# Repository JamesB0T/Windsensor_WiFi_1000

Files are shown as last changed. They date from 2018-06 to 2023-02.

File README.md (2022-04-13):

## The Windsensor WiFi 1000 is an OpenSource project to build a wind transducer for sailboats using 3D printer parts and an ESP8266 microcontroller

My wind transducer got damaged in winter 2017/2018 by a big storm in Netherlands. I needed a new transducer for my small sailboat. It is a Dehlya 22. At the same time I was looking for an interesting and useful project for my new 3D printer. At first I tried to build the hemispheric parts and the rotor. After successful 3D printing I was amazed about the good quality and mechanical precision. My printer is a low cost Chinese model JGAurora in prusa design. At this point I started my project with the windsensor and I designed all parts in 3D for my printer.

For designing I use the online CAD program [Onshape](https://www.onshape.com). It is easy, powerfull and innovative. You just need a PC and a web browser with 3D function (Web GL). You find my project under the term "windsensor". Copy it to your own workplace so you can view and modify the 3D model.

This windsensor is based on a [patent](Patents/US5231876.pdf) from Peet Bros Inc. The patent has expired and everyone can use it. The function is very simple using two reed magnet sensors to detect wind speed and wind direction.

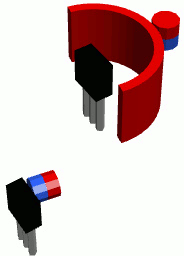
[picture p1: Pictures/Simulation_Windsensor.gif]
Mechanical Function


I modified the circuit and used two hall sensors instead. An ESP8266-E12 microcontroller processes readings from both sensors and calculates wind speed and wind direction. The operating principle is amazingly simple and smart. It is a perfect combination of simplicity and effectiveness and poses an attractive task for the ESP8266 microcontroller.

If you like to help or consider this project useful, please donate. Thanks for your support!

Donate (https://www.paypal.com/cgi-bin/webscr?cmd=_s-xclick&hosted_button_id=5QZJZBM252F2L)

For a first impression see the videos:

[Live Windsensor](https://www.youtube.com/watch?v=ME7WqSQ8mfY) 

[Display data in OpenPlotter](https://www.youtube.com/watch?v=0nfqlGNmgYI) 

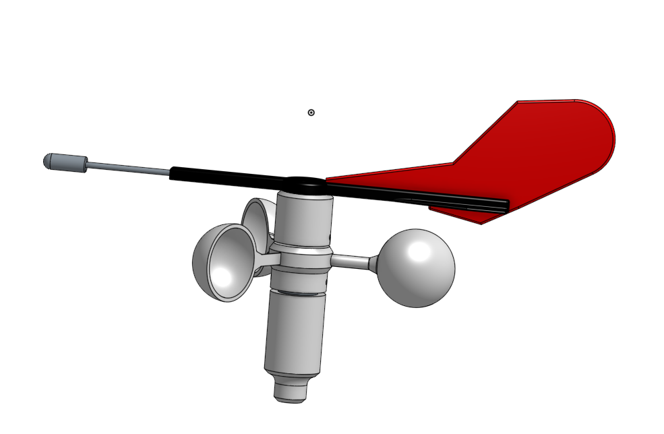
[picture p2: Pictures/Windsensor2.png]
Windsensor


I published and discussed this project in the German sailing forum [www.segeln-forum.de](https://www.segeln-forum.de/board1-rund-ums-segeln/board35-bootstechnik-und-elektronik/67401-windsensor-diy/) and found many interested people. Half a year later, all mechanical components and electrical schematics were completed and I successfully launched the first windsensor on my sailboat.

## These were the initial requirements for the new windsensor:

* Measuring wind speed and wind direction
* Robust mechanics
* Weight < 200g
* Small enough for a 22 feet sailboat
* Weatherproof and UV stable
* Visible by night
* No cabling for sensor signals
* Digital signal transmission with WiFi only
* 12V power supply utilizing top light power cable
* Using a ESP8266 for WiFi and data handling
* Update rate approx. 1...2 samples per second
* No onboard instrument required
* Visualisation in OpenPlotter via laptop, mobile fone or tablett
* No extra software required (display is the browser)
* Supporting  NMEA 0183 protocol
* Price < 250 Euro

## How can I use it?

I use the windsensor in combination with [OpenPlotter](http://www.sailoog.com/openplotter) on a Raspberry Pi 3B. OpenPlotter serves as access point for WiFi devices. The windsensor connects to OpenPlotter via WiFi and transmits the NMEA0183 data telegrams every second. The windsensor sends 4 types of telegrams. 3 standard telegrams (MWV, VWR, VPW) and one custom telegram (INF). Check here [link](http://www.nmea.de/nmea0183datensaetze.html) for more information on NMEA0183. 

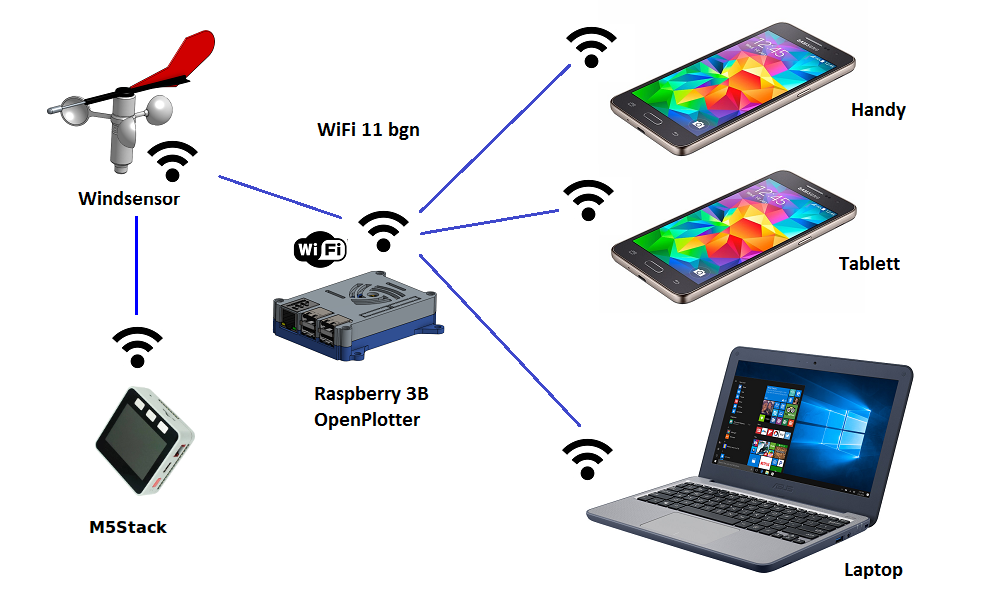
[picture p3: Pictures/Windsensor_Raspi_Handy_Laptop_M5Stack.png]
Connectivity


Network devices can be connected to OpenPlotter. A simple browser displays all data from the wind transducer. I use a 7" Android tablet as display for my windsensor.

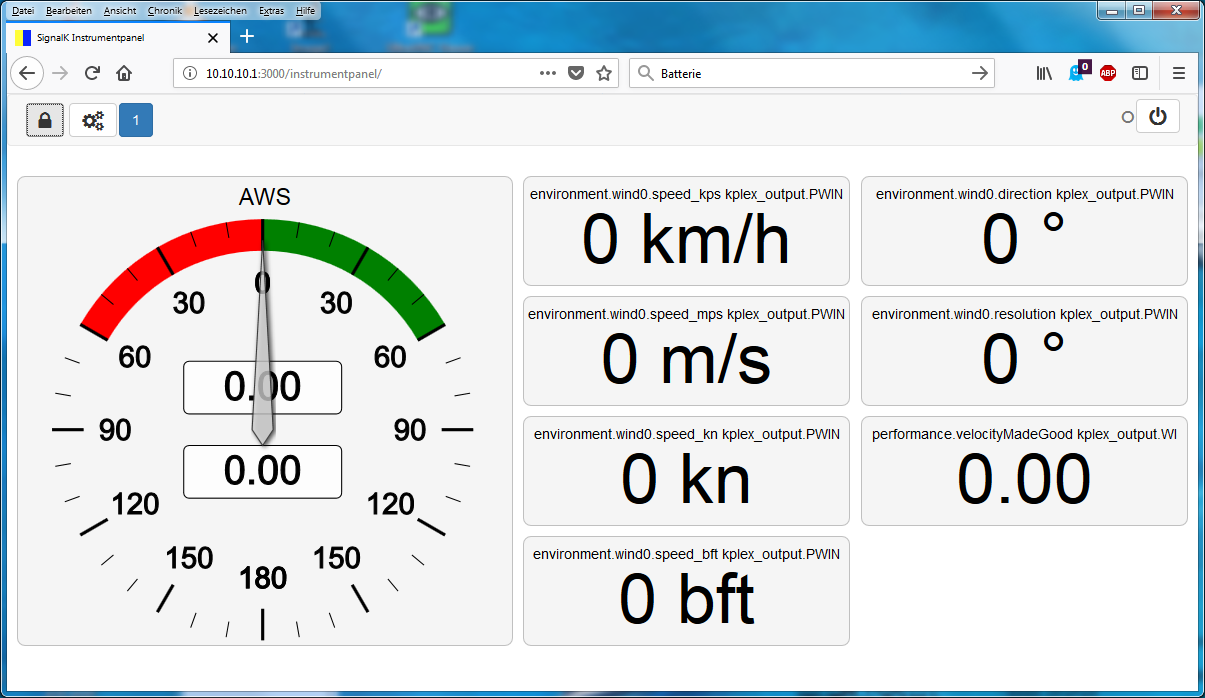
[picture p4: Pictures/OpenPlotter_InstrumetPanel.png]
Instrument panel


(2018-11-02) Now also available as Android App. It is is a WebApp connecting directly to the windsensor to display all data.

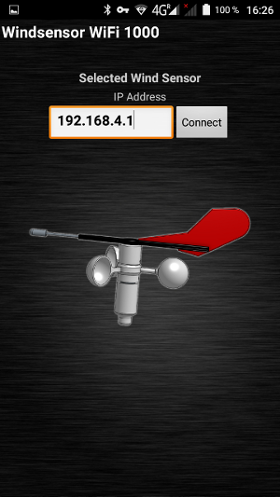
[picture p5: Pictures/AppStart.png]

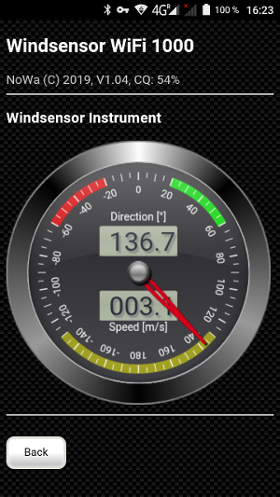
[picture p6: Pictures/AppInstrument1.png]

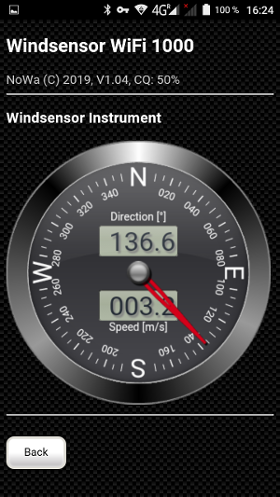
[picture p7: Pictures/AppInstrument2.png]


(2018-04-28) Now also a diagnostic tool is available for the correct setting of the aperture and the magnets. On Youtube is a short [video](https://youtu.be/b1kcvBv-9Fc) located in german language which describes the functions of the diagnostic tool.

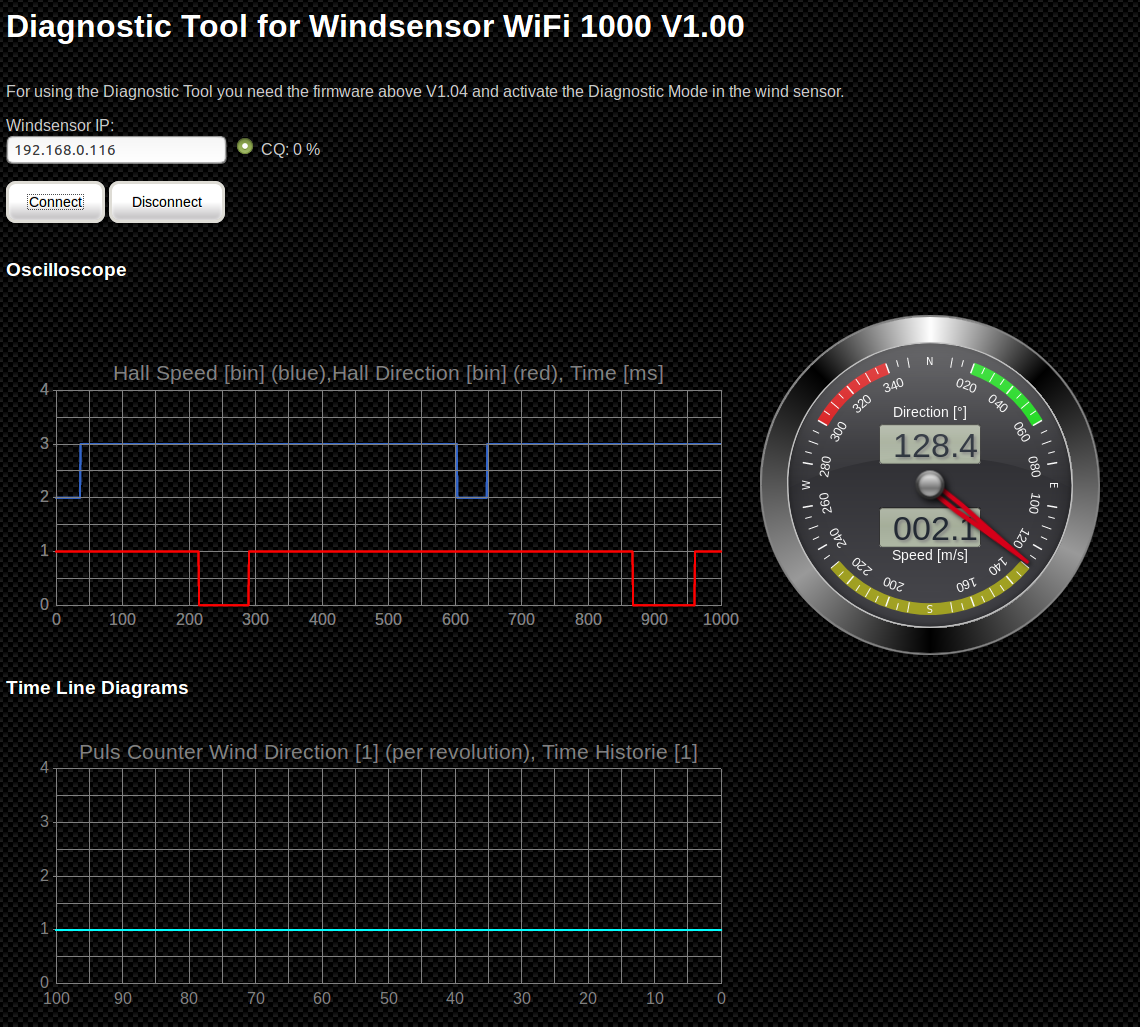
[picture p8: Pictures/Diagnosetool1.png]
Diagnostic Tool


(2019-06-24) Now is a French assembling instruction available. Thanks to Doninique Martin!

## What is the current status?

I have completed many tasks but still not everything is perfect so far.

- [x] Technical recherche
- [x] Evaluation of function
    - [x] Hall sensors
    - [x] Magnets
    - [x] Prototype circuit
    - [x] Test software
    - [x] Web display technologies
    - [x] 3D material test
    - [x] Coating tests
- [x] Mechanical design
    - [x] 3D parts
    - [x] Turning parts
- [x] Electronic design
    - [x] Circuit design
    - [x] Board design
    - [x] Customer sample circuit
- [x] Software
    - [x] Basic functionality
    - [x] NMEA0183 WiFi
    - [x] NMEA0183 Serial
    - [x] mDNS Service
    - [x] JSON
    - [ ] MQTT
    - [ ] Wind History Diagram
    - [x] Sensor Data Diagram for diagnostic and mechanical adjustment
    - [x] Web-Updater
    - [x] Web-Configurator
    - [x] Web server as data display
    - [x] Andoid App
    - [x] External Diagnostic Tool
	- [x] Support for other wind sensor types
- [x] Components ordering
    - [x] Electronic board
    - [x] Mechanical parts
    - [x] Turning parts
    - [x] Fittings
- [x] Prototyp creation
    - [x] White prototype
    - [x] Black prototype
- [x] Production Zero series
    - [x] DIY Kits
    - [x] Assembled windsensor
- [x] Shipping Zero Series
- [ ] Documentation
    - [x] Technical description
    - [x] Construction manual
    - [x] Part list
    - [ ] User manual
    - [x] Data sheet
- [ ] Application tests
    - [x] Temperature 20...80°C
    - [x] Vibration test by strong wind (8bft)
    - [x] WiFi stability test
    - [x] Connection test
    - [x] Rain test
    - [ ] IPX6 Water resistance test
    - [x] UV radiation test
    - [x] Long time test
    - [x] Test with auto pilot
    - [x] User experiences
- [ ] Extensions
    - [x] Multi function display with M5Stack
    - [x] NMEA2000 Gateway
    - [x] Weather data sensor with BME280
- [ ] Certification
    - [ ] CE Certification

## Questions?

For questions or suggestions please get in contact via email at norbert-walter(at)web.de.

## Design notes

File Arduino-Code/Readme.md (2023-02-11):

**20220906 firmware_V1.17.wsb {+ (stable) +}**

* Fix for calibration
* WLAN default settings (SSID: NoWa, Pass: 12345678, IP: 192.168.4.1)

**20220901 firmware_V1.16.wsb {+ (old) +}**

* Fix for negativ wind speed when using calibration
* Fix libs for compiling  with arduino IDE 1.8.19
* Modification for longer passwords with special character
* WLAN default settings (SSID: NoWa, Pass: 12345678, IP: 192.168.4.1)

**20220520 firmware_V1.15.wsb {+ (old) +}**

* Fix for wind direction offset (hanging values)
* Fix for calibration (eliminates negativ values to zero)
* WLAN default settings (SSID: NoWa, Pass: 12345678, IP: 192.168.4.1)

**20210910 firmware_V1.14.wsb {+ (old) +}**

* Support for new PCB for wind sensor Yachta
* 1Wire pin canged from GPIO15 to GPIO12 (new PCB)
* WLAN default settings (SSID: NoWa, Pass: 12345678, IP: 192.168.4.1)

{- Attention! No support for old PCB from Udo for wind sensor Yachta. -}

**20210827 firmware_V1.13.wsb {+ (old) +}**

* Support for modifyed wind sensor Ventus W132
* New values for device informations page
* New values for Wind Values page
* Support BME280 and DS18B20
* New NMEA0183 custom telegram WSE for BME280
* Solved problem for TCP telegram transmission (remove CR for unselected telegrams)
* WLAN default settings (SSID: NoWa, Pass: 12345678, IP: 192.168.4.1)

**20210819 firmware_V1.12.wsb {+ (old) +}**

* Secure function for autopilot (limit and reduce jumping measured values)
* WLAN default settings (SSID: NoWa, Pass: 12345678, IP: 192.168.4.1)

**20210811 firmware_V1.11.wsb {+ (old) +}**

* Fix for hanging I2C bus if the AS5600 is not present by WiFi1000 wind sensor
* Limit jumping direction values by using AS5600
* Rename the wind sensor types and add two new sensors:
	old: (NOWA1000|Udo1|Udo2)
	new: (WiFi1000|Yachta|Jukolein|Davis|Ventus)
* Using different speed calculations for different wind sensor types (radius)
* Using pictograms for wind values
* WLAN default settings (SSID: NoWa, Pass: 12345678, IP: 192.168.4.1)
* {- Needs new Android App! -}

{- Attention! After update changes all settings to default values. Please renew the settings. -}

**20210805 firmware_V1.10.wsb {- (critical) -}**

* Add two new wind sensor types ([Yachta](https://www.thingiverse.com/thing:2261719) and [Jukolein](https://github.com/jukolein/NMEA0183-Windsensor))
* WLAN default settings (SSID: NoWa, Pass: 12345678, IP: 192.168.4.1)

**20210501 firmware_V1.09.wsb {+ (old) +}**

* CPU speed changed from 80 MHz to 160 MHz for more performance
* nDNS service added for NMEA0183 ZeroConfig with AVnav
* Hostmane support fixed
* WLAN default settings (SSID: NoWa, Pass: 12345678, IP: 192.168.4.1)

{- Attention! After update changes all settings to default values. Please renew the settings. -}

**20210325 firmware_V1.08.wsb {+ (old) +}**

* Downwind values now correct
* Diagnostic Mode fixed
* Average building fixed

**20200711 firmware_V1.07.wsb {+ (old) +}**

* Boot problem fixed by wind speed higher 4bft (Boot Loop)
* Elektronic tested until 180km/h wind speed with sysntetic signals
* Direction accuracy 10x improved. Now is accuracy by 1° for 12bft or 78kn wind speed
* Display problem fixed for negativ wind direction in Canvas Steel instrument
* New parameter added for WiFi channel setting (1...13)
* WiFi connections reduced from 4 to 2 clients for better performance 
* WLAN default settings (SSID: NoWa, Pass: 12345678, IP: 192.168.4.1)

{- Attention! After update changes all settings to default values. Please renew the settings. -}

**20200427 firmware_V1.06.wsb {+ (old) +}**

* Firmware update changed (GitLab download now available)
* For SSID special characters added (A..z, 0..9, _-)
* WLAN indicator for connection quality fixed
* WLAN default settings (SSID: NoWa, Pass: 12345678, IP: 192.168.4.1)

{- Attention! After update changes all settings to default values. Please renew the settings. -}

**20190928 firmware_V1.05.wsb {+ (old) +}**

* Using the actual Espressif SDK 2.2.1(cfd48f3)
* Restart now available via Web configuration
* Firmware update changed (GitLab download has been removed)
* New feature! Added a new calibration function for wind speed
* New feature! Added password for configuration pages (default: 12345678)
* WLAN default settings (SSID: NoWa, Pass: 12345678, IP: 192.168.4.1)
* Diagnostic Mode fixed (No connection and answare from wind sensor by using newer web browser)

{- Attention! After update changes all settings to default values. Please renew the settings. -}

**20190428 firmware_V1.04.wsb {+ (old) +}**

* Reset start values for speed and direction after reboot (eleminate start spikes)
* Link problem in HTML error page 404 solved
* JSON string for ServerMode fixed (before string, after int)
* New feature! Oscilloscope function included
* New JSON device created for oscilloscope data sending
* Diagnostic Mode activated (starts the oscilloscope function, usable with external Diagnostic Tool)
* Pulse Counter added in Device Info page (count the pulse per revolution for the direction Hall sensor)
* New complex instrument added when true wind selected (instrument with full degree scale and cardinal points, without sections, useful for Weather Station Mode)

**20190424 firmware_V1.03.wsb {+ (old) +}**

* Fixing the wind speed problem by slow winds
* Fixing the wind speed problem for bft unit (uncorrect calculation)
* Fixing the wind speed problem for m/s and km/h in Demo Mode (missing values)
* Fixing WLAN connection quality for Demo Mode (if no connection then uncorrect values )
* Adding in Web configuration a new parameter "Connection Timeout" (solved the start problem with OpenPlotter)
* Styling changed in page "Settings"

{- Attention! After update changes all settings to default values. Please renew the settings. -}

**20190220 firmware_V1.02.wsb {+ (old) +}**

* Blinking text in demo mode fixed (red syle)
* Individual help text depends on firmware version

**20190220 firmware_V1.01.wsb {+ (old) +}**

* Problem with average setting solved (now updating directly)
* Average value 10 now usable
* Info message in Demo Mode for Instrument page and Device Info page
* Offset for wind direction inserted (new feature)
* Two step update not more necessary
* Any english messages changed

**20190217 firmware_V1.00.wsb {+ (old) +}**

* First actual firmware V1.00
* Critical WLAN settings solved (now checking all input values)
* Implement online update function via GitLab
* SSID: MyBoat
* Pass: S6587rr94P

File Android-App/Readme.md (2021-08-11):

**20210811 Windsensor_WiFi_1000_6.apk {+ (stable) +}**

* Necessary from firmware V1.11 (different device name)

**20190205 Windsensor_WiFi_1000_5.apk {+ (stable) +}**

* If the App running then disable the display timeout

**20190205 Windsensor_WiFi_1000_4.apk {+ (old) +}**

* Checking the type of connection (is this a wind sensor)
* Reading the device type from JSON
* Open the following page only if detect a wind sensor
* Error handling by incorrect connections (messaging)

**20190205 Windsensor_WiFi_1000_3.apk {+ (old) +}**

* Added a settings page with IP selection
* Saving the last IP in a data base
* No error handling implemented

**20190205 Windsensor_WiFi_1000.apk {+ (old) +}**

* First App version with fix connection to norbert-walter.dnshome.de
* Usable only for Demo Software
* No error handling implemented

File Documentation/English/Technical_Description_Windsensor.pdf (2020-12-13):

# Technical Description

# Windsensor WiFi 1000

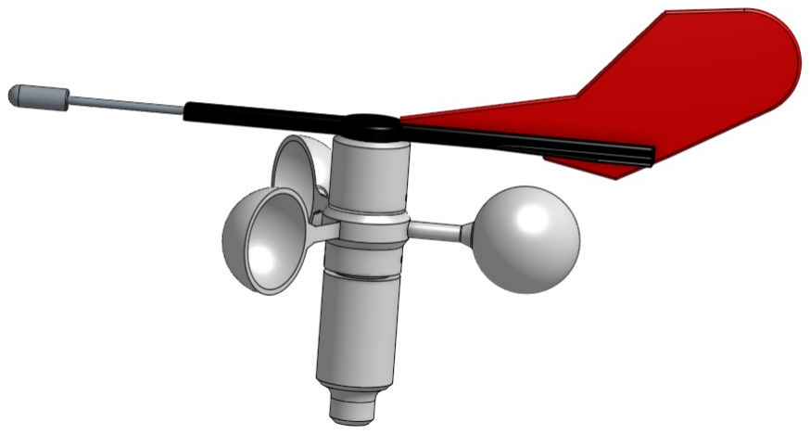
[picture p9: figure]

NoWa | Technical Description - Windsensor WiFi 1000
2/15 | Vers.: November 2020
Creator | Norbert Walter Wiesbadener Str. 1 40225 Düsseldorf Germany norbert-walter@web.de

© The Technical Description is subject to the Creative Common License.

Technical Description - Windsensor WiFi 1000 | NoWa
Vers.: November 2020 | 3/15

### Inhalt

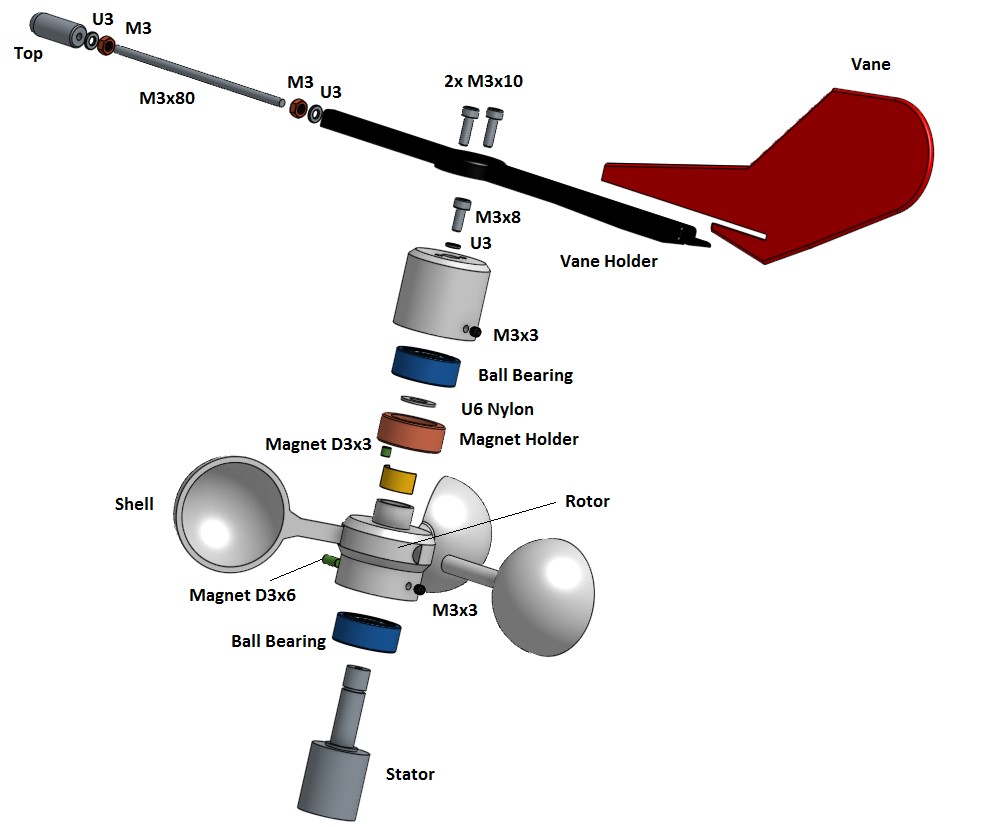
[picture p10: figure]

4/15 | Vers.: November 2020

## 1 Windsensor WiFi 1000

### 1.1 Preliminary remark

The wind sensor was developed as part of an open source project with the participation of many active sailors of the german sailing forum www.segeln-forum.de. The wind sensor is not in direct competition with commercial products. The primary objective was to test the technical possibilities of new technologies such as 3D printing in combination with innovative electronic components such as the ESP8266 6) and to implement them in a meaningful product. The technical functional principle was taken from the patented wind sensor of Peet Bros and adapted to the technical requirements. The patents 2,3) have expired, so the functional principle may be used by the general public. It is a safe and simple functional setup requiring just a few components. The Do It Yourself idea was in the foreground. An attempt was made to design a wind sensor which can be assembled by technically interested people themselves, meeting the sailing requirements with regard to function and accuracy. Only components easily available on the market were used. All technical documents and software components have been published so that modifications and improvements can be made at any time.

### 1.2 Description of functions

The wind sensor is a shell anemometer 4) and is used to measure wind direction and wind speed on boats. Both, wind direction and wind speed are measured by one Hall sensor each.

Fig.: Explosion view wind sensor (upper part)

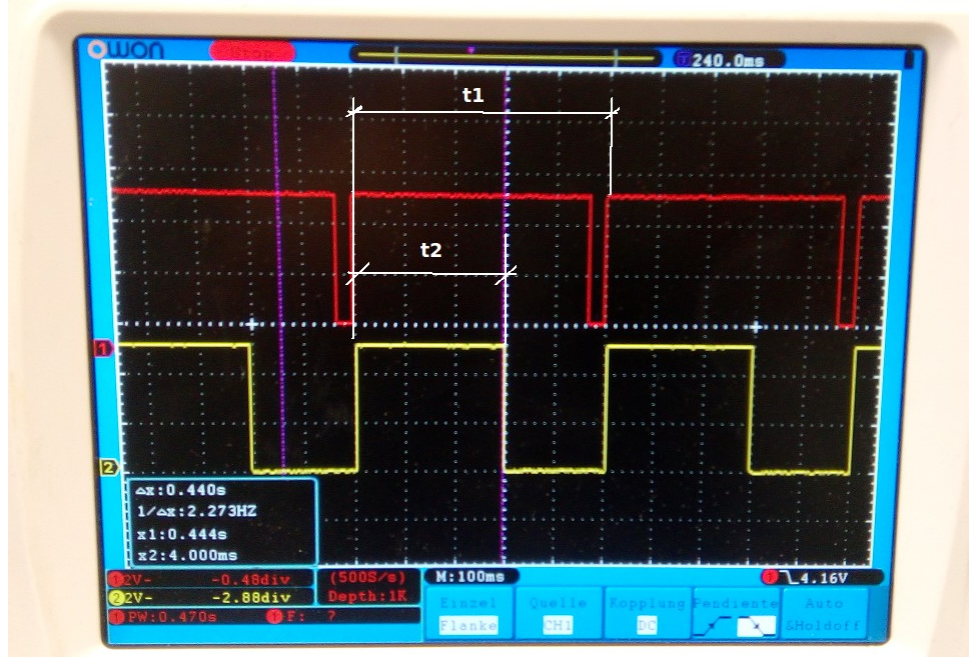
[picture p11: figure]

Vers.: November 2020 | 5/15

Magnet 1 is mounted on the shell wheel’s rotor and circles around the Hall sensor once per revolution, generating a pulse. The circulation time t1 is determined by interrupt-controlled time measurement. From this the revolution speed n for the rotor can be calculated. According to theory, the wind speed can be determined via the drag coefficient 5) of a shell anemometer. The following formula shows the relationship:

Lamda (λ) is the drag coefficient and represents a constant that depends on the type of the shell wheel (number and shape of the shells). The number for a typical 3-leaf anemometer is between 0.3 and 0.4. For the wind sensor, the value 0.3 is used. It represents reality fairly accurately. In comparison with a Windmaster 2, both devices agree when this value is used. The friction of the bearings plays almost no role. Knowing the radius r of the shell wheel, the wind speed v can be calculated with the help of the rapid running coefficient. The shell anemometer is a resistance runner, since the receding shell slows down the rotational movement. The shell wheel rotates solely due to the different air resistance values of the rear and front side of the shell. The speed only depends on the structure of the shell wheel. The friction of the bearings only determines the wind speed at which the shell wheel begins to rotate (breakaway torque of the ball friction in the bearing). Good devices with sapphire needle suspension start from 0.5 m/s, the wind sensor presented here approximately at 1...1.2 m/s.

Fig.: Time signal characteristics of the Hall sensors (red wind speed, yellow wind direction)

Determination of wind direction is quite smart. According to the patent, and this is the special thing about it, the wind direction is determined with just two digital sensors. Magnet 2 on the wind vane aligns itself according to wind direction and the rotating shell wheel leads a magnetic diaphragm past the wind vane magnet shielding the magnetic field of Hall sensor 2 for wind direction measurement. The wind direction can be calculated over time span t2. The time t2 varies between 0 and t1 depending on wind direction. However, this also means that the wind direction can only be determined when the shell wheel rotates. This is of no further concern, because the wind direction is not relevant if there is no wind. The only shortcome is that (with wind speed increasing), the accuracy of the wind direction determination will decrease, since less time is available to determine the time of t1 and t2 with timer ticks. ESP8266 just provides a millisecond timer, which increments a counter every millisecond to determine the time of t1 and t2 in ms. At wind force 12 bft (140km/h) the shell wheel rotates at about 1800 rpm. That leaves only 30 ms (or 30 counts) to determine the time per revolution. This decreases accuracy of the time determination of t1 and t2. The operating parameters table shown in the appendix illustrate this relationship. However this effect may be considered less significant, since increasing wind force will decrease the need for super accurate wind direction readings.

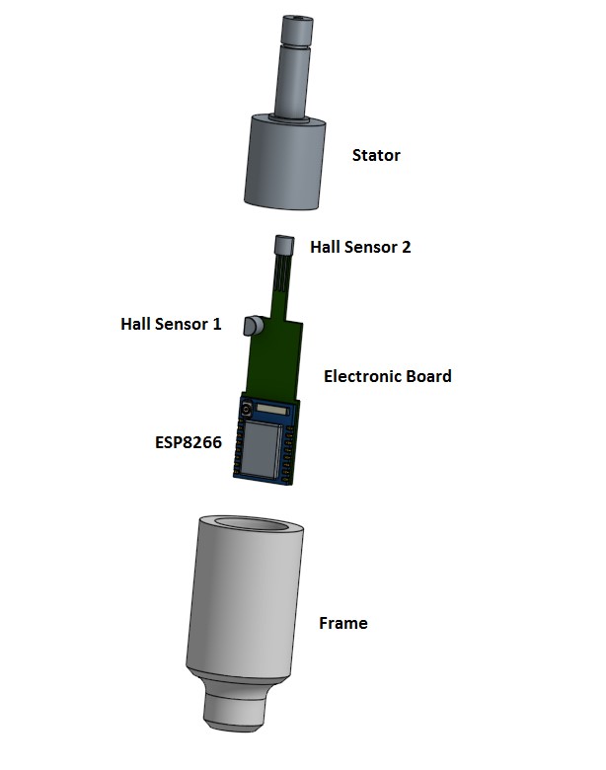
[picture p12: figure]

6/15 | Vers.: November 2020

Fig.: Explosion view wind sensor (lower part)

There is a circuit board in the stator for signal evaluation. The board contains the Hall sensors, the mini embedded module ESP8266 6), the control electronics and the power supply. The Hall sensors generate digital signals as the magnets pass by. These are detected and evaluated by the ESP8266. The ESP8266 is a highly-miniaturized minicomputer with WLAN module that can be programmed in C and other programming languages. In the Arduino development environment 8), all components for the ESP8266 are already integrated, so a large number of software libraries can be conveniently accessed for programming. The board is compatible with the Wemos D1 mini 7) embedded module and has the programming logic already integrated on the board. With a serial USB converter for 3.3V logic level, the ESP8266 can be easily programmed via the Aduino IDE. The board provides 6 connectors for programming and power supply.

The wind sensor can automatically send wind data to an existing WLAN network and act as a permanent member of the network. If application software such as OpenPlotter ¹⁴⁾ is active in the same network, the wind sensor measurement data can be read and displayed by OpenPlotter. The main data protocol used is NMEA0183 10). However, other protocols are also available. Basically, any software like OpenCPN 15), AvNav 16) and others can be used for data evaluation as long as it can read and process NMEA0183 data records via network (see Appendix: Software Compatibility List). Please note that only one network participant can be connected to the wind sensor at a time. Multiple connections to the wind sensor are not possible. However, OpenPlotter can be used to output the wind sensor data to multiple participants at the same time.

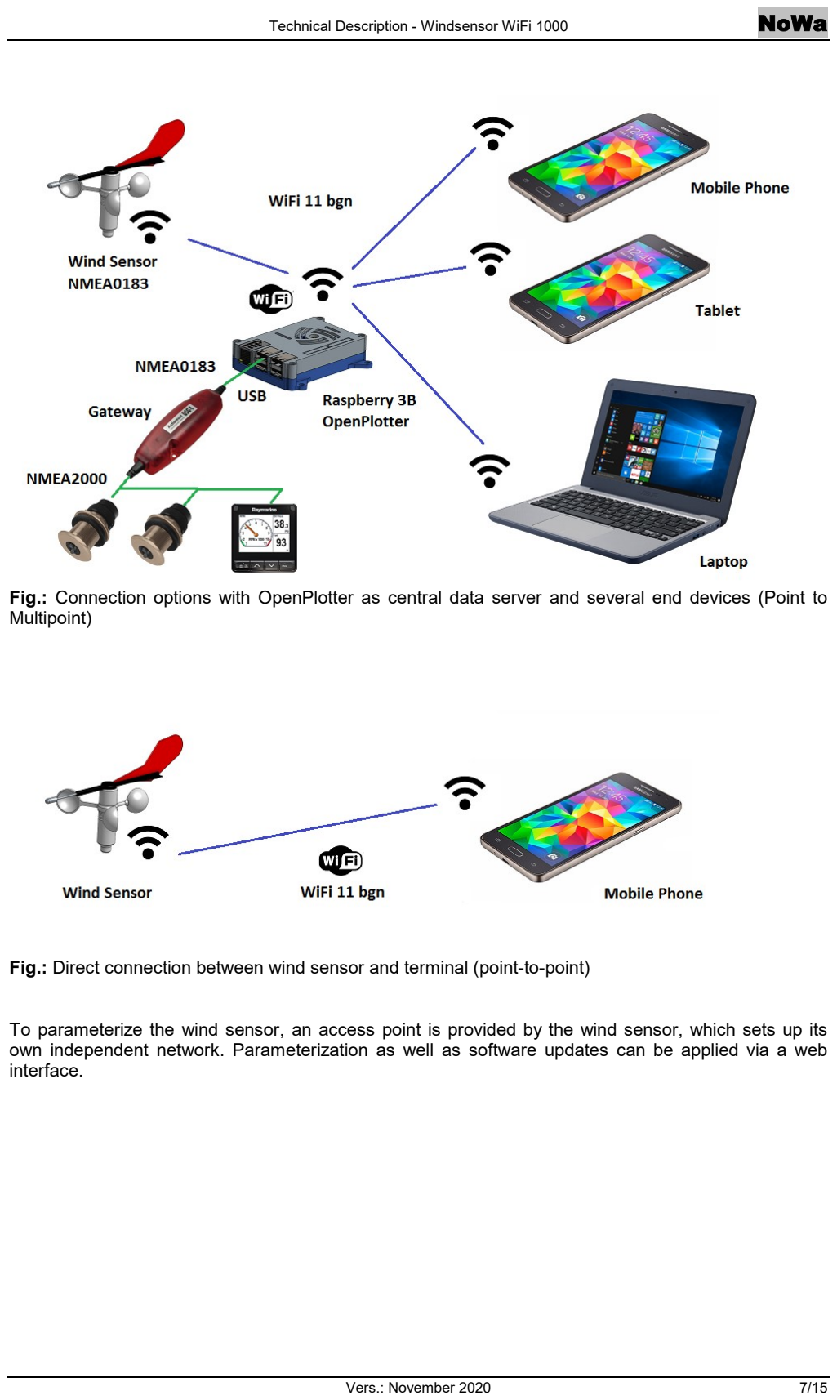
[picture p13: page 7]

Vers.: November 2020 | 7/15

Fig.: Connection options with OpenPlotter as central data server and several end devices (Point to Multipoint)

Fig.: Direct connection between wind sensor and terminal (point-to-point)

To parameterize the wind sensor, an access point is provided by the wind sensor, which sets up its own independent network. Parameterization as well as software updates can be applied via a web interface.

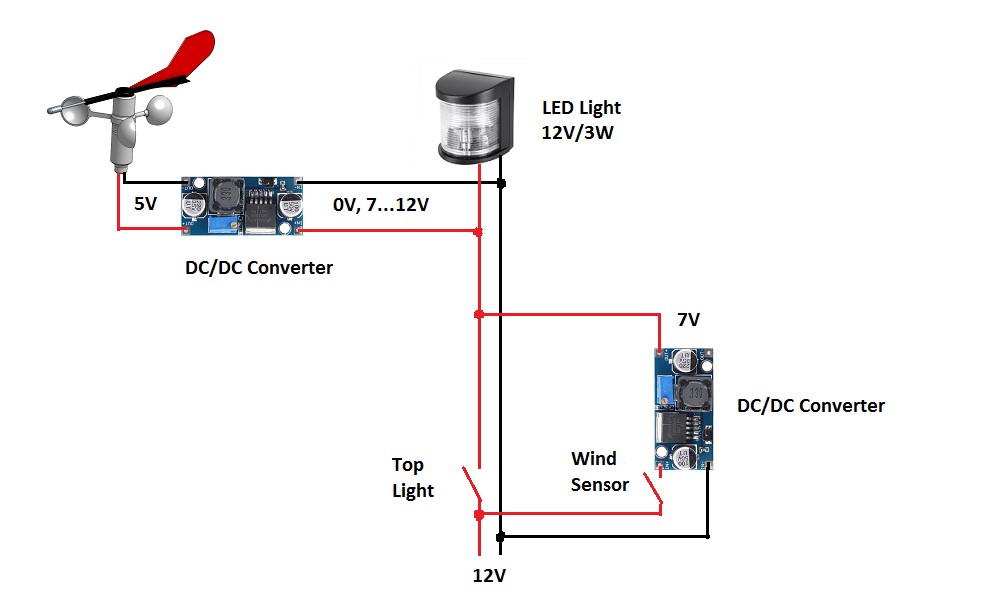
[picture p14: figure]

8/15 | Vers.: November 2020

Fig.: Power supply via the top light in the mast

Power supply of the wind sensor does not require a separate cable in the mast. You can take the power from the top light to supply the wind sensor. By means of a step down DC/DC converter, the sensor operates in the range between 7V...12V. If a LED bulb serves as top light, a reduced input voltage of ~7V can be used to ensure that just the wind sensor is powered on while the LED lamp remains unlit. If you want both to work, you just have to apply a voltage of 12V. So the wind sensor can be installed in existing systems without major conversions and extensions.

Vers.: November 2020 | 9/15

### 1.3 Technical Data

Designation | Value / Range of values | Comment
Wind speed | 0…40 m/s, 0…78 kn
Start wind speed | 1 m/s
Wind direction | 0…360°
Resol. wind direction | 0.3…6° at 0…40kn
Type of function | magnetic, Hall sensor
Ambient temperature | 0…60°C
Storage temperature | -10…80°C
Air Humidity | 0…100%
Power supply | 5V | reversed polarity protection
Consumption | 1W | typical
Data transmission | WiFi 11 bgn
Data rate | 3 Mbit
Range | app. 50 m | free field
Data protocols | NMEA0183 WiFi
| NMEA0183 serial | 3,3V logic level
| JSON WiFi | data transmission
| HTTP Access Point | for parameter settings
| TCP Socket | data connection
NMEA0183 Data types | MWV | details see appendix
| VWR
| VPW
| INF | custom Code
Tightness class | IP63 | protected against spray water
Dimensions L x W x H | 295 x 180 x 170 mm | without tube and base
Weight | 275 g | including tube and base
| 165 g | without tube and base
Plastic | PLA: enclosure parts | painted
Metal | Alu: stator, tube, base | seawater resistant
| V4A: tip, threaded rod
| V4A: screws, nuts
Approvals | none
Warranty | none
Licenses | CC-BY-NC-SA | hardware
| OpenSource, GPL 3.0 | software

10/15 | Vers.: November 2020

### 1.4 Installation and safety instructions

The wind sensor should be mounted on the mast so that there is sufficient distance to other components such as position lights, antennas or similar. Otherwise wind turbulences may occur and the measurement results may be compromised. Wind direction measurement is particularly affected by this. Basically, the wind sensor should be installed vertically on sufficiently dimensioned mounts. Due to swell and position, large forces can be transmitted to the wind sensor. Especially at high wind speeds, large torques and moments of inertia can occur at the rotor which are transmitted to the mounting foot.

Notes

Ensure that the wind sensor is perpendicular to the mast.

Dismantle the wind vane and shell wheel before mounting in order to avoid damage.

Assure the screws are properly tightened and secured against accidental loosening with threadlocking fluid.

There must be an electrical protector for overload (fuse) in the wind sensor supply line.

Protect electrical connections against moisture and provide a strain relief so that the dead weight of the cables in the mast is not transferred to the connecting cables.

Rust film can adhere to the magnets and impair the mobility of the components. The measured values may then be compromised.

If possible, protect the vane and shell wheel from frost and remove them before winter storage.

If the ship is heeling, the wind direction readings may be compromised.

Warning

The wind sensor is only a technical aid and must not be used in safety-critical areas. When coupled with autopilots, there is a risk of life and limb due to malfunctions. No liability is accepted for direct or indirect damage. The skipper must have the ability to control the ship at all times, even if the wind sensor fails.

In the event of collisions with the wind sensor, the device must be taken out of operation and inspected for damage. If necessary, damaged parts must be replaced. Only then it may be put back to operation.

The supply voltage of the wind sensor (at pins 1 and 6) must not exceed 6V. The sensor can be thermally destroyed during prolonged operation at 12V. Therefore, never connect the sensor directly to the 12V on-board power supply. A DC/DC converter must always be connected upstream.

Check the condition of all components of the wind sensor for damage at regular intervals, especially the plastic parts exposed to UV radiation. Immediately replace fragile plastic parts with new ones. There is a danger of falling components.

Do not overtighten the M10 screw on the mounting foot. There is a risk that the thread will break off.

Vers.: November 2020 | 11/15

### 1.5 Maintenance

The wind sensor does not require any special maintenance during operation. The sensor should be inspected at regular intervals. For this purpose, the wind vane and the shell wheel are removed and checked for impurities. In particular, flash rust can accumulate on the magnets and must be removed. The ball bearings must be checked for smooth running and low clearance. If necessary, the bearings can be cleaned with alcohol and lubricated with silicone oil. Brittle and cracked plastic parts must be replaced.

### 1.6 Disposal

At the end of its lifetime, the wind sensor can be dismantled into individual parts and sorted according to materials. The plastic and metal parts can be disposed of via the Dual Domestic Waste Disposal System.

The electronic circuit board must not be disposed of in the household waste and must be handed over to the local disposal company.

### 1.7 Licenses

The technical descriptions, schematics, design drawings and 3D models of the wind sensor called Works are subject to the Creative Commons (CC) License by-nc-sa. All works may be reproduced and modified for non-commercial purposes provided that the author is acknowledged. Derived works are subject to the same license and may not be otherwise licensed.

The software of the wind sensor is subject to GPLv3. The software is open source and can be duplicated, modified and distributed by anyone. The derived works are also subject to GPLv3. The full text of GPLv3 can be read in detail under at https://www.gnu.org/licenses/gpl-3.0.en.html

### 1.8 Disclaimer of liability

The entire construction of the wind sensor was carried out with great care and technical expertise. Under certain circumstances however the construction may not function properly. No liability can be accepted for damage, recourse or legal claims arising from this. A guarantee on functional safety is not given. The wind sensor is used by the user as it is.

12/15 | Vers.: November 2020

## 2 Appendix

### 2.1 Operating parameters

| | | | | | Angle
v | v | v | v | n | t | Resolution
[m/s] | [kn] | [bft] | [km/h] | [1/s] | [ms] | [°]
0 | 0.0 | 0.0 | 0.0 | 0.0
1 | 1.9 | 0.7 | 3.6 | 0.8 | 1256.6 | 0.3
2 | 3.9 | 1.3 | 7.2 | 1.6 | 628.3 | 0.6
3 | 5.8 | 1.8 | 10.8 | 2.4 | 418.9 | 0.9
4 | 7.8 | 2.3 | 14.4 | 3.2 | 314.2 | 1.1
5 | 9.7 | 2.7 | 18.0 | 4.0 | 251.3 | 1.4
6 | 11.7 | 3.2 | 21.6 | 4.8 | 209.4 | 1.7
7 | 13.6 | 3.6 | 25.2 | 5.6 | 179.5 | 2.0
8 | 15.6 | 4.0 | 28.8 | 6.4 | 157.1 | 2.3
9 | 17.5 | 4.4 | 32.4 | 7.2 | 139.6 | 2.6
10 | 19.4 | 4.8 | 36.0 | 8.0 | 125.7 | 2.9
11 | 21.4 | 5.2 | 39.6 | 8.8 | 114.2 | 3.2
12 | 23.3 | 5.5 | 43.2 | 9.5 | 104.7 | 3.4
13 | 25.3 | 5.9 | 46.8 | 10.3 | 96.7 | 3.7
14 | 27.2 | 6.2 | 50.4 | 11.1 | 89.8 | 4.0
15 | 29.2 | 6.5 | 54.0 | 11.9 | 83.8 | 4.3
16 | 31.1 | 6.8 | 57.6 | 12.7 | 78.5 | 4.6
17 | 33.0 | 7.1 | 61.2 | 13.5 | 73.9 | 4.9
18 | 35.0 | 7.4 | 64.8 | 14.3 | 69.8 | 5.2
19 | 36.9 | 7.6 | 68.4 | 15.1 | 66.1 | 5.4
20 | 38.9 | 7.9 | 72.0 | 15.9 | 62.8 | 5.7
21 | 40.8 | 8.1 | 75.6 | 16.7 | 59.8 | 6.0
22 | 42.8 | 8.4 | 79.2 | 17.5 | 57.1 | 6.3
23 | 44.7 | 8.6 | 82.8 | 18.3 | 54.6 | 6.6
24 | 46.7 | 8.9 | 86.4 | 19.1 | 52.4 | 6.9
25 | 48.6 | 9.1 | 90.0 | 19.9 | 50.3 | 7.2
26 | 50.5 | 9.4 | 93.6 | 20.7 | 48.3 | 7.4
27 | 52.5 | 9.6 | 97.2 | 21.5 | 46.5 | 7.7
28 | 54.4 | 9.8 | 100.8 | 22.3 | 44.9 | 8.0
29 | 56.4 | 10.1 | 104.4 | 23.1 | 43.3 | 8.3
30 | 58.3 | 10.3 | 108.0 | 23.9 | 41.9 | 8.6
31 | 60.3 | 10.6 | 111.6 | 24.7 | 40.5 | 8.9
32 | 62.2 | 10.8 | 115.2 | 25.5 | 39.3 | 9.2
33 | 64.1 | 11.1 | 118.8 | 26.3 | 38.1 | 9.5
34 | 66.1 | 11.4 | 122.4 | 27.1 | 37.0 | 9.7
35 | 68.0 | 11.6 | 126.0 | 27.9 | 35.9 | 10.0
36 | 70.0 | 11.9 | 129.6 | 28.6 | 34.9 | 10.3
37 | 71.9 | 12.2 | 133.2 | 29.4 | 34.0 | 10.6
38 | 73.9 | 12.5 | 136.8 | 30.2 | 33.1 | 10.9
39 | 75.8 | 12.8 | 140.4 | 31.0 | 32.2 | 11.2
40 | 77.8 | 13.1 | 144.0 | 31.8 | 31.4 | 11.5

Vers.: November 2020 | 13/15

### 2.2 Description NMEA data telegrams

MWV – Wind speed and wind direction

1 2 3 4 5 6
$--MWV,x.x,a,x.x,a*hh<CR><LF>

Field Number:
1) Wind direction, 0…360°
2) Type, R = Apparant wind, T = True wind
3) Wind speed
4) Unit wind speed, K/M/N
5) Status, A = Data valid
6) Checksum

VWR - Apperant wind direction and wind speed

1 2 3 4 5 6 | 7 8 9
$--VWR,x.x,a,x.x,N,x.x,M,x.x,K*hh<CR><LF>

Field Number:
1) Wind direction 0…180°
2) Wind direction left (L) / right (R)
3) Wind speed in kn
4) N = Unit knots
5) Wind speed in m/s
6) M = Unit m/s
7) Wind speed in km/h
8) K = Unit km/h
9) Checksum

VPW – Wind speed – measured parallel to wind

1 2 3 4 5
$--VPW,x.x,N,x.x,M*hh<CR><LF>

Field Number:
1) Wind speed in kn, "-" means downwind
2) N = Unit knots
3) Wind speed in m/s, "-" means downwind
4) M = Unit m/s
5) Checksum

14/15 | Vers.: November 2020

INF – Wind speed and wind direction (Custom Code)

1 2 3 4 5 6 | 7 8 9 10 11 12 1314 15

$--INF,0,x.x,D,x.x,D,x.x,M,x.x,K,x.x,N,x.x,B,A*hh<CR><LF>

Field Number:
1) Sensor number
2) Wind direction in 0…360°
3) D = Unit degree
4) Wind direction resolution in °
5) D = Unit degree
6) Wind speed in m/s
7) M = Unit m/s
8) Windspeed in km/h
9) K = Unit km/h
10) Wind speed in kn
11) N = Unit kn
12) Wind Speed in bft
13) B = Unit bft
14) Status, A = valid
15) Checksum

### 2.3 Software Compatibility List

Application Software | Connection | Operating Sytem | Comment
OpenPlotter | WiFi, serial, NMEA0183 | Linux, Raspi | can be used as gateway for other data networks
OpenCPN | WiFi, serial, NMEA0183 | Linux, Windows, Mac, Android, Raspi | universal
AvNav | WiFi, NMEA0183 | Linux, Android, Raspi
Navionics | WiFi, NMEA0183 | Android | only one connection possible
NvCharts | WiFi, NMEA0183 | Android | only one connection possible
WinGPS Marine | WiFi, NMEA0183 | Android, Windows | Full version, only one connection possible
Vaarkaart Friese Meren | WiFi, NMEA0183 | Android | Full version, only one connection possible
DKW Kartensoftware | WiFi, NMEA0183 | Android | Full version, only one connection possible

Vers.: November 2020 | 15/15

### 2.4 Additional Information

1) Segelforum: https://www.segeln-forum.de
2) Peet Bros US-Patent: https://patents.google.com/patent/US5231876A/en
3) Peet Pros EU-Patent: https://patents.google.com/patent/EP0514184A2/en
4) Anemometer basics: https://en.wikipedia.org/wiki/Anemometer
5) Drag Coefficient: https://en.wikipedia.org/wiki/Drag_coefficient
6) ESP8266: https://en.wikipedia.org/wiki/ESP8266
7) Wemos D1 mini: https://docs.wemos.cc/en/latest/d1/d1_mini.html
8) Arduino IDE: https://www.arduino.cc/en/Main/Software?
9) Raspberry Pi: https://www.raspberrypi.org/
10) NMEA0183 data telegrams: http://www.nmea.de/nmea0183datensaetze.html
11) 3D Online CAD System Onshape: https://www.onshape.com/
12) Creative Commons Lizenz: https://creativecommons.org/licenses/?lang=en
13) GPLv3: https://www.gnu.org/licenses/quick-guide-gplv3.en.html
14) OpenPlotter: https://openmarine.net/openplotter
15) OpenCPN: https://opencpn.org/
16) AvNav: http://www.wellenvogel.net/software/avnav/index.php

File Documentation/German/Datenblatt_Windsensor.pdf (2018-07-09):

# Datenblatt

# Windsensor WiFi 1000

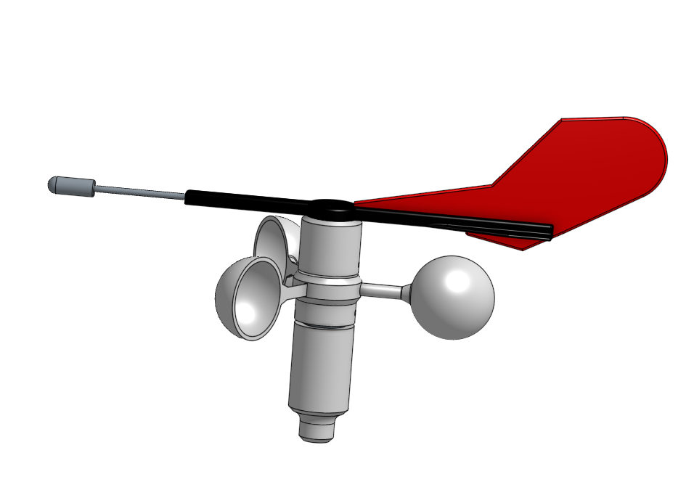
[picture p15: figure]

### Der Windsensor WiFi 1000 dient zur Anzeige der Windrichtung und der Windgeschwindigkeit. Die Datenübertragung erfolgt drahtlos über eine

WiFi-Netzwerkverbindung zu einer Zentraleinheit wie z.B. OpenPlotter.

Die Daten sind zu NMEA0183 kompatibel und unterstützen alle gängigen Telegramme. Eine direkte Anbindung und Anzeige der Daten über ein Handy oder Tablett mit handelsüblicher Navigationssoftware ist ebenfalls möglich. Der Windsensor benötigt lediglich eine kabelgebundene Stromversorgung, die von einem Toplicht abgegriffen werden kann. So

entfällt das aufwändige Verlegen eines Kabels im Mast.

### Durch die kompakte Bauweise sowie die rein digitale Signalverarbeitung ist der Windsensor vielseitig einsetzbar und durch die funkbasierte Datenübertragung störunempfindlich. Eine geeignete Materialauswahl und die Verwendung von robusten Industriekugellagern aus Edelstahl

ermöglichen einen geringen Verschleiß und eine lange Nutzungsdauer.

### Alle Fertigungsunterlagen sind öffentlich zugänglich und unterliegen OpenSource-Lizenzen, so dass im Störungsfall der Windsensor selbst repariert oder bei Bedarf nach eigenen Anforderungen erweitert werden

kann.

NoWa | Datenblatt – Windsensor WiFi 1000

# Technische Daten

Bezeichnung | Wert / Wertebereich | Bemerkung
Windgeschwindigkeit | 0740 m/s, 0778 kn
Start Geschwindigkeit | 1 m/s
Windrichtung | 07360°
Auflösung Windrichtung | 0,376° bei 0740kn
Funktionstyp | magnetisch, Hallsensor
Umgebungstemperatur | 0760°C
Lagertemperatur | -10780°C
Luftfeuchtigkeit | 07100%
Stromversorgung | 5V | verpolungssicher
Leitungsaufnahme | 1W | typisch
Datenübertragung | WiFi 11 bgn
Datenrate | 3 Mbit
Reichweite | ca. 50 m | im Freifeld
Datenprotokolle | NMEA0183 WiFi
| NMEA0183 seriell | 3,3V Logikpegel
| JSON WiFi
| HTTP Access Point | für Parametrierung
| TCP Socket | Datenverbindung
NMEA0183 Datentypen | MWV | Details siehe Anhang
| VWR
| VPW
| INF | Custom Code
Unterstützte Software | Linux | OpenPlotter, OpenCPN, AvNav
| Android | OpenCPN, AvNav, Navionics, WinGPS pro
| Windows | WinGPS
| Mac | Navionics
Dichtheitsklasse | IP63, IPX3 | gegen Sprühwasser geschützt
Abmessungen L x B x H | 295 x 180 x 170 mm | ohne Rohr und Fuß
Gewicht | 275 g | mit Rohr und Fuß
Kunststoff | PLA: Gehäuseteile | lackiert
Metalle | Alu: Stator, Rohr, Fuß | seewasserbeständig
| V4A: Spitze, Gewindestab
| V4A: Schrauben, Muttern
Zulassungen | keine
Garantie | keine
Lizenzen | CC-BY-NC-SA | Hardware
| OpenSource, GPL 3.0 | Software

Datenblatt – Windsensor WiFi 1000 | NoWa
Vers.: 09.07.2018 | 3/3
Ersteller | Norbert Walter
| Wiesbadener Str. 1 40225 Düsseldorf
| norbert-walter@web.de

© Die Technische Beschreibung unterliegt der Creative Common Lizenz

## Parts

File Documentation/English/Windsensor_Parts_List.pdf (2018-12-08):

Parts List Windsensor WiFi 1000
(C) Norbert Walter 2018
Position | Amount | Item | Material

Dokumentation
1 | 1 | Technical Description
2 | 1 | Assembly Instruction
3 | 1 | Setup Guide
4 | 1 | Board Circuit Diagram
5 | 1 | Cabling Diagram
6 | 1 | Parts List
7 | 1 | Software & Documentation (CD)

3D-Parts
8 | 3 | Cup | PLA
9 | 1 | Frame | PLA
10 | 1 | Cup Rotor | PLA
11 | 1 | Vane Rotor | PLA
12 | 1 | Vane Arm | PLA
13 | 1 | Vane Head | PLA
14 | 1 | Magnet Holder | PLA

Mechanical Parts
15 | 1 | Balance Weight | V4A Steel
16 | 1 | Stator | Aluminium
17 | 1 | Magnetic Shield | Tinplate
18 | 1 | Mounting Support | Aluminium
19 | 1 | Shim M10 | V4A Steel
20 | 1 | Washer M10 | V4A Steel
21 | 1 | Hexagon Nut M10 | V4A Steel
22 | 2 | Ball Bearing 608ZZ | V4A Steel
23 | 1 | Aluminium Pipe D10mm, 300 mm | Aluminium
24 | 1 | Threaded Rod M3x80 | V4A Steel
25 | 2 | Socket Cap Screw M3x8 | V4A Steel
26 | 1 | Socket Cap Screw M3x10 | V4A Steel
27 | 1 | Shim M3 | V4A Steel
28 | 2 | Washer M3 | V4A Steel
29 | 3 | Socket Set Screw M3x4 | V4A Steel
30 | 1 | Shim M6 | Nylon
31 | 1 | Magnet D3x6mm | Neodym
32 | 1 | Magnet D3x3mm | Neodym
33 | 1 | Reflective Film red | PVC
34 | 1 | Reflective Film white | PVC

Electronic Components
35 | 1 | Circuit Board, assembled incl. SW | FR4 1mm
36 | 1 | 8pol. Cable D5x 800 mm | CAT5e
37 | 2 | DC/DC-Converter

Parts List Windsensor WiFi 1000
(C) Norbert Walter 2018
Position | Amount | Item | Material

Assembly Aids
38 | 1 | Cleaning Alcohol
39 | 1 | Silicone Oil / Fine Oil
40 | 1 | Clear Coat for paintable Hard Plastics, e.g. Dupli-Color
41 | 1 | Acrylic Adhesive, e.g. Weicon RK-1300
42 | 1 | Adhesive Tape
43 | 4 | Q-Tip
44 | 1 | cable tie, width 4-6mm
45 | 1 | 9V Battery PP3
46 | 1 | Superglue | optional

Tools
47 | 1 | Tweezers
48 | 1 | Stanley Knive / Scalpel
49 | 1 | Hex Key Wrench M3
50 | 1 | Hex Key Wrench M2
51 | 1 | Spanner M5.5
52 | 1 | Spanner M17
53 | 1 | Spanner M22
54 | 1 | Fine Pliers
55 | 1 | Wirecutting Pliers
56 | 1 | Electronics Soldering Iron
57 | 1 | Tin Soldering Wire
58 | 1 | Screwdriver small
59 | 1 | Digital-Multimeter
60 | 1 | Desoldering Braid | optional
61 | 1 | Oscilloscope | optional

Software
62 | 1 | Firmware Windsensor | optional
63 | 1 | Arduino IDE V1.8.5 | optional
64 | 1 | Laptop/PC | optional
65 | 1 | USB/Serial Converter 3.3V | optional
66 | 1 | USB Cable | optional

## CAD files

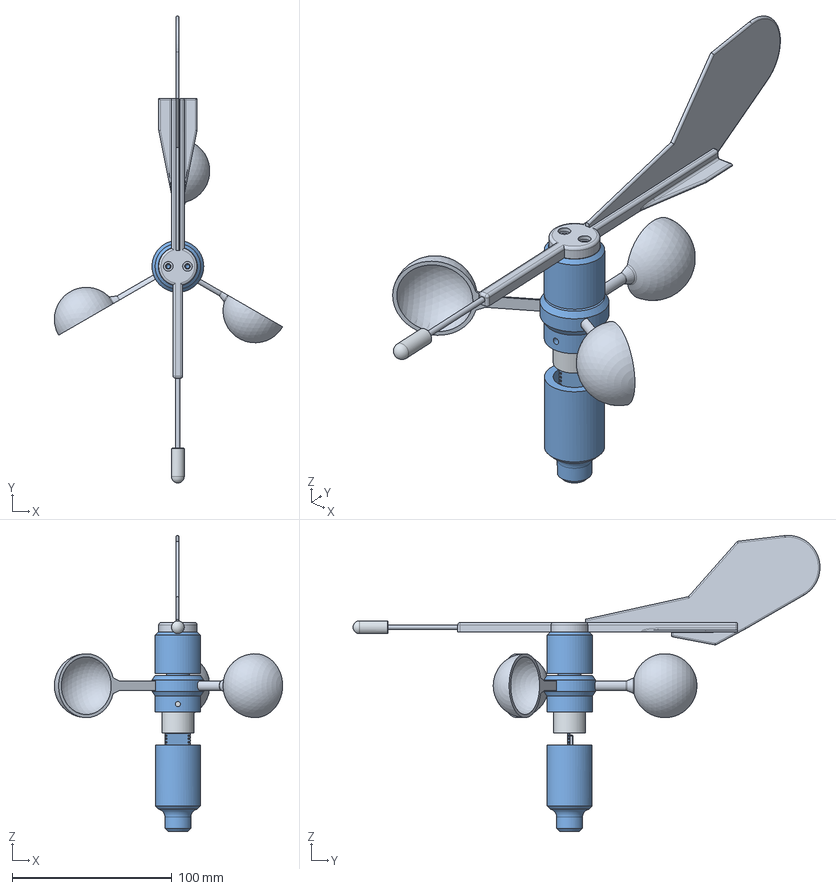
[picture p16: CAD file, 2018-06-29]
CAD-Files/3D-Parts/STEP/Windsensor.step
142.8 x 291.9 x 185.1 mm
Rotor
Stator
Vane Rotor
Hemisphere x 3
Frame
Vane
Vane Holder
Rod
Top
M-Holder
S-Holder
_623-RS1_PART1 x 2
_623-RS1_PART2 x 2
_623-RS1_PART3 x 14

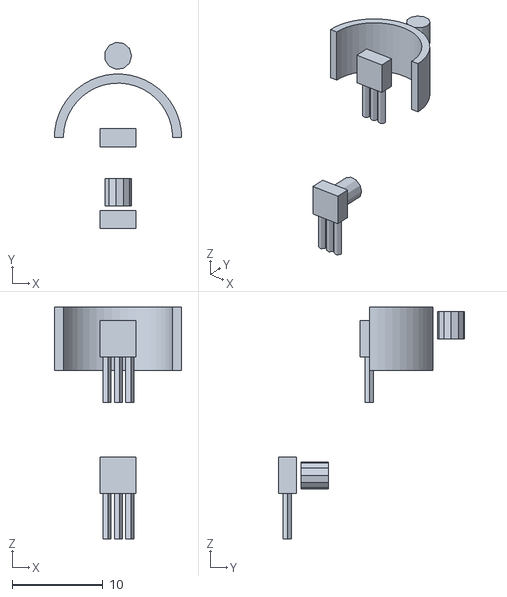
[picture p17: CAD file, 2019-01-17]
Simulation-Files/Mechanical Simulation/Simulation_Windsensor_BIN.stl
14.0 x 20.5 x 25.5

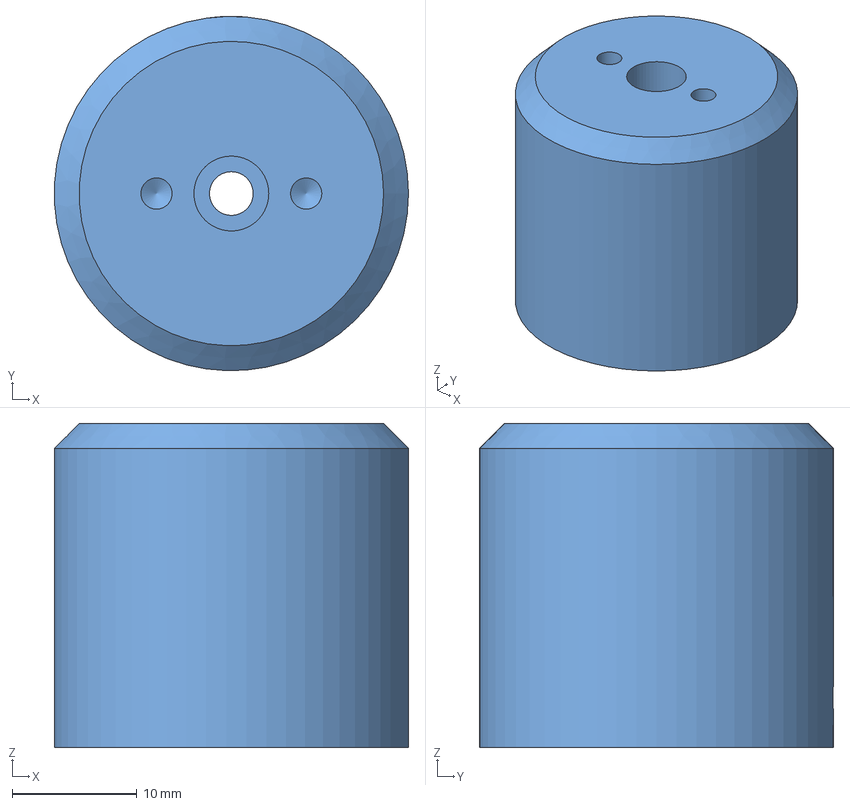
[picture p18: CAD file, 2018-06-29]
CAD-Files/3D-Parts/STEP/Vane Rotor.step
28.4 x 28.4 x 26.0 mm

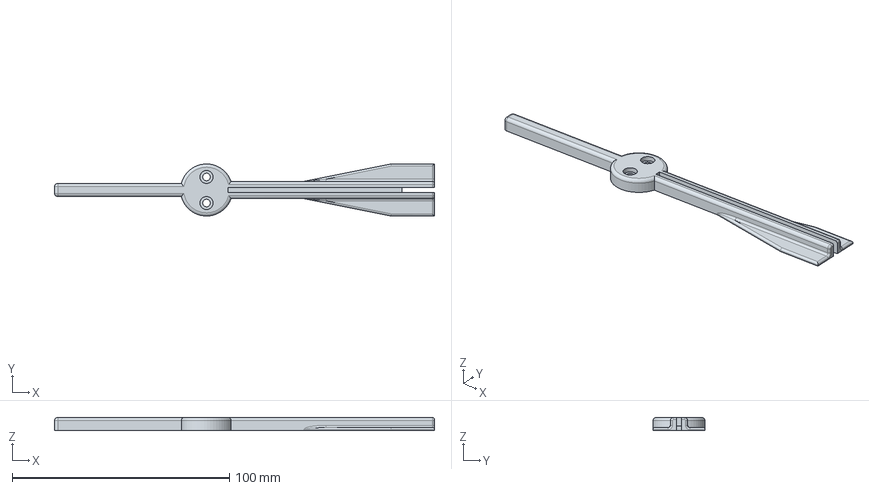
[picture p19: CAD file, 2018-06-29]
CAD-Files/3D-Parts/STEP/Vane Holder.step
175.0 x 24.0 x 6.00 mm

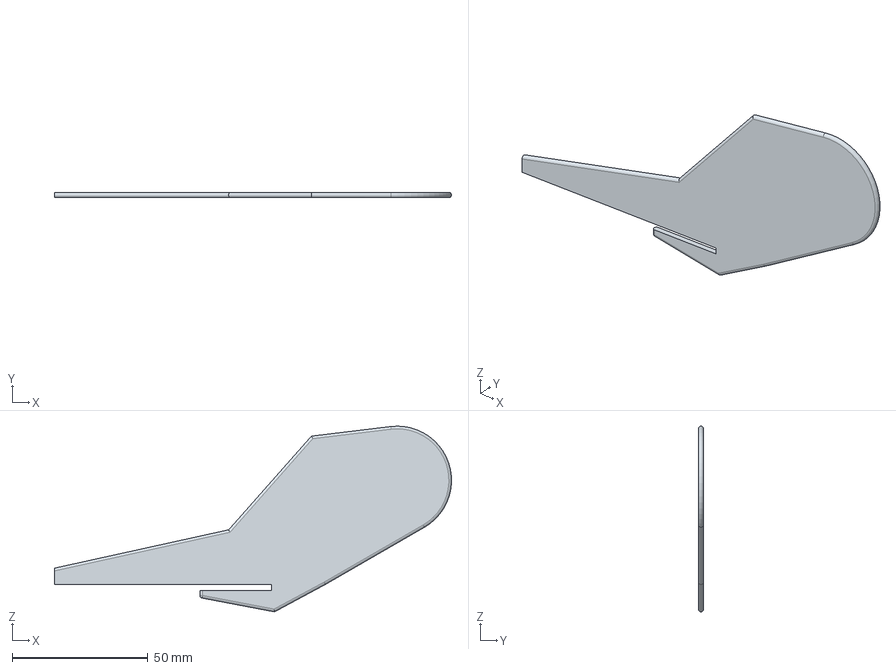
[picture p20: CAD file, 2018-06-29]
CAD-Files/3D-Parts/STEP/Vane.step
146.5 x 2.00 x 68.5 mm

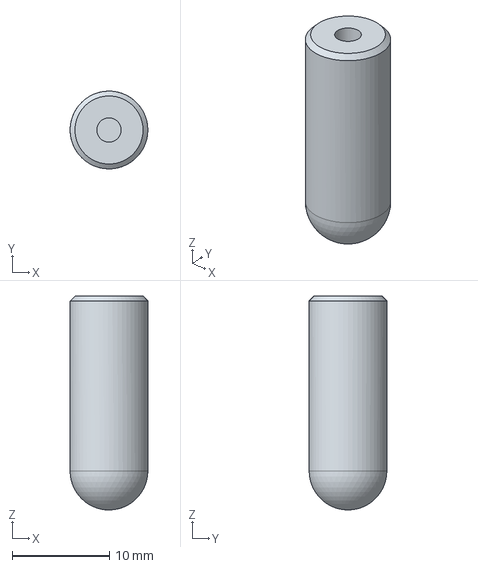
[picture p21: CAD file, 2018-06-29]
CAD-Files/3D-Parts/STEP/Top.step
8.00 x 8.00 x 22.0 mm

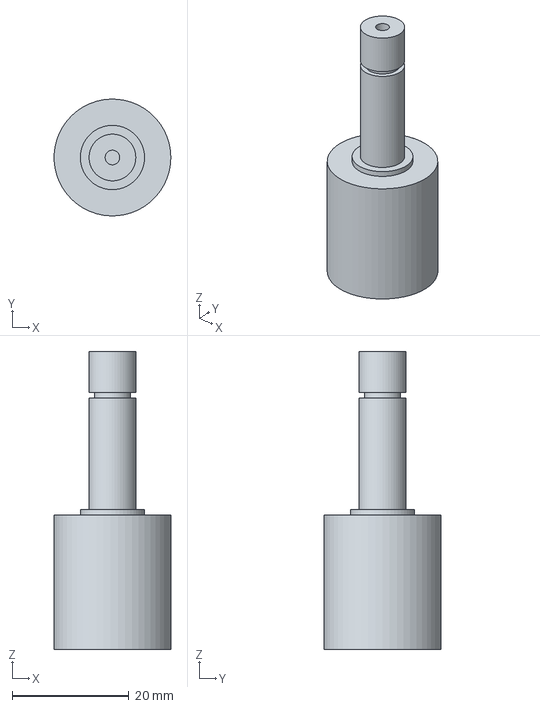
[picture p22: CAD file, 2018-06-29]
CAD-Files/3D-Parts/STEP/Stator.step
20.0 x 20.0 x 51.0 mm

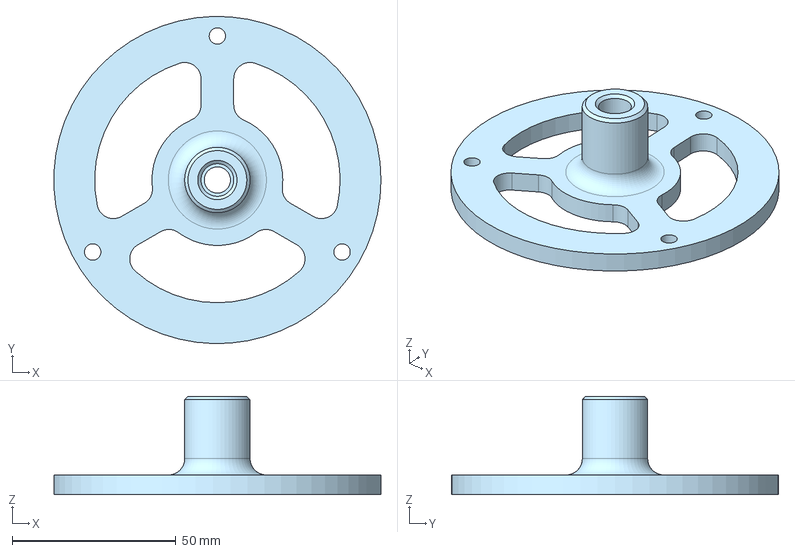
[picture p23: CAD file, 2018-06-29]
CAD-Files/3D-Parts/STEP/Sensor Holder.step
99.9 x 100.0 x 30.0 mm

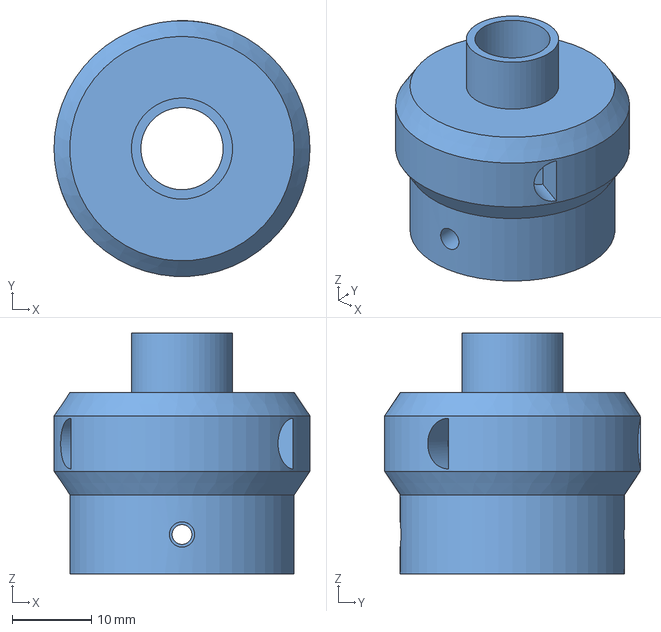
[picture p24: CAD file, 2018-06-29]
CAD-Files/3D-Parts/STEP/Rotor.step
32.4 x 32.4 x 30.5 mm

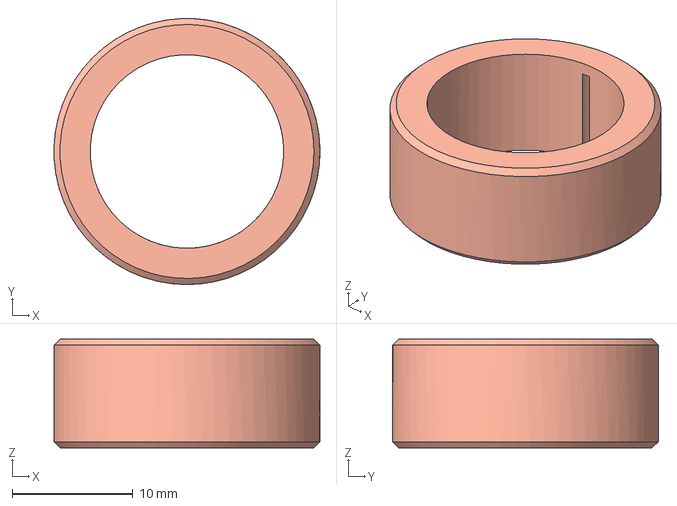
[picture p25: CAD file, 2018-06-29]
CAD-Files/3D-Parts/STEP/M-Holder.step
22.0 x 22.0 x 9.00 mm

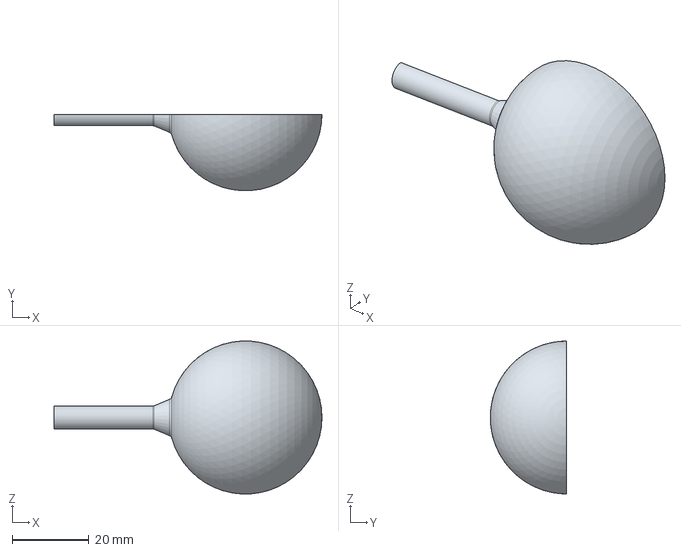
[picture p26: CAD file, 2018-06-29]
CAD-Files/3D-Parts/STEP/Hemisphere.step
70.0 x 20.0 x 39.9 mm

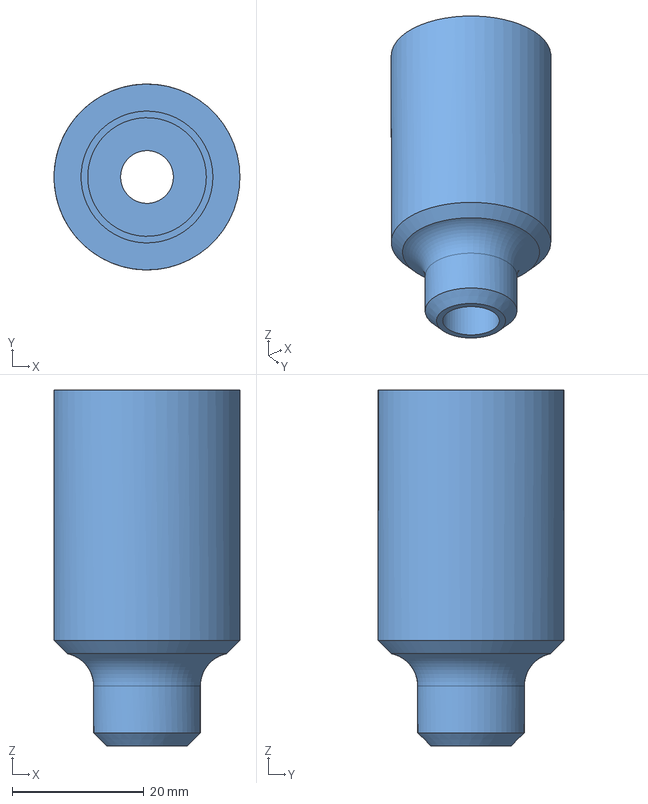
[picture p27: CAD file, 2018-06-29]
CAD-Files/3D-Parts/STEP/Frame.step
28.2 x 28.2 x 54.0 mm

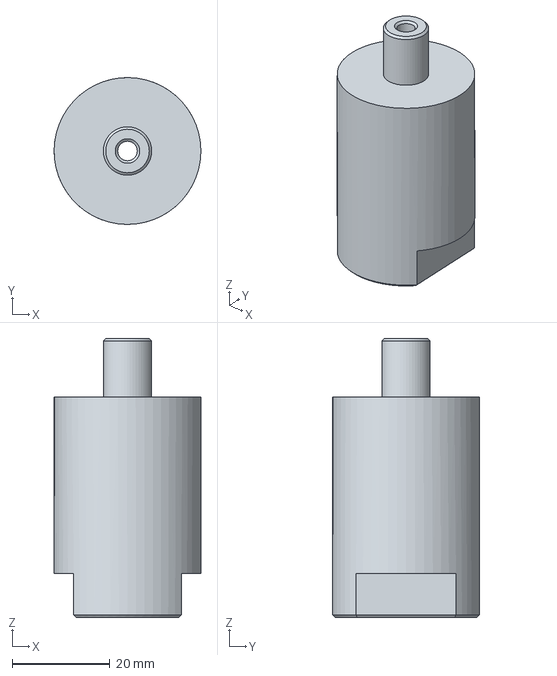
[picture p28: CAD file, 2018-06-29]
CAD-Files/3D-Parts/STEP/Base.step
30.0 x 30.0 x 57.0 mm

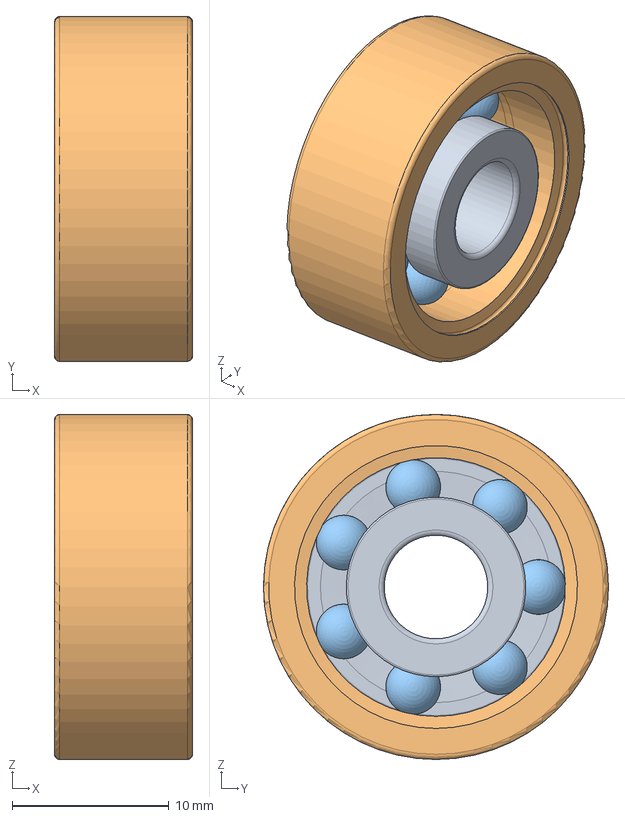
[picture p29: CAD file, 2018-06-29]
CAD-Files/3D-Parts/STEP/608ZZ.step
8.80 x 22.0 x 22.0 mm
_623-RS1_PART1
_623-RS1_PART2
_623-RS1_PART3 x 7

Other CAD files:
CAD-Files/3D-Parts/STL/Base.stl
CAD-Files/3D-Parts/STL/Frame.stl
CAD-Files/3D-Parts/STL/M-Holder.stl
CAD-Files/3D-Parts/STL/Rod.stl
CAD-Files/3D-Parts/STL/Rotor.stl
CAD-Files/3D-Parts/STL/Sensor Holder.stl
CAD-Files/3D-Parts/STL/Stator.stl
CAD-Files/3D-Parts/STL/Top.stl
CAD-Files/3D-Parts/STL/Vane Rotor.stl
CAD-Files/3D-Parts/STL/Vane.stl

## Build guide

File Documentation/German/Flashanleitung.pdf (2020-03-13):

# Flash-Anleitung

# Windsensor WiFi 1000

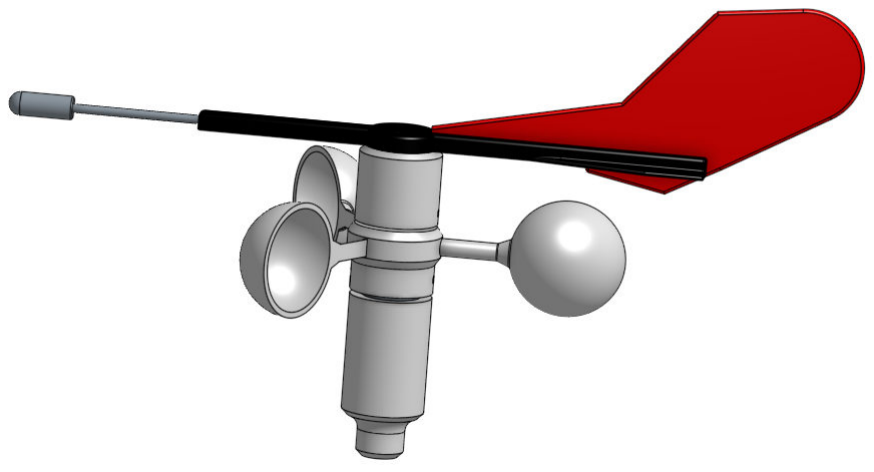
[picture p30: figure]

NoWa | Flash-Anleitung – Windsensor WiFi 1000
2/5 | Vers.: 13.03.2020
Ersteller | Norbert Walter
| Wiesbadener Str. 1 40225 Düsseldorf
| norbert-walter@web.de

© Die Technische Beschreibung unterliegt der Creative Common Lizenz

Flash-Anleitung – Windsensor WiFi 1000 | NoWa
Vers.: 13.03.2020 | 3/5

### Inhalt

NoWa | Flash-Anleitung – Windsensor WiFi 1000

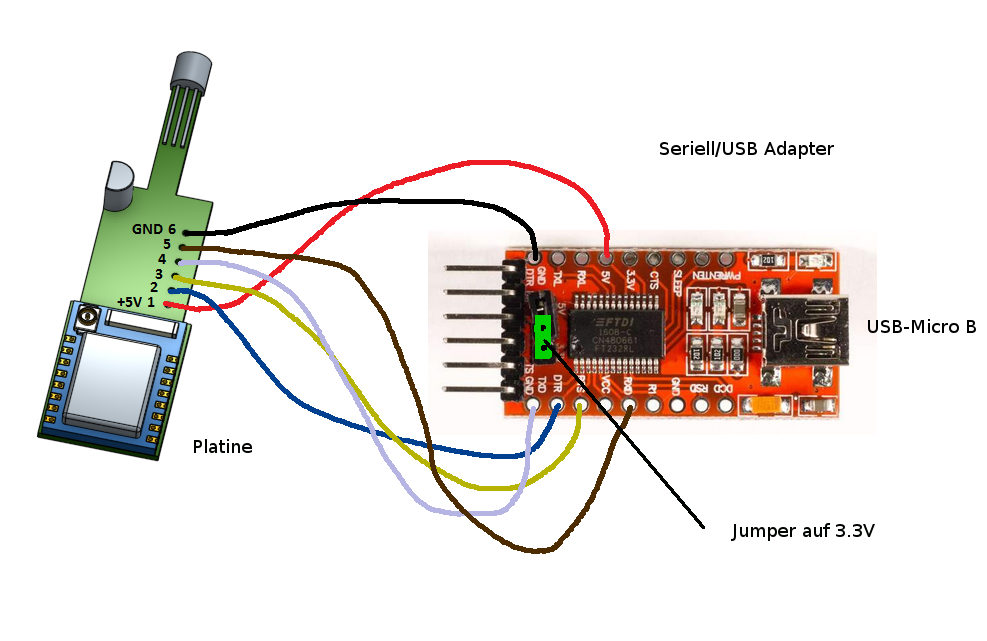
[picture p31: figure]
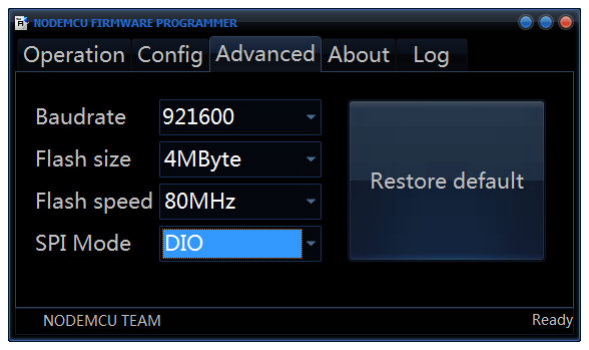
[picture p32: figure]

4/5 | Vers.: 13.03.2020

## 1 Firmware flashen

Falls es notwendig ist die Firmware des Windsensors zu flashen, dann kann dies über ein Seriell/USB-Adapter erfolgen. Es ist darauf zu achten, dass der Adapter 3,3V TTL-Signale verarbeiten kann und über folgende Anschlüsse verfügt:

Kürzel | Pin | Bedeutung
+5V | 1 | Versorgungsspannung 5V
DTR | 2 | Programmierung (Reset)*
RTS | 3 | Programmierung (Aktivierung Flashvorgang)*
TXD | 4 | Sendedaten*
RXD | 5 | Empfangsdaten*
GND | 6 | Masse
| | * Signalpegel 3,3V TTL

Der Adapter wird dann mit der Platine des Windsensors wie folgt verbunden.

Abb.: Anschluss des Programmieradapters

Die Datenübertragung erfolgt dann über die USB-Schnittstelle des Adapters. Zum Flashen der Firmware wird das Tool NodeMCU flasher benötigt, dass es leider nur für das Betriebssystem Windows als 32Bit und 64Bit Version gibt. Es kann unter dieser Adresse heruntergeladen werden:

https://github.com/nodemcu/nodemcu-flasher

Die EXE-Datei kann ohne spezielle Installation direkt gestartet werden. Als erstes werden unter Advanced folgende Einstellungen vorgenommen.

Danach wird unter Config die Firmwaredatei firmware_Vx.xx.wsb ausgewählt.

Flash-Anleitung – Windsensor WiFi 1000 | NoWa
Vers.: 13.03.2020 | 5/5

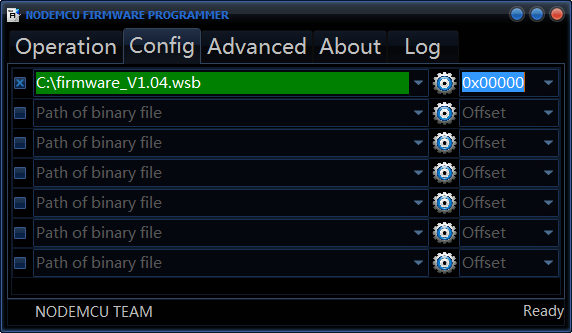
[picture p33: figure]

Zum Flashen geht man auf Operation und wählt die entsprechende Schnittstelle aus an der der Adapter angeschlossen ist. Danach drückt man auf Flash und wartet ab, bis die Firmware geladen ist.

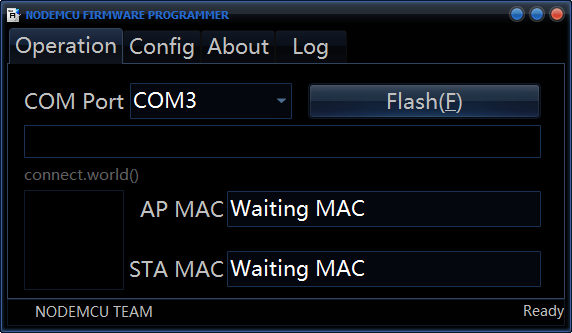
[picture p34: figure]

Während des Flashens wird der Fortschritt der Übertragung angezeigt.

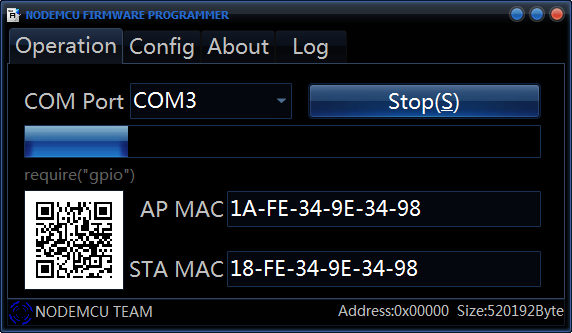
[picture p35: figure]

Wenn die Firmware erfolgreich geladen wurde ist folgender Bildschirm zu sehen.

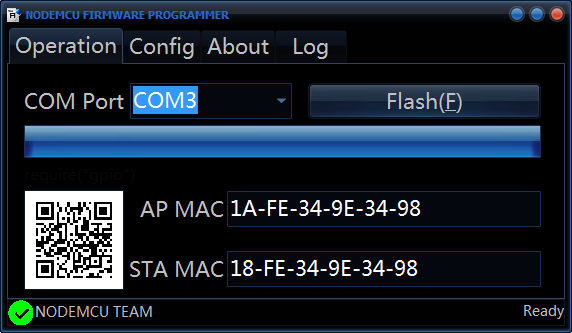
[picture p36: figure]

Nach der Übertragung kann das Programmiertool geschlossen und der Adapter abgezogen werden. Um die neue Firmware zu starten benötigt der Windsensor einen Reboot.

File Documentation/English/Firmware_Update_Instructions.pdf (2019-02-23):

# Firmware-Update-Instructions

The Windsensor boards delivered so far are operating at this firmware version:

NMEA_Windsensor_11_final_MyBoat.bin (https://gitlab.com/norbertwalter67/Windsensor_WiFi_1000/blob/master/Arduino-Code/NMEA_Windsensor_11_final_MyBoat.bin)

This firmware version is limited to WiFi communication at fixed network settings. There is a built in webinterface for updating the firmware, however due to bugs it can only be accessed under specific conditions. This document describes the steps required to update your windsensor’s firmware. After updating the same network parameters will apply as with the previous firmware.

## Required Tools:

- Raspberry Pi or wireless router
- Any personal computer, laptop or mobile phone linked to the internet and running a HTML-browser

### 1. Setup a wireless network on either your Raspberry Pi or wireless

router (e.g. FritzBox) with following parameters:

SSID: MyBoat
Password: S6587rr94P

### 2. Attach Windsensor to an appropriate source of power (use DC/DC-

Wandler!)

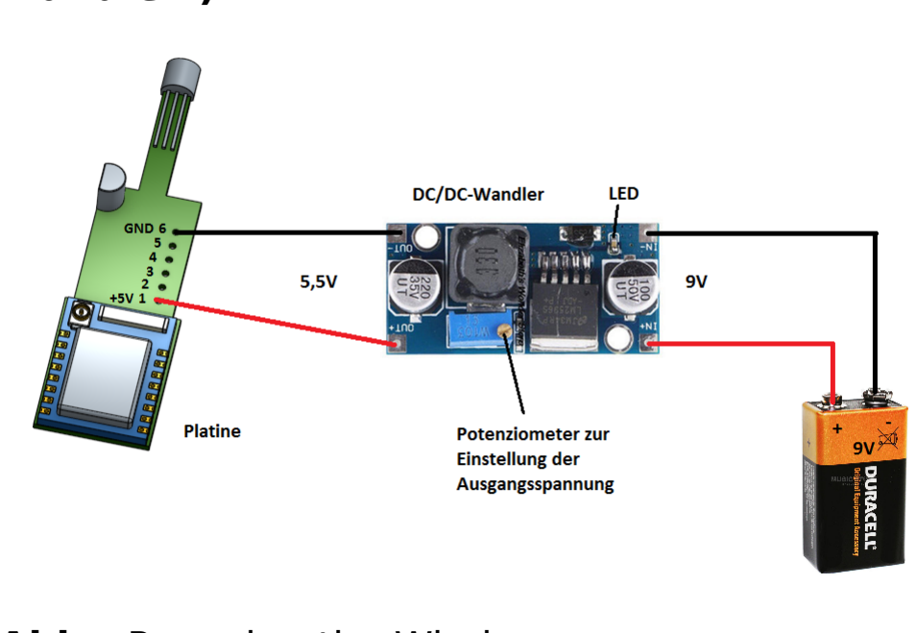
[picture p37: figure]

Abb.: Powering the Windsensor

The blue LED lights up on the sensor’s board. After a few seconds and successful login to the network the blue LED extinguishes. It is important that the sensor logs into the network, however without being asked to transmit data at port 6666. In such case (blue LED blinking) you need to disable any client program connection as e.g. OpenPlotter. This is the only functional constellation to access the update interface.

### 3. Download the firmware using your pc, laptop or mobile phone from

https://gitlab.com/norbertwalter67/Windsensor_WiFi_1000/blob/master/Arduino-Code/firmware_V1.01.wsb (https://gitlab.com/norbertwalter67/Windsensor_WiFi_1000/blob/master/Arduino-Code/firmware_V1.01.wsb)

### 4. Use your pc/mobile to login to the wireless network provided by the

windsensor:

SSID: NoWa
Password: 12345678

### 5. Point your browser to this address:

http://192.168.4.1/update

You will be presented a display to choose the new firmware. Select Firmware_V1.01.wsb as previously downloaded (see step 3) and press the update button. After successful data transmission a new, almost blank screen will display OK. If an error message is shown, you either chose a wrong file or the transmission failed for other reasons – retry the update if required.

### 6. Turn off the windsensor’s power, wait a few seconds and power it up

again.
This will start the windsensor running on the new firmware.

### 7. To validate the update and to modify the network parameters, point your

browser to this address:

http://192.168.4.1

The new firmware will display following screen – make sure it shows V1.0.1

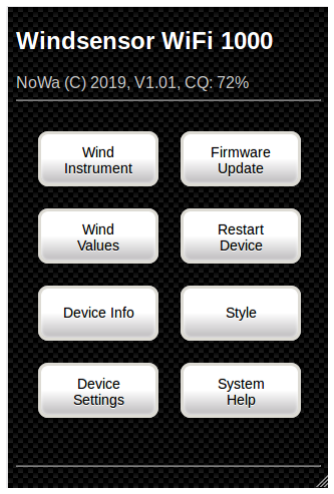
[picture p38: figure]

Menu item Device Info permits to view all current network parameters, whereas Device Settings allows to modify them at your will. After modification press Save to store any new values. The new settings will persist after restart as they are stored in the sensor’s permanent memory (EEPROM).

### 9. To activate the new network settings the Windsensor must be

restarted by interrupting power for a few seconds.

You may change all network parameters freely. Please note that SSID and password must not exceed 20 characters in length. Just alphabetic upper- and lowercase letters as well as numbers are allowed. Don’t use special characters. Minimum length is 8 characters for passwords and 1 character for SSID. A built-in validity check will output corresponding error messages.

External network parameters must be entered in any case, even if you prefer not to connect anywhere. Choose random values instead.

Make sure to write down your network settings and enter them correctly. Forgotten or mistyped parameters cannot be retrieved easily and the firmware will require manual flashing via serial interface.

Future updates may be performed online in the Update Firmware screen.

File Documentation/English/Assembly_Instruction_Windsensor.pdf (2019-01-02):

a

# Assembly Instructions

# Windsensor WiFi 1000

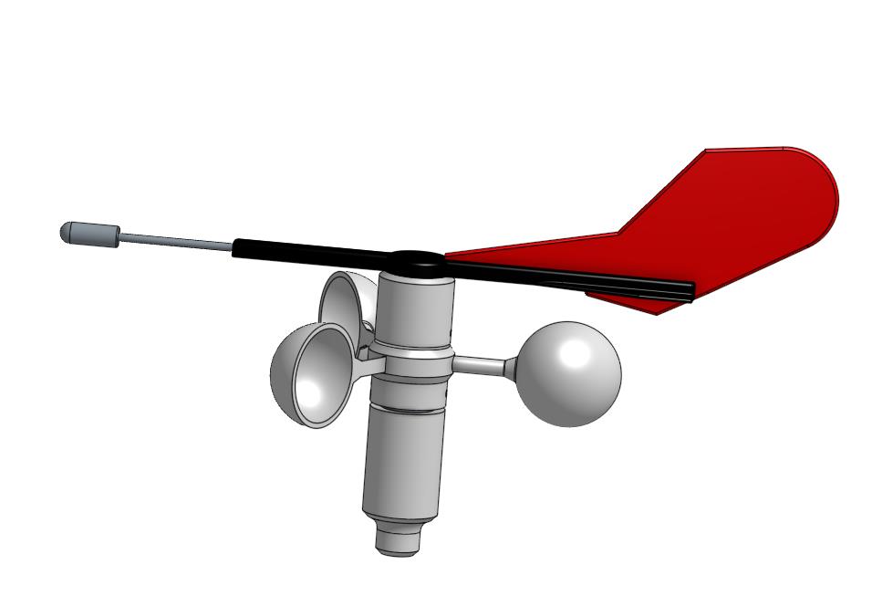
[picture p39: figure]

NoWa | Assembly Instructions – Windsensor WiFi 1000
2/22 | Vers.: 26.12.2018
Creator | Norbert Walter
| Wiesbadener Str. 1 40225 Düsseldorf Germany
| norbert-walter@web.de
© | The Assembly Instructions are subject to the Creative Common License.

Assembly Instructions – Windsensor WiFi 1000 | NoWa
Vers.: 24.12.2018 | 3/22

### Inhalt

## 1 Windsensor WiFi 1000

### 1.1 Preparation

The wind sensor WiFi 1000 consists of 45 individual parts which must be assembled. Before starting to assemble, all parts should be checked for completeness and the necessary tools and accessories should be available. It makes sense to use a suitable workplace where small individual parts such as grub screws cannot roll down. Alternatively, a white cotton cloth or a towel can be used. Small bowls for storing the respective parts are also very helpful.

Many parts are glued to the wind sensor. There are two reasons for this. One reason is that the 3D plastic parts cannot be printed in arbitrarily complex structures and can be dismantled into individual parts suitable for production and then subsequently assembled. On the other hand, to achieve a sufficient water tightness of the electronics. For this reason, all plastic parts are also painted, as the layered 3D printed parts made of PLA are not waterproof. After curing, the adhesive used should have a certain residual elasticity to compensate for the different coefficients of expansion of the materials used. In particular, the contact between metal and plastic are critical, as heavy stress can occur between the components at high temperature differences. The recommended 2-component glue Weikon RK-1300 is particularly easy to process. The activator previously applied to the plastic parts can be used for several days. Curing only begins when the actual glue gets in contact with the activator. This allows the bonding to be well prepared and only in the last step the parts finally are bonded. Of course, any other elastic glue can also be used.

Basically, you should ensure that the individual parts function well before gluing. A later disassembly is usually not possible without damaging the parts.

When setting the correct switching threshold for the wind direction sensor, a little more effort is necessary to find the correct setting point. The firmware can be used for this purpose. In difficult cases, it is helpful if one or two digital voltmeters are available to check the switching status of the Hall sensors during operation. Alternatively, test leads can be soldered to the circuit board, which greatly simplify handling. To support testing the open and non-installed electronics with parts of the mechanics, a mechanical substructure is required which holds the wind sensor securely in a vertical position during operation. A third hand or screw clamp can be very helpful. To simulate wind, a hairdryer set to cold can be used.

The white plastic parts are very sensitive to dirt. Especially glue residues should be removed immediately. Always work with clean hands. Not hardened Weikon glue residues can easily be removed with alcohol.

The time required for the pure assembly of the wind sensor is approximately 4 to 6 hours working time, depending on the respective abilities. The curing time of the glue of 24 hours is not included.

### 1.2 Check Completeness of Parts

First all parts should be checked for completeness. You can tick off the respective items in the parts list.

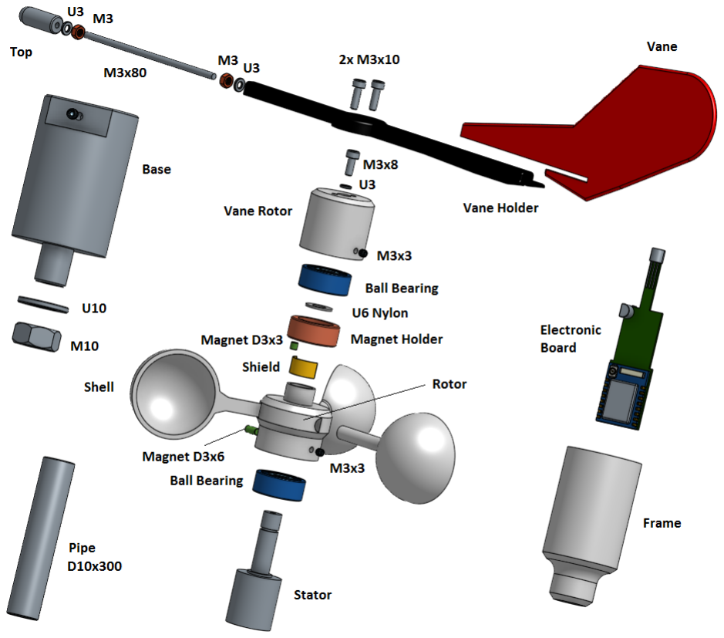
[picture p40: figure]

### 1.3 Checking the Accuracy of fit of the Parts

The next step is to check whether all parts can be joined as desired according to the design drawing. The threads in the plastic parts are already pre-cut. Especially the connections stator frame and frame tube should be able to be pushed together tightly to the intended end and have little play. If they are too tight, the plastic parts can be processed with a scalpel with a round blade or sandpaper. Basically, you should only rework the plastic parts, because they can be processed with less effort.

### 1.4 Cleaning the Ball Bearings for smooth running

As ball bearings, encapsulated industrial bearings of quality class ABEC7 are used. They are very accurate and have little clearance. A lower grade should not be used, nor should higher grades. Although they have a lower clearance, they are more difficult to move. ABEC7 is a good compromise between smooth running and low clearance. As standard, the ball bearings are lubricated with heavy rolling grease. Smooth running is only possible after cleaning. For this purpose, the ball bearings are submerged in cleaning alcohol and moved until the rolling grease has dissolved. The ball bearings should not lie overnight in cleaning alcohol, as additives in cleaning alcohol stimulate rusting of the stainless-steel parts. After the ball bearings have been freed from rolling grease and methylated spirits, they should be dried with kitchen paper. The final smooth running is not achieved until later in operation, when the rotor has rotated over a longer period. The ball bearings are well prepared if they run smoothly all around and do not rub against other ball bearing parts at any point. Some ball bearings are offered on the Internet that do not meet the specification. The ball bearing seal has a small air gap to the inner rotor and must not rub against the inner rotor. Otherwise the ball bearing is unusable and does not comply with the ABEC7 standard. Alternatively, open ball bearings can also be used.

### 1.5 Preparing the Wind Vane for Painting

For painting the vane is pushed into the groove on the vane holder and the vane holder is attached to the vane rotor with 2 M3x10 socket cap (Allen) screws. The vane rotor with wind vane is then fixed on a rod.

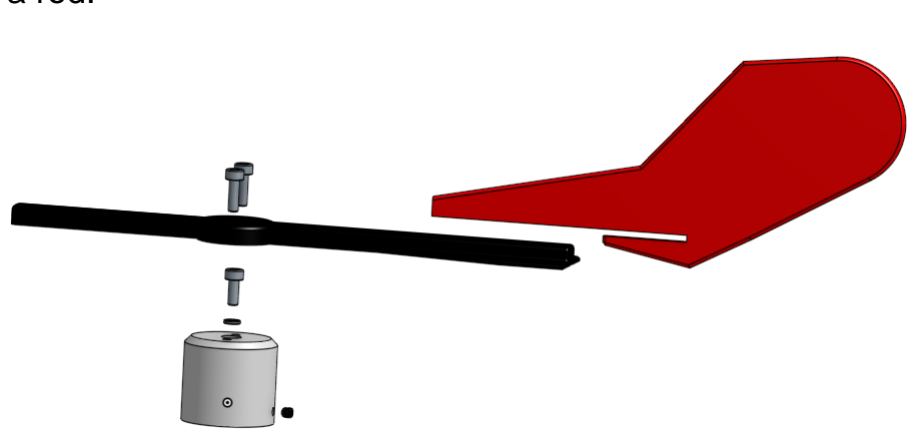
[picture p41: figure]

Fig.: Wind vane

### 1.6 Preparing the Shell Wheel for Painting

To paint the shell wheel, the shell bar ends are pushed into the rotor until they align with the inside. Alternatively, you can insert the ball bearing and then push the rod ends into the mounting holes until they touch the ball bearing. The rod ends do not have to be glued in yet. This can be done later. Then the shell wheel is fixed on a wooden rod for painting.

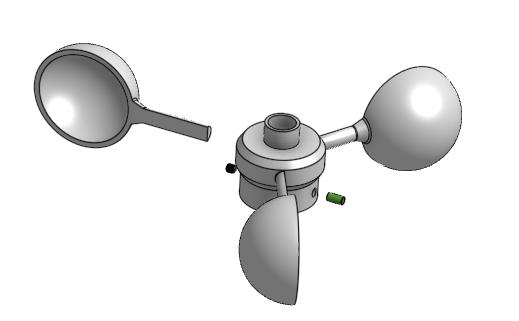
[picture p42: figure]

Fig.: Shell wheel

### 1.7 Preparing the Frame for Painting

The frame is fixed to a wooden rod from the large opening.

Fig.: Frame | Fig.: Prepared frame for painting

### 1.8 Painting

PLA is a plastic which cannot be painted directly due to its surface properties. A special pre-treatment of the substrate is required. However, there are special paints which can be applied directly to PLA without priming or pre-treatment. The recommended transparent paint "Aerosol Art" from Dupli-Color (matt or glossy) is a polymer paint with acetone and n-butyl acetate in a 400ml spray can. It can be applied directly to PLA in several coats without drying time.

Painting can be done in two ways. Either by painting with a brush or with a spray can. In principle, 3 layers of paint should be applied. Apply a correspondingly thinner layer to the fits. The layer structure should be thin and have no running drops. Running drops should be removed when damp.

If possible, spray painting should take place outdoors, as more paint is sprayed than is applied to the component. A cardboard should be placed in the background to take up excess paint. According to paint manufacturer recommendations, a minimum distance of 30cm should be observed when painting the component. Otherwise you apply too much varnish and running drops will appear. The parts are continuously turned or moved slowly during spraying so that all surfaces can be reached. Painting the inside of the bowl is a bit more difficult, because you can't see how much paint is applied. Here one should be more reserved, since one tends to apply too much. The correct layer thickness is reached when the wet paint starts to shine.

The varnish is hand dry after a short time and dry after 24 hours.

By using a filler before painting, the uneven surface of the 3D components can be significantly improved. The components will look much better. Before varnishing the actual parts, you should practice on test parts until the desired varnishing result is achieved.

### 1.9 Bending the Shield

The shield consists of a small piece of tin plate 20 x 7 mm to shield the magnetic field. The thickness of the tinplate is insignificant and can range between 0.15...0.3 mm. The bending of the tinplate is carried out around an M8 screw with a long smooth shaft and is rolled out on a wooden base. This ensures a good position and optimum alignment of the sheet. Then pull the metal sheet off the screw and repeat the same procedure with an M10 screw. Then the shield is perfectly bent. It is still a bit too small. At the plastic part, you may slightly bend up the panel. So, the screen fits absolutely perfect without gap to the plastic part. Fix the screen with a piece of transparent adhesive tape so that the function test can be carried out. The aperture should be glued just after sucessfully passing the function test

Fig.: Shield

### 1.10 Assembling the Wind Vane

First the bottom side of the vane holder is covered with the reflective foil. Cut the width and length of the foil so it corresponds to the maximum dimensions of the vane arm. The protective film must be removed from the reflective film cut in this way. It is helpful to hold the end of the foil with tweezers or a cutter knife. The film must now be aligned so that the complete bottom of the vane arm is covered. Starting from the end, the foil is applied step by step by pressing lightly with the finger to the tip of the vane arm. Enclosed air bubbles can be pushed out sideways. It is not possible to remove the film later, as the film will be destroyed. The film must therefore be applied cleanly in the first attempt.

In the second step, the remaining film is removed with a sharp cutter knife. For this purpose, the vane holder with the foil side is placed on a firm base and the protruding foil is cut along the edge with the cutter knife. A thicker cardboard or a wooden board can be used as an ideal base.

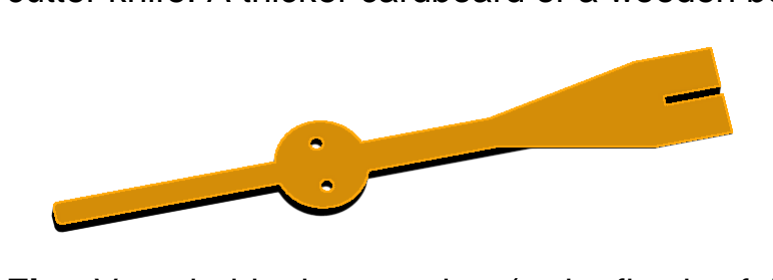
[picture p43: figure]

Fig.: Vane holder bottom view (red reflective foil)

Then vane and the vane arm are glued together. For this purpose, the small groove and the lower part of the vane are coated with activator. A thin glue seam can then be placed in the groove and the vane pushed into the vane arm. Remove excess glue with a cloth moistened with cleaning alcohol.

The ball bearing is glued into the rotor in the same way. Make sure that only the edge of the ball bearing and the inner part of the rotor are coated with activator and glue. Under no circumstances should glue get into the inside of the ball bearing.

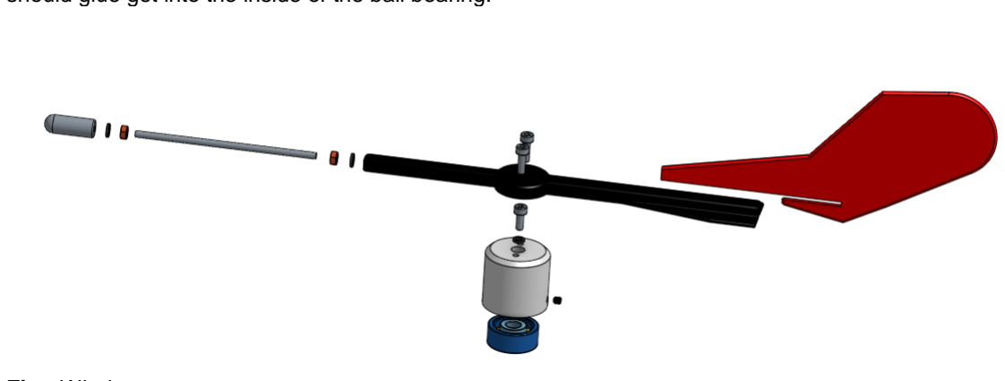
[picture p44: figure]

Fig.: Wind vane parts

After the glue has hardened, the wind vane can be screwed onto the vane rotor using the two M3x10 socket cap (Allen) screws.

The next step is to glue the silver reflective foil onto the tip. The foil is cut to size XX x XX mm and attached to the tip. The tip is then mounted on to the threaded rod and secured with a snap ring and a nut. At the opposite end, first a nut and then a locking washer are fitted and then the threaded rod is screwed into the vane holder as far as it will go.

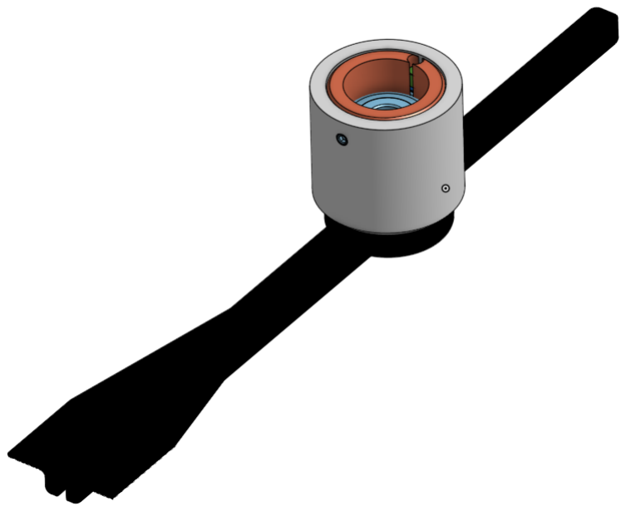
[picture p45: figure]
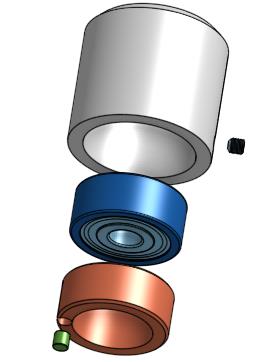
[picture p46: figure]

Fig.: Wind vane magnet | Fig.: Inserted magnetic holder with magnet

At the end the magnet is pushed into the magnet holder and the magnet holder is then inserted into the vane rotor. The magnet holder then rests on the edge of the ball bearing and aligns to with the bottom side of the vane holder. The magnet must be aligned on the opposite side of the grub screw so that it lies on the center line of the wind vane holder. The grub screw can be used to apply tension to the magnet holder so that the magnet is clamped in the slot.

### 1.11 Balancing the Wind Vane

Balancing is extremely important to get a smooth-running wind vane that aligns well in the wind. If the vane is not well balanced, bearing friction and premature wear will occur.

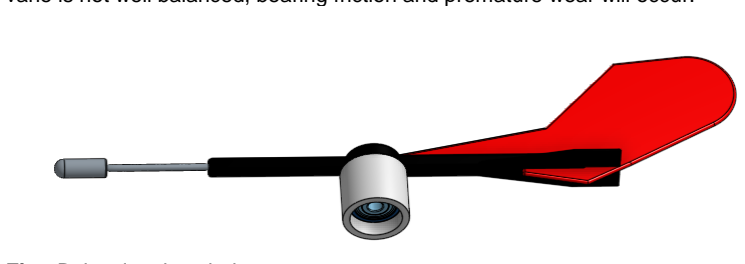
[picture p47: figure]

Fig.: Balancing the wind vane

To balance the vane, the vane rotor is pushed onto the stator and brought into a horizontal position. The result is a rocker which must be balanced with the help of the tip. If the tip lowers, the tip must be brought closer to the pivot point. If the tip rises, proceed in the opposite direction. The arm should be balanced as precisely as possible. Once you have found this position, tighten the lock nuts and check the balance again.

### 1.12 Assembling the Cup Anemometer

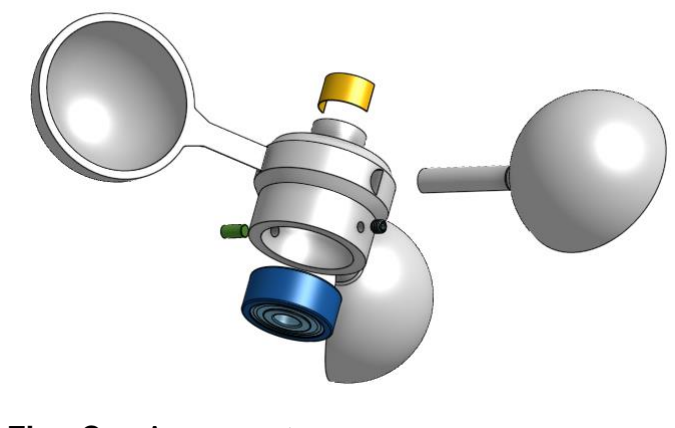
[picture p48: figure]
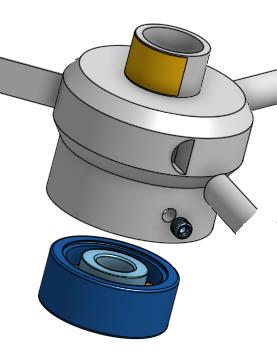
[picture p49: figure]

Fig.: Cup Anemometer | Fig.: Correct position of shield

To assemble the cup wheel, the ball bearing is glued in first, thereafter the cup rods. The activator is first applied to the outer ring of the ball bearing and the corresponding counter surface in the rotor. The glue is then applied to the rotor and evenly distributed with a Q-tip. Then both parts are joined together and excess glue is removed with a Q-tip. The ends of the cup rods can then be glued in the same way. Insert the ends of the rods as far as they will go so that they touch the ball bearing. The whole unit then requires 24 hours to cure the glue. The cover is still just fixed with adhesive tape and will be glued after the final test.

### 1.13 Wiring the Electronics

For wiring the electronics, the two cable ends of the CAT5e cable are stripped 50 mm and the individual wires are tinned to approx. 5 mm at the end. The 6 cable ends are then soldered from the underside of the circuit board according to the wiring diagram. Make sure not to introduce short circuits to the board connectors. If necessary, remove excess solder with the desoldering wire. Finally, remove the welding flux from the solder joints using a Q-tip soaked in alcohol. If the programming cables (cables 2, 3, 4, 5) are not required on the opposite connection side of the cable, they can be cut off with an electronic side cutter. Make sure that there are no short circuits between the cut cable ends. The cables can be cut off slightly offset. The red and black cables (cables 1 and 6) are the power supply connections for the wind sensor.

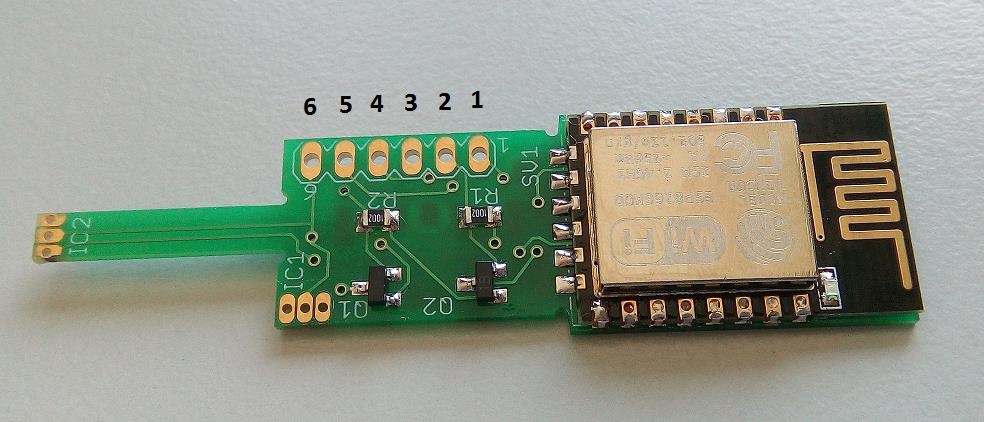
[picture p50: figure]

Fig.: Circuit board with solder connections

Pad | Wire Color

Short
Name

Meaning

1 | red | +5V | Power supply 5V
2 | blue | DTR | Programming
3 | yellow | RTS | Programming
4 | withe | RXD | Receive data
5 | broun | TXD | Send data
6 | black | GND | Ground

Tab.: Terminal assignment of the cables

### 1.14 Setting the Output Voltage of the DC/DC Converters

To adjust the two DC/DC converters, a voltage of ~12V is applied on the input side (In-, In+). The required output voltage is then set with a small screwdriver at the adjusting screw of the blue adjusting potentiometer according to the following table values. The output voltage is measured with a digital voltmeter at Out+ and Out-. Make sure that the input voltage is not connected with the wrong polarity. In+ means 12V and In- is GND. Otherwise the DC/DC converter can be destroyed. If the polarity is correct, the small SMD LED on the board lights up.

Abb.: DC/DC Converter

A test circuit with a 9V block battery to set the output voltage is shown below.

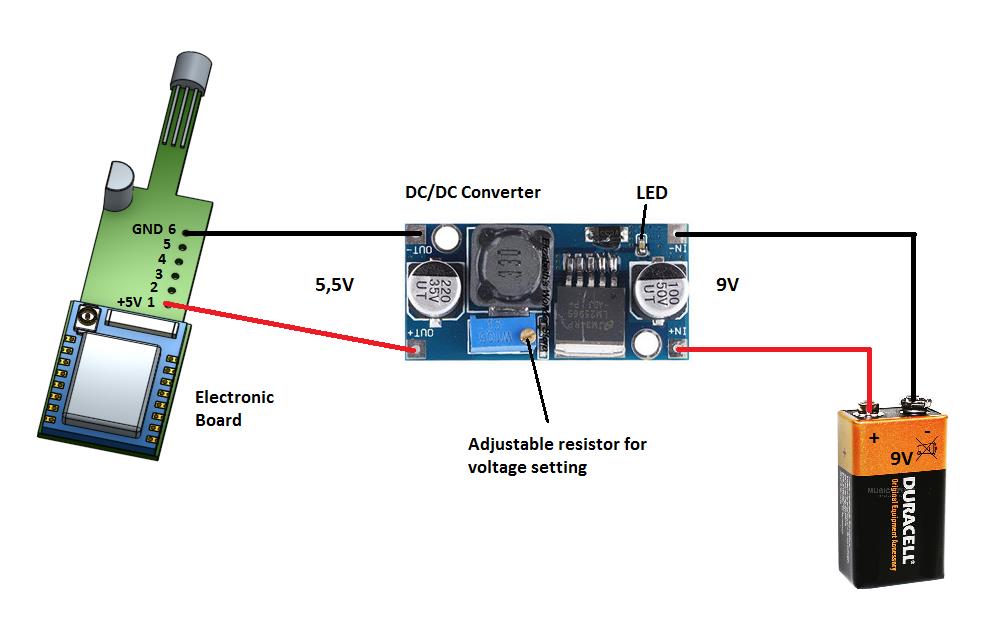
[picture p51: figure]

Fig.: Test circuit

Using | Input voltage [V]

Output voltage
[V]
Power supply of wind sensor | 12 | 5,5 +/-0,1
Feeding into the top light line | 12 | 7 +/-0,1

Tab.: DC/DC Converter output voltages

### 1.15 Testing the Electronics and Connecting to Application Software

To test the function of the electronics, connect the red (+5V) and black (GND) cables to the output of the 5.5V DC/DC converter (Out+, Out-). The input of the DC/DC converter (In+, In-) is connected to the 12V source. A DC plug-in power supply for 12V, a car battery or an adjustable laboratory power supply can be used as source. After the voltage has been switched on, the LED of the DC/DC converter lights up. At the same time the blue LED of the wind sensor board lights up. It remains lit until the wind sensor has successfully logged into a WLAN network. By default, fixed values for the WLAN parameters are specified on delivery.

Designation | Default values on delivery
Connection type | Client
WLAN | 11 bgn
SSID | MyBoat
Password | S6587rr94P
Port | 6666 TCP

Tab.: Default values on delivery

For testing purposes, an Internet router or mobile phone with hotspot function can be set to the WLAN parameters. If the parameters have been set correctly, the wind sensor should log into the WLAN and the blue LED on the wind sensor circuit board turns off. In the connection status overview of the router or mobile phone, the wind sensor should now be visible as a registered device.

OpenPlotter V0.8.0 can be set to the WLAN connection parameters in preparation for the final check under Chapter 1.21. In the configuration program OpenPlotter the settings can be made. To activate the WiFi access point, the checkbox [Enable access point] must be checked.

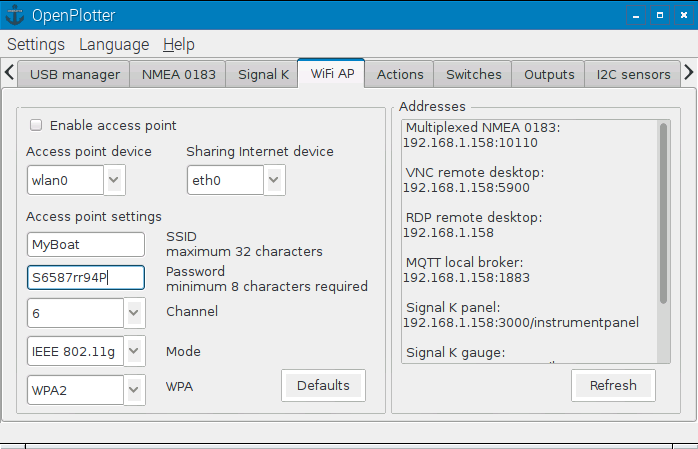
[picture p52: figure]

Fig.: OpenPlotter WiFi Network configuration

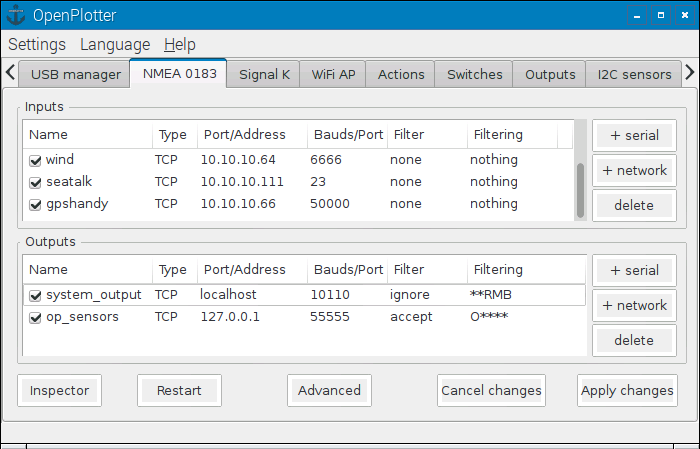
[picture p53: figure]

Fig.: Sensor configuration on OpenPlotter

The tab [NMEA0183] can be used to add new sensors in the Inputs area, so-called Devices, by selecting [+network]. The IP address of the wind sensor must be determined first. As a precondition, the wind sensor must already be registered within WLAN MyBoat of OpenPlotter and the blue LED of the board must be off. A Linux terminal window can be opened under [Menu] -> [Accessories] -> [Terminal]. The command arp -a is entered in the command line. The line containing ESP_XXXXXX displays the corresponding IP address. In our case this is IP 10.10.10.143.

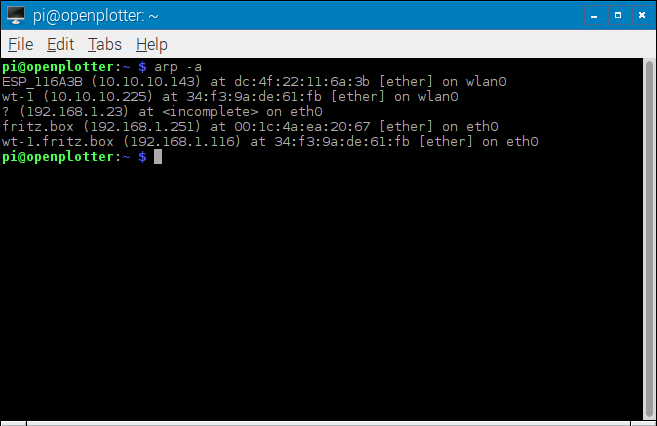
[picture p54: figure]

Fig.: Terminal window with IP address output

The wind sensor can now be added via [+network]. Confirm input with [OK].

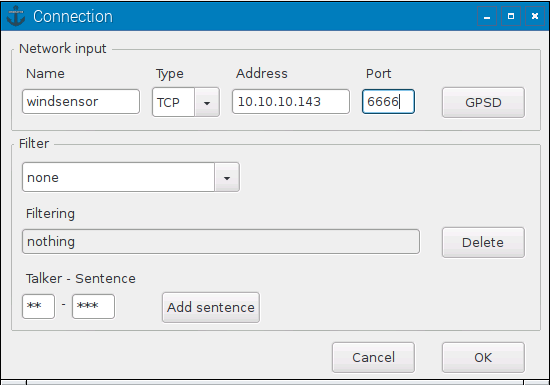
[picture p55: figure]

Abb.: Configuration page to set wind sensor IP adress

To accept the settings, press the [Apply Changes] button at the end of the entries in the [NMEA0183] window. Otherwise the settings will not be accepted and will be lost.

To be able to publish the wind sensor data via OpenPlotter, the NMEA0183 server must be restarted via the [Restart] button. A successful connection is visible in the Diagnostic Monitor Inspector. Data packets from the wind sensor should then arrive every 2 seconds and be displayed as values for wind speed and wind direction.

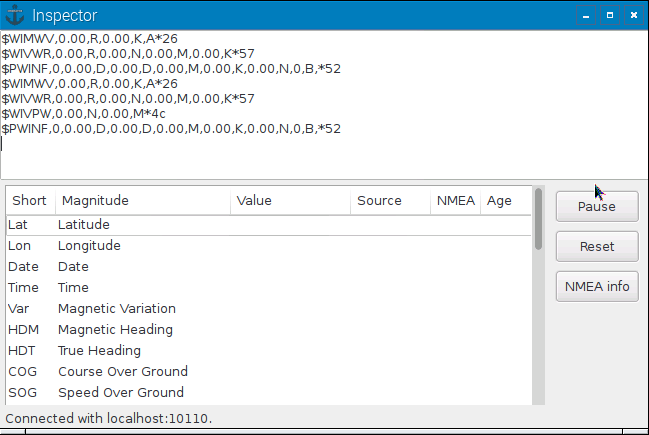
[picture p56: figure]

Fig.: NMEA inspector

Under certain circumstances, other telegrams may also arrive which are transmitted by other sensors. Each time a telegram is sent from the wind sensor, the blue LED of the electronic board lights up briefly as confirmation. Now, however, the values are still zero, as the hall sensors do not yet receive any signals from the magnets. If the LED is permanently lit, the wind sensor could not log into the WLAN network. If the LED is permanently off, a connection to the WLAN network has been established. However, OpenPlotter does not request any data from the wind sensor.

To display the NMEA data from the wind sensor, the OpenPlotter instrument panel can be accessed using an Internet browser. The following address must be called up for this purpose:

http://10.10.10.1:3000

Then the instrument panel can be started and the display elements can be arranged freely.

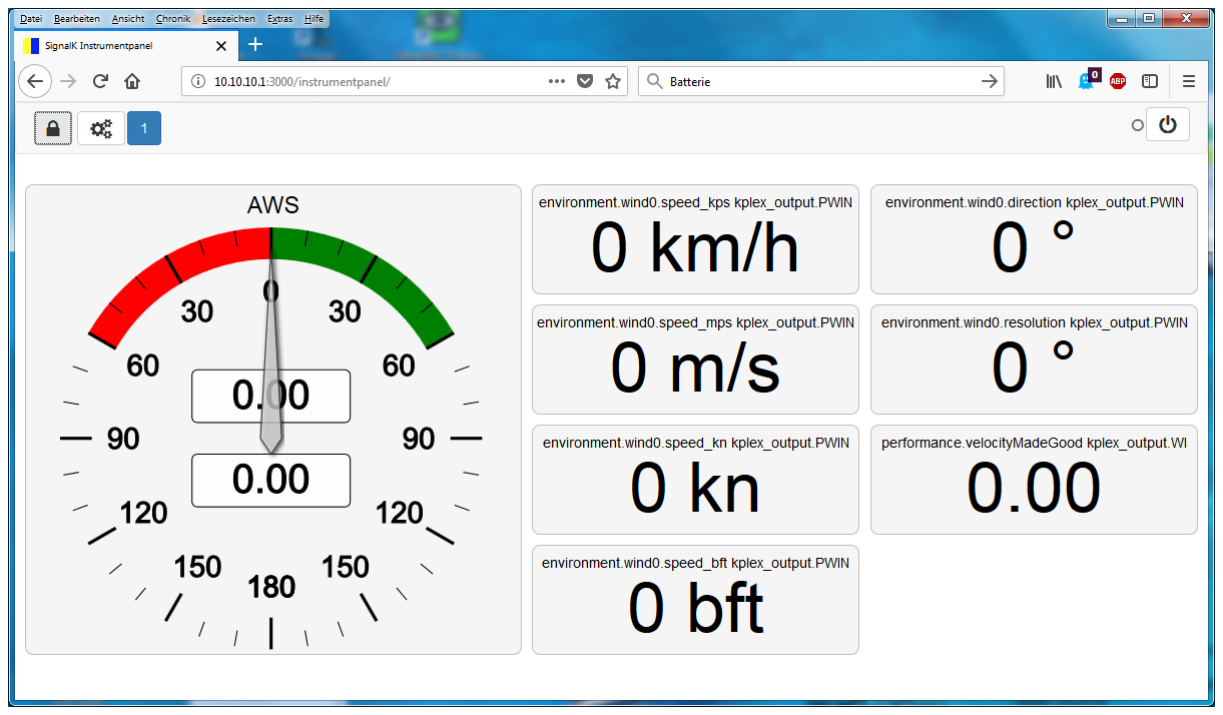
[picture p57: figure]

Fig.: Instrument Panel in OpenPlotter

Please note that only one data connection can be established at a time between a given application software and the wind sensor. If the sensor is already connected (this does not mean the WLAN), no data request can be made by another application software.

Similarily, a connection can also be established with other application software. Depending on the functionality of the software, the diagnostic options are partly restricted or not available at all. OpenCPN is also very well suited as test software since a diagnostic monitor is also available for the NMEA data packets.

### 1.16 Assembling the Frame with Base

When assembling the frame, the first step is to glue the tube to the frame. Brush both the tube and the frame with activator. After the drying time of the activator, the glue is evenly distributed with a Q-tip in the tube holder of the frame. The tube is then pushed into the frame as far as it will go. After the glue has cured, the base can be attached to the tube.

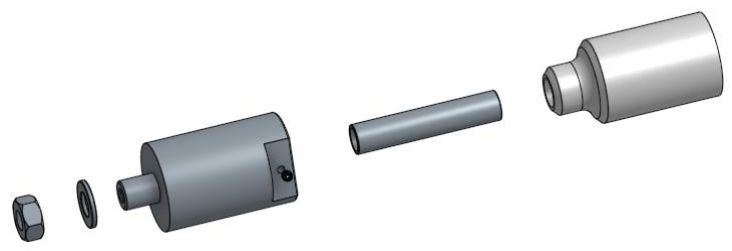
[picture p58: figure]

Fig.: Frame with standpipe and base

### 1.17 Adjusting the Wind Speed Magnet

The adjustment of the wind speed magnet is quite simple. The magnet D3x6 must be inserted into the 3mm hole of the cup rotor. The magnet is inserted so deeply that it does not touch the stator in any operating position when the shell wheel is mounted. There should be a gap of 0.3...0.5 mm. The function can be checked with a digital voltmeter or in OpenPlotter. If no measured value is visible with a rotating shell wheel, the polarity of the magnet is wrong and the magnet must be installed the other way around. If the correct function is given, the magnet can be fixed with a drop of superglue.

### 1.18 Adjusting the Wind Direction Magnet

The adjustment of the wind direction magnet is somewhat more complex, since a safe switching threshold must be found for all wind directions while the shell wheel rotates.

In the first step, the vane and the shell wheel are placed on the stator. The magnet D3x3 must first be inserted into the small slot of the vane rotor up to the middle. Then, with the wind vane fixed, the shell wheel is turned through 360° and the switching status of the Hall sensor is checked with a digital voltmeter. The signal must be on for about half a turn and off for the rest of the turn. For each revolution, the Hall sensor may be 1x on and 1x off. The following figure shows the correct switching behavior of the two Hall sensors in the oscilloscope.

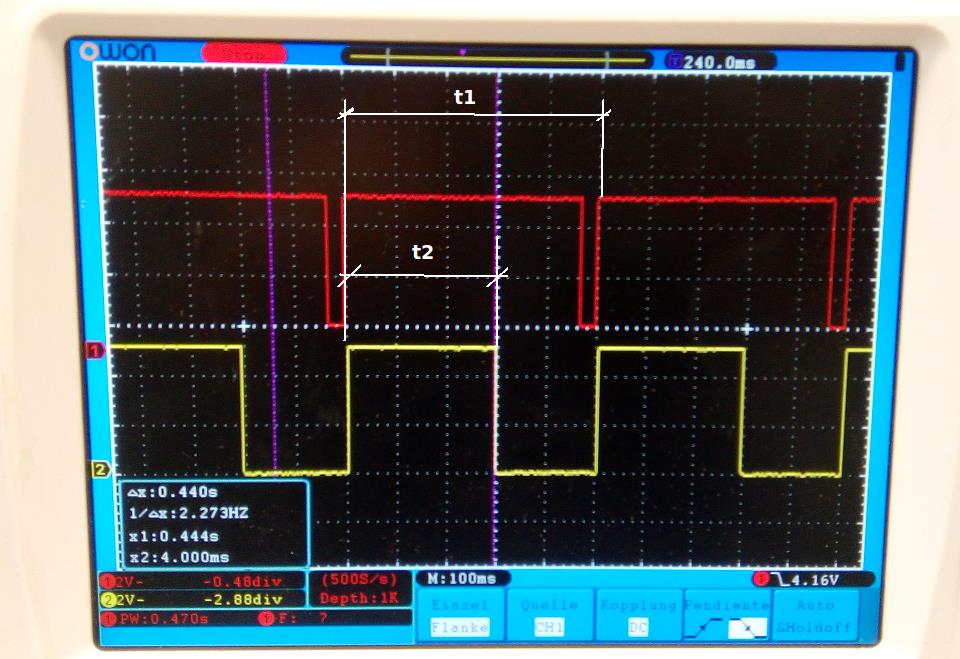
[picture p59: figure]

Fig.: Time signal characteristics of the Hall sensors (red wind speed, yellow wind direction)

If the Hall sensor does not switch at all, continuously or several times, the position of the magnet must be varied and the result checked. Once a correct position has been found, the angle of the wind vane must now be changed for all further wind directions and the correct switching behavior must also be checked. The problem is that the Hall sensor’s sensitivity varies at different angle directions, so the switching threshold changes depending on the direction of the magnetic field. The reduction of the magnetic field by the shield must be sufficiently large to produce correct switching behavior. The following diagram visualises the behavior of the Hall sensor.

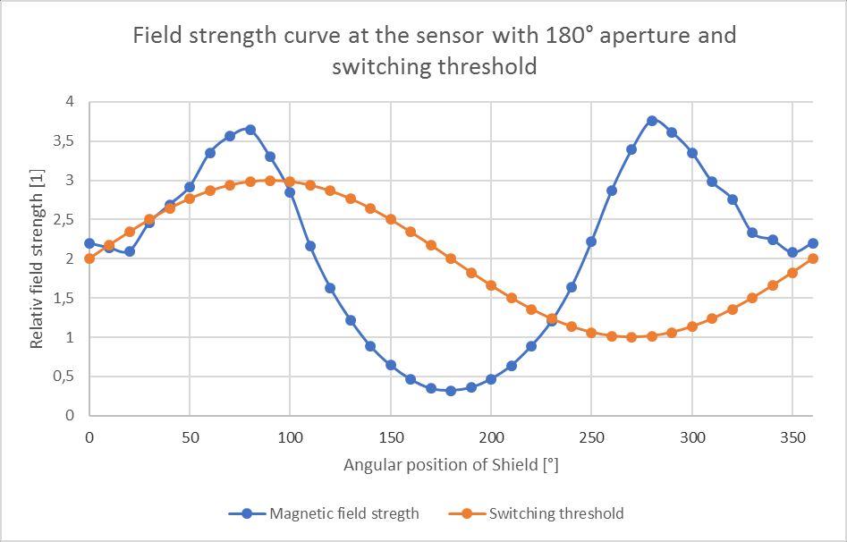
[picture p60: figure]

Fig.: Switching behavior of the Hall sensor for the wind direction

The Hall sensor always switches when the blue curve (magnetic field strength) is above the orange curve (switching threshold). The diagram shows 2 switched on and 2 switched off states. The magnetic field at the sensor must be raised to achieve exactly one switched-on and one switched-off state. The magnetic field strength can be changed by changing the magnet position along the groove. The blue line in the diagram then moves up or down. If the wind vane is twisted, the blue line shifts sideways depending on the direction of rotation. As can be seen in the diagram, the aperture does not generate a clean rectangularly reduced magnetic field during the passage through the shield. This is mainly because the half-open shield draws the magnetic field into the semicircle. The magnetic field inside the shield tends to run along the least magnetic resistance.

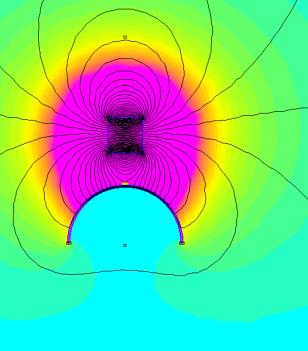
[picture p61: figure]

Fig.: Magnetic field characteristics at different shield positions

### 1.19 Function Test

In the functional test, all parts are assembled as they should be in their final state, with the exception that the parts are not yet glued together. The connecting cable is pulled through the frame, the standpipe and the mounting foot. Before the circuit board is inserted into the stator, the Hall sensor at the tip of the narrow bar must be protected against short circuits. A piece of transparent tape is wrapped around the outside of the Hall sensor and the circuit board so that the connection pins and the connection legs of the Hall sensor are protected. The board can then be pushed into the stator as far as it will go. Next, the stator is connected to the frame and then the shell wheel and the vane are mounted.

The function test is now carried out as described under 1.15. The correct function can then be checked in the application software. It is helpful if a pointer instrument is used for this purpose. This makes it easier to visually compare the angular positions with the position of the wind vane. If the wind vane is turned slowly by 360°, no jumps may occur in the angle display. If jumps are present, this indicates a faulty switching behavior and the magnet of the wind direction sensor must be readjusted. Then you should test the complementary wind directions 0°-180° and 90° -270° and check whether the display values of the angles are correct.

Finally, lightly oil the ball bearings of the vane and the shell wheel. Any excess oil must be removed. It should be oiled very sparingly so that the oil cannot leak out afterwards.

### 1.20 Glueing the Stator

After all preliminary work and tests have been successfully completed, the stator can be glued into the frame. However, you should be sure that the wind sensor works properly, as it is not possible to open it later without destroying the frame. Before you glue the parts together, you should check whether the board is stuck in the assembled state of stator and frame and has no clearance along the main axis.

This can be checked by gently pulling and pushing the connection cable. Otherwise the Hall sensor of the wind direction measurement could slip during operation and change the switching thresholds of the sensor. If there is a small clearance, a small piece of foam rubber can be inserted into the recess of the frame, which pushes the circuit board towards the stator.

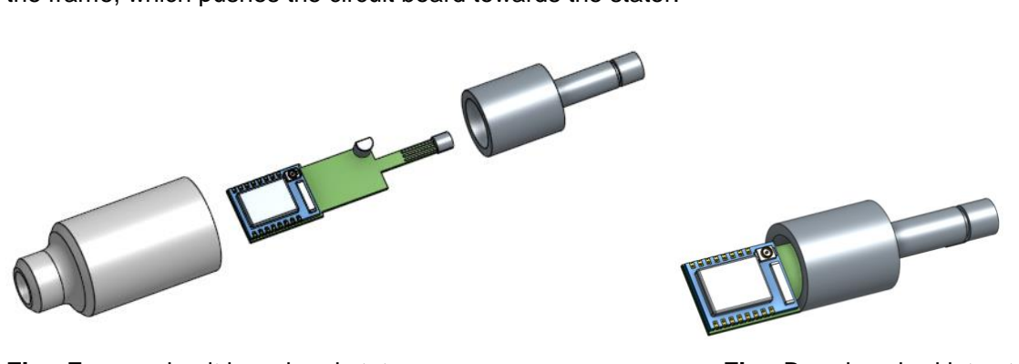
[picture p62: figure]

Fig.: Frame, circuit board and stator | Fig.: Board pushed into stator

Alternatively, the inserted circuit board in the stator can be filled with silicone up to the edge of the stator.

The bonding takes place as usual on the contact surface between stator and frame. Any excess glue should be removed with a cloth so that a clean joint is formed at the transition between the stator and frame. The joint must be completely filled with glue in order to achieve a sufficient tightness against humidity.

### 1.21 Final Inspection

In the final test, the same tests as in the functional test under 1.19 are performed. Possible switching or angular errors can now be corrected if the position of the board has changed again after the stator and frame have been glued together.

Finally, you should make a mark on the frame to mark the midship position (0° position). This way the wind sensor can easily be aligned to the correct position on the mast and the values are displayed correctly in the application software.

### 1.22 Glue the Shield and Magnet

Finally, the shield is glued in place and the magnet of the vane rotor is secured.

If possible, the shield should be glued aligned to the outer edge of the rotor without canting and without air gap. A suitable cable tie can be used to temporarily fix the cover.

The magnet of the vane rotor is secured by carefully tightening the opposite grub screw and securing the magnet with a drop of superglue. The grub screw should not be tightened too much, as the vane rotor could tear due to the high forces. Even small forces are sufficient to clamp the magnet securely in the gap.

### 1.23 Further Information

1) OpenPlotter: http://www.sailoog.com/openplotter
2) OpenPlotter Video: https://www.youtube.com/watch?v=LJyOYgIw6L4
3) OpenCPN: https://opencpn.org/
4) Weikon RK-1300:https://www.weicon.de/anwendungsbereiche/kleben-und-abdichten/grosse-teile-verbinden/schnellhaertend-schlagzaeh/243/rk-1300-acrylat-strukturklebstoff (https://www.weicon.de/anwendungsbereiche/kleben-und-abdichten/grosse-teile-verbinden/schnellhaertend-schlagzaeh/243/rk-1300-acrylat-strukturklebstoff)
5) Weikon video: https://www.youtube.com/watch?v=JJsYCqT3pSQ
6) Tips for soldering: https://www.sciencebuddies.org/science-fair-projects/references/how-to-solder#overview (https://www.sciencebuddies.org/science-fair-projects/references/how-to-solder%23overview)
7) Soldering video: https://www.youtube.com/watch?v=Qps9woUGkvI
8) Digital voltmeter video: https://www.youtube.com/watch?v=rUkvHeXsPWs

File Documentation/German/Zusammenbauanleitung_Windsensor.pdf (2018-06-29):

# Zusammenbau-Anleitung

# Windsensor WiFi 1000


NoWa | Zusammenbau-Anleitung – Windsensor WiFi 1000
2/22 | Vers.: 28.06.2018
Ersteller | Norbert Walter
| Wiesbadener Str. 1 40225 Düsseldorf
| norbert-walter@web.de

© Die Technische Beschreibung unterliegt der Creative Common Lizenz

Zusammenbau-Anleitung – Windsensor WiFi 1000 | NoWa
Vers.: 28.06.2018 | 3/22

### Inhalt

4/22 | Vers.: 28.06.2018

## 1 Windsensor WiFi 1000

### 1.1 Vorbereitungen

Der Windsensor WiFi 1000 besteht aus 45 Einzelteilen die zusammengebaut werden müssen. Bevor der Zusammenbau beginnt, sollten alle Einzelteile auf Vollständigkeit geprüft werden und das nötige Werkzeug und die Hilfsmittel bereitstehen. Sinnvoll ist eine geeignete Arbeitsunterlage zu benutzen, auf der kleine Einzelteile wie z.B. Madenschrauben nicht herunterrollen können. Alternativ kann ein weißes Baumwolltuch oder ein Handtuch benutzt werden. Kleine Schälchen zur Aufbewahrung der jeweiligen Teile sind auch ganz hilfreich.

Am Windsensor werden viele Teile verklebt. Das hat zwei Gründe. Zum einen weil die 3D-Kunststoffteile nicht in beliebig komplexen Strukturen gedruckt werden können und in fertigungsgerechte Einzelteile zerlegt und dann nachträglich zusammengebaut werden. Zum anderen um eine ausreichende Wasserdichtheit der Elektronik zu erlangen. Aus diesem Grund werden auch alle Kunststoffteile lackiert, da die schichtweise hergestellten 3D-Druckteile aus PLA nicht wasserdicht sind. Der verwendete Kleber sollte nach dem aushärten eine gewisse Restelastizität besitzen, um die verschiedenen Ausdehnungskoeffizienten der verwendeten Materialien ausgleichen zu können. Besonders die Übergänge Metall zu Kunststoff sind kritisch, da dort bei hohen Temperaturdifferenzen starke Spannungen zwischen den Bauteilen auftreten können. Der empfohlene 2-Komponenten-Kleber Weikon RK-1300 lässt sich besonders gut verarbeiten. Der vorher auf die Kunststoffteile aufgetragene Aktivator ist über mehrere Tage lang benutzbar. Erst wenn der eigentliche Kleber mit dem Aktivator zusammen kommt beginnt die Aushärtung. So kann die Klebung gut vorbereitet werden und erst im letzten Schritt werden die Teile endgültig verklebt. Es kann natürlich auch jeder andere restelastische Kleber verwendet werden.

Grundsätzlich sollte man sich sicher sein, dass die Einzelteile funktionieren, bevor man sie zusammenklebt. Ein nachträgliches zerlegen ist ohne Beschädigung der Teile meistens nicht möglich.

Bei der Einstellung für die richtige Schaltschwelle des Windrichtungssensors ist etwas mehr Aufwand notwendig, um den richtigen Einstellpunkt zu finden. Die Firmware kann zu diesem Zweck benutzt werden. In schwierigen Fällen ist es hilfreich, wenn ein oder zwei Digitalvoltmeter vorhanden sind, um die Schaltzustände der Sensoren im Betrieb überprüfen zu können. Hilfsweise kann man Testleitungen an der Platine anlöten, die das Handling sehr vereinfachen. Um die offene und nicht eingebaute Elektronik mit Teilen der Mechanik testen zu können ist ein mechanischer Unterbau nötig, der den Windsensor im Betrieb sicher in senkrechter Lage hält. Eine dritte Hand oder Schraubzwinge können sich als sehr hilfreich erwiesen. Um den Wind zu simulieren, kann man ein auf kalt eingestellten Haartrockner benutzen.

Die weißen Kunststoffteile sind sehr empfindlich auf Verschmutzungen. Besonders Kleberreste sollten umgehend entfernt werden. Es sollte stets mit sauberen Händen gearbeitet werden. Nicht ausgehärtete Weikon Kleberreste könne einfach mit Alkohol entfernt werden.

Als Zeitbedarf für den reinen Zusammenbau des Windsensors wird abhängig vom den jeweiligen Fähigkeiten ungefähr 4G6 Stunden Arbeitszeit benötigt. Die Aushärtezeit des Klebers von 24 Stunden ist dabei nicht eingerechnet.

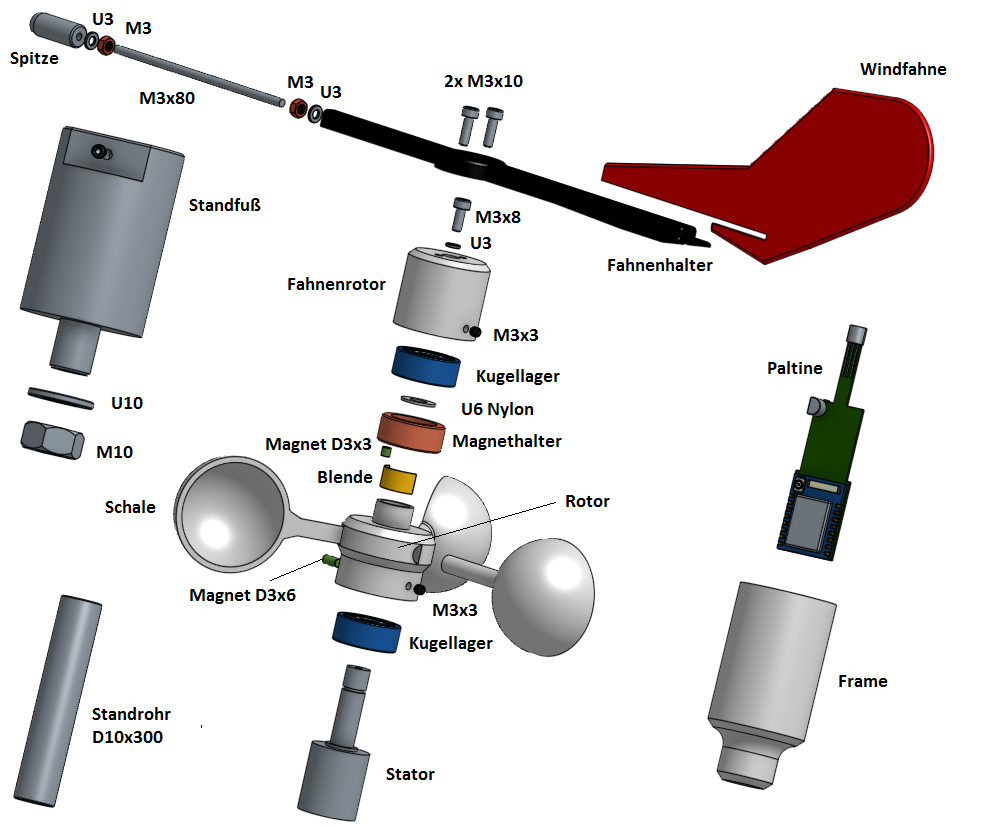
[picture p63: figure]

Vers.: 28.06.2018 | 5/22

### 1.2 Vollzähligkeit der Teile prüfen

Als erstes sollten alle Teile auf Vollständigkeit geprüft werden. Dazu kann man in der Stückliste die jeweiligen Teile abhaken.

### 1.3 Passgenauigkeit der Teile prüfen

Als nächstes prüft man, ob sich alle Teile wie gewünscht nach der Konstruktionszeichnung zusammenfügen lassen. Die Gewinde in den Kunststoffteilen sind bereits alle vorgeschnitten. Besonders die Verbindungen Stator-Frame und Frame-Rohr sollte stramm bis zum vorgesehenen Ende zusammengeschoben werden können und wenig Spiel aufweisen. Wenn sie zu fest sind, kann man mit einem Skalpell mit runder Klinge oder mit Sandpapier die Kunststoffteile bearbeiten. Grundsätzlich sollte man nur die Kunststoffteile nacharbeiten, da sie sich mit weniger Aufwand bearbeiten lassen.

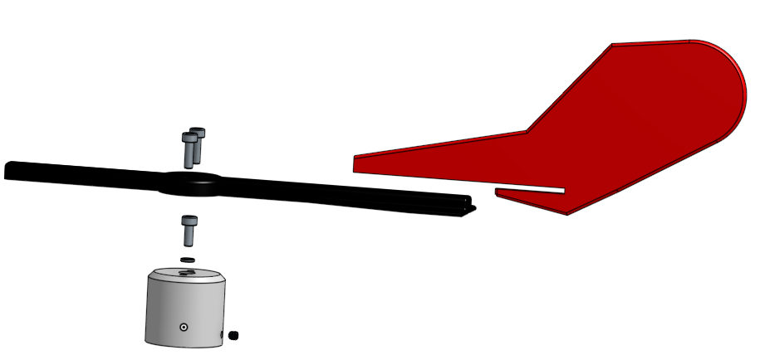
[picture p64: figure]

6/22 | Vers.: 28.06.2018

### 1.4 Kugellager für den Leichtlauf reinigen

Als Kugellager werden gekapselte industrielle Lager der Güteklasse ABEC7 verwendet. Sie sind sehr genau und weisen ein geringes Spiel auf. Eine niedrigere Güteklasse sollte nicht verwendet werden, höhere Güteklassen ebenso nicht. Sie haben zwar ein geringeres Spiel, sind dafür aber schwergängiger. ABEC7 ist ein guter Kompromiss zwischen Leichtlauf und geringem Spiel. Standardmäßig werden die Kugellager mit schwergängigem Wälzfett geschmiert. Ein Leichtlauf ist nur nach Säuberung möglich. Dazu werden die Kugellager in Brennspiritus gelegt und so lange bewegt, bis sich das Wälzfett aufgelöst hat. Die Kugellager sollten nicht über Nacht in Brennspiritus liegen, da Zusatzstoffe im Brennspiritus das Rosten der Edelstahlteile anregen. Nachdem die Kugellager vom Wälzfett und Brennspiritus befreit sind, sollte man sie mit Küchenpapier trocknen. Der endgültige Leichtlauf wird erst später im Betrieb erzielt, wenn sich der Rotor über einen längeren Zeitraum gedreht hat. Die Kugellager sind gut präpariert, wenn sie rundherum leichtgängig sind und an keiner Stelle mit anderen Kugellagerteilen scheuern. Teilweise werden im Internet Kugellager angeboten die nicht der Spezifikation entsprechen. Der Kugellagerabdichtung hat einen kleinen Luftspalt zum Innenläufer und darf nicht am Innenläufer scheuern. Anderenfalls ist das Kugellager unbrauchbar und entspricht nicht der ABEC7 Norm. Alternativ können auch offene Kugellager verwendet werden.

### 1.5 Windfahne zum Lackieren vorbereiten

Zum Lackieren wird die Fahne auf den Fahnenhalter in die Nut geschoben und der Fahnenhalter mit 2 M3x10 Inbus-Schrauben mit dem Fahnenrotor verbunden. Der Fahnenrotor mit Windfahne wird dann auf einem Stab fixiert.

Abb.: Windfahne

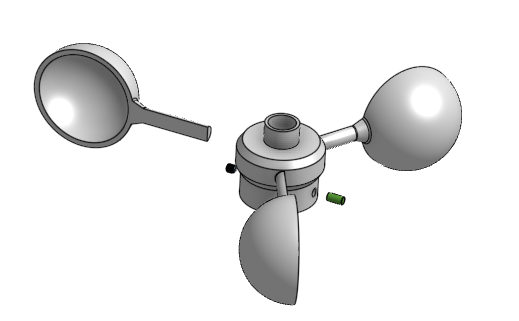
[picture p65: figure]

Vers.: 28.06.2018 | 7/22

### 1.6 Schalenrad zum Lackieren vorbereiten

Zum Lackieren des Schalenrades werden die Schalen-Stabenden in den Rotor geschoben, bis sie bündig mit der Innenseite abschließen. Alternativ kann man das Kugellager einlegen und dann die Stabenden in die Aufnahmelöcher einschieben bis sie am Kugellager anstoßen. Die Stabenden müssen noch nicht eingeklebt werden. Das kann zu einem späteren Zeitpunkt erfolgen. Danach wird das Löffelrad zum Lackieren auf einem Stab fixiert.

Abb.: Schalenrad

### 1.7 Frame zum Lackieren vorbereiten

Der Frame wird von der großen Öffnung her auf einem Stab fixiert.

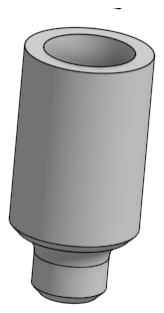
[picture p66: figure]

Abb.: Frame | Abb.: Vorbereitetes Teil zum Lackieren

### 1.8 Lackieren

PLA ist ein Kunststoff der sich aufgrund seiner Oberflächeneigenschaften nicht direkt lackieren läßt. Es muss eine spezielle Vorbehandlung des Untergrundes erfolgen. Es gibt aber Speziallacke die ohne Grundierung und Vorbehandlung direkt auf PLA aufgetragen werden können. Der empfohlene transparente Lack „Aerosol Art“ von Dupli-Color (matt oder glänzend) ist ein Polymerlack mit Aceton

8/22 | Vers.: 28.06.2018

und n-Butylacetat in einer 400ml Sprühdose. Er kann direkt auf PLA in mehreren Lagen ohne Abtrockenzeit aufgebracht werden.

Das Lackieren kann auf zweierlei Art vorgenommen werden. Entweder per Lackierung mit dem Pinsel oder per Sprühdose. Grundsätzlich sollten mit jedem Verfahren 3 Schichten aufgetragen werden. An den Passungen ist entsprechend dünner aufzutragen. Grundsätzlich sollte der Schichtaufbau dünn sein und keine Laufnasen aufweisen. Laufnasen sind im feuchten Zustand zu entfernen.

Das Sprühlackieren sollte möglichst im Freien erfolgen, da mehr Lack danebengesprüht wird als auf das Bauteil kommt. Im Hintergrund sollte eine Pappe aufgestellt werden die den überschüssigen Lack aufnimmt. Je nach Empfehlung des Lackherstellers sollte ein Mindestanstand von 30cm beim Lackieren zum Bauteil eingehalten werden. Anderenfalls trägt man sonst zu viel Lack auf und es kommt zu Läufern. Die Teile werden beim Sprühen fortlaufend langsam gedreht bzw. bewegt, so dass alle Flächen erreicht werden können. Das Lackieren der Schaleninnenseite ist etwas schwieriger, da man nicht richtig einsehen kann wie viel Lack aufgetragen ist. Hier sollte man zurückhaltender sein, da man eher neigt zu viel aufzutragen. Die richtige Schichtdicke ist erreicht, wenn der feuchte Lack anfängt zu glänzen.

Der Lack ist nach kurzer Zeit handtrocken und nach 24h endtrocken.

Durch Verwendung eines Füllers vor dem lackieren kann die Unebenheit der 3D-Bauteile wesentlich verbessert werden. Die Bauteile sehen dann optisch besser aus. Vor dem Lackieren der eigentlichen Teile sollte an Testteilen geübt werden, bis sich das gewünschte Lackierergebnis einstellt.

### 1.9 Blende biegen

Die Blende besteht aus einem kleinen Stück Weissblech 20 x 7 mm zur Abschirmung des Magnetfeldes. Die Dicke des Weissblechs ist unerheblich und kann im Berreich zwischen 0,15G0,3 mm liegen. Die Biegung des Weissblechs erfolgt um eine M8-Schraube mit langen glatten Schaft und wird auf einer Holzunterlage ausgewalzt. So hat man einen guten Anschlag und kann das Blech optimal ausrichten. Danach wird das Blech von der Schraube abgezogen und das Gleiche noch einmal mit einer M10- Schraube wiederholt. Danach ist die Blende perfekt gebogen. Sie ist zwar noch etwas zu klein. Am Kunststoffteil kann man die Blende noch etwas aufbiegen. So sitzt die Blende absolut perfekt ohne Luft zum Kunststoffteil. Testweise wird die Blende mit einem Stück Tesafilm fixiert, damit der Funktionstest durchgeführt werden kann. Erst nach erfolgreichen Funktionstest sollte die Blende angeklebt werden.

Abb.: Blende

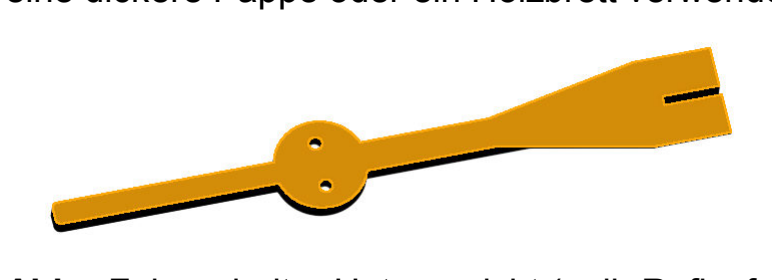
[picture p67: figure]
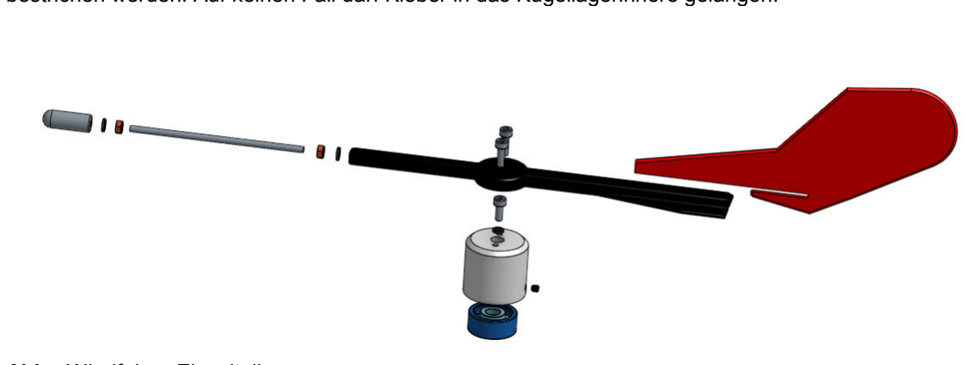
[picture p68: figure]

Vers.: 28.06.2018 | 9/22

### 1.10 Windfahne zusammenbauen

Als erstes wird die Unterseite des Fahnenhalters mit der Reflexfolie beklebt. Dazu ist die Folie in der Breite und Länge so zuzuschneiden, dass sie den maximalen Abmaßen des Fahnenhalters entspricht. An der so zugeschnittenen Reflexfolie ist die Schutzfolie abzuziehen. Es ist hilfreich ein Folienende mit einer Pinzellte oder Cuttermesser festzuhalten. Die Folie muss jetzt so ausgerichtet werden, dass die komplette Unterseite des Fahnenhalters abgedeckt wird. Beginnend vom Ende des Fahnenhalters wird die Folie Stück für Stück durch leichtes Andrücken mit dem Finger bis zum Anfang des Fahnenhalters aufgezogen. Vorhandenen Blasen können seitwärts herausgedrückt werden. Ein nachträgliches Abziehen der Folie ist nicht möglich, da die Folie zerstört wird. Es muss also im ersten Versuch die Folie sauber aufgebracht werden.

Im zweiten Schritt werden die überstehenden Folienreste mit einem scharfen Cuttermesser entfernt. Dazu wird der Fahnenhalter mit der Folienseite auf eine feste Unterlage gelegt und entlang der Umrandung mit dem Cuttermesser die Überstehende Folie angeschnitten. Als ideale Unterlage kann eine dickere Pappe oder ein Holzbrett verwendet werden.

Abb.: Fahnenhalter Unteransicht (gelb Reflexfolie)

Danach werden die Fahne und der Fahnenhalter verklebt. Dazu wird in die kleine Nut und der untere Fahnenteil mit Aktivator bestrichen. Anschließend kann eine dünne Klebenaht in die Nut gelegt werden und die Fahne in den Fahnenhalter eingeschoben werden. Überschüssige Kleberreste werden mit einem mit Alkohol befeuchteten Tuch entfernt.

In der gleichen Art und Weise wird das Kugellager in den Fahnenrotor eingeklebt. Es ist darauf zu achten, dass nur der Rand des Kugellagers und das Innenteil des Rotors mit Aktivator und Kleber bestrichen werden. Auf keinen Fall darf Kleber in das Kugellagerinnere gelangen.

Abb.: Windfahne Einzelteile

Nachdem der Kleber ausgehärtet ist, kann die Windfahne mit den zwei M3x10 Inbusschrauben auf den Fahnenrotor geschraubt werden.

Als nächstes wir die Spitze mit der silbernen Reflexfolie beklebt. Dazu wird die Folie auf das Maß XX x XX mm zugeschnitten und an der Spitze angebracht. Anschließend wird die Spitze auf die Gewindestange gedreht und mit einem Sprengring und einer Mutter gesichert. An gegenüberliegenden Ende wird zuerst eine Mutter und dann ein Sprengring aufgezogen und dann die Gewindestange bis zum Anschlag in den Fahnenhalter eingedreht.

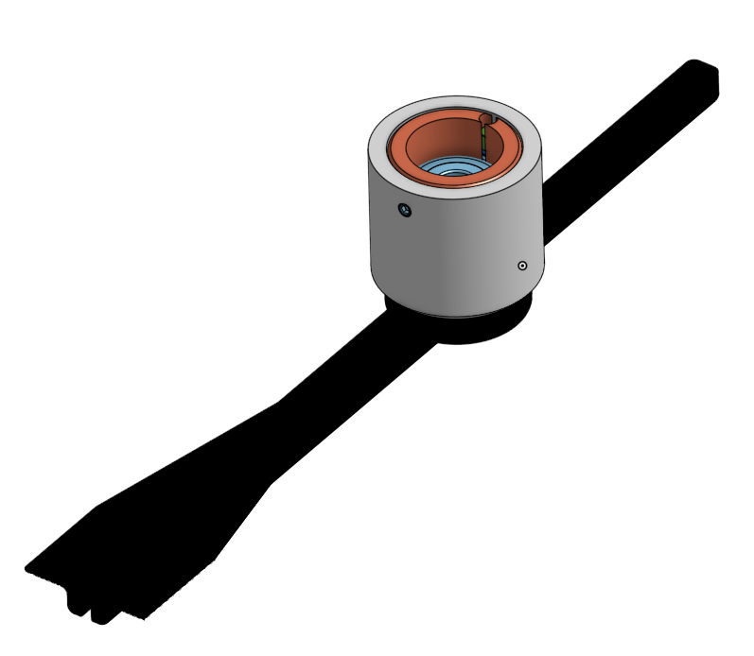
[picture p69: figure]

10/22 | Vers.: 28.06.2018
Abb.: Magnet der Windfahne | Abb.: Eingesetzter Magnethalter mit Magnet

Zum Abschluss der Magnet in den Magnethalter geschoben und der Magnethalter dann in den Fahnenrotor eingesetzt. Der Magnethalter liegt dann am Kugellagerrand auf und schießt bündig mit der Unterseite des Fahnenhalters ab. Der Magnet muss an der gegenüberliegenden Seites der Madenschraube so ausgerichtet sein, dass er auf der Mittellinie des Windfahnenhalters liegt. Mit der Madenschraube kann eine Spannung auf den Magnethalter ausgeübt werden, so dass der Magnet im Schlitz eingeklemmt ist.

### 1.11 Windfahne ausbalancieren

Das Ausbalancieren der Windfahne ist extrem wichtig, um eine leichtgängige Windfahne zu erhalten die sich gut im Wind ausrichten kann. Ist die Windfahne nicht gut ausbalanciert, so kommt es zu erhöhter Lagerreibung und vorzeitigem Verschleiß.

Abb.: Windfahne ausbalancieren

Um die Fahne auszubalancieren, wird der Fahnenrotor auf den Stator aufgeschoben und in eine horizontale Lage gebracht. So entsteht eine Wippe, die mit Hilfe der Spitze ausbalanciert werden muss. Kippt die Wippe in Richtung Spitze, so ist die Spitze näher an den Drehpunkt zu bringen. Kippt die Wippe in Richtung Fahne, so ist in gegengesetzter Richtung vorzugehen. Die Wippe sollte Best möglichst in Balance sein. Hat man diese Position gefunden, so sind die Sicherungsmuttern anzuziehen und die Balance erneut zu prüfen.


Vers.: 28.06.2018 | 11/22

### 1.12 Schalenrad zusammenbauen

Abb.: Schalenrad | Abb.: Richtige Position der Blende

Um das Schalenrad zusammenzubauen wird als erstes das Kugellager eingeklebt und anschließend die Schalen-Stabenden. Zuvor wird Aktivator auf den Außenring des Kugellagers und der entsprechenden Gegenfläche im Rotor bestrichen. Danach wird der Kleber im Rotor aufgetragen und mit einem Q-Tip gleichmäßig verteilt. Dann werden beide Teile zusammengefügt und überschüssiger Kleber mit einem Q-Tip entfernt. In gleicher Weise lassen sich dann die Schalen-Stabenden einkleben. Dabei sind die Stabenden bis zum Anschlag einzuschieben, so dass sie am Kugellager aufsetzen. Die ganze Einheit benötigt dann 24 Stunden zum Aushärten des Klebers. Die Blende ist nach wie vor nur mit Tesafilm fixiert und wird erst nach dem Endtest angeklebt.


12/22 | Vers.: 28.06.2018

### 1.13 Verkabelung der Elektronik

Zur Verkabelung der Elektronik werden die beiden Kabelenden des CAT5e Kabels 50 mm abisoliert und die Einzeladern am Ende auf ca. 5 mm verzinnt. Die 6 Kabelenden werden dann von der Unterseite der Platine mit den Platinenanschlüssen nach Vorgabe des Schaltplans verlötet. Darauf achten, dass keine Kurzschlüsse zwischen den Platinenanschlüssen entstehen. Gegebenenfalls ist überschüssiges Lötzinn mit der Entlötlitze zu entfernen. Zum Abschluss werden die Lötstellen vom Flussmittel mit einem in Alkohol getränktem Q-Tip entfernt. Sofern auf der gegenüberliegenden Anschlussseite des Kabels die Programmierleitungen (Kabel 2, 3, 4, 5) nicht benötigt werden, können sie mit einem Elektronik-Seitenschneider abgeschnitten werden. Darauf achten, dass keine Kurzschlüsse zwischen den abgeschnittenen Kabelenden entstehen. Die Kabel könne dazu leicht versetzt abgeschnitten werden. Das rote und das schwarze Kabel (Kabel 1 und 6) sind die Versorgungsanschlüsse für den Windsensor.

Abb.: Platine mit Lötanschlüssen

Lötanschluss | Aderfarbe | Kürzel | Bedeutung
1 | rot | +5V | Versorgungsspannung 5V
2 | blau | DTR | Programmierung
3 | gelb | RTS | Programmierung
4 | weiß | RXD | Empfangsdaten
5 | braun | TXD | Sendedaten
6 | schwarz | GND | Masse

Tab.: Anschlussbelegung der Kabel


Vers.: 28.06.2018 | 13/22

### 1.14 Ausgangsspannung der DC/DC-Wandler einstellen

Um die beiden DC/DC-Wandler einstellen zu können wird auf der Eingangsseite (In-, In+) eine Spannung von 12V angelegt. Dann wird an der Einstellschraube des blauen Einstell-Potenziometer mit einem kleinen Schraubendreher die geforderte Ausgangsspannung entsprechend der nachfolgenden Tabelle eingestellt. Die Ausgangsspannung wird dazu mit einem Digitalvoltmeter an Out+ und Out-gemessen. Es ist darauf zu achten, dass die Eingangsspannung nicht verpolt angeschlossen wird. In+ bedeutet 12V und In- ist GND. Anderenfalls kann der DC/DC-Wandler zerstört werden. Bei richtiger Polung leuchtet die kleine SMD-LED auf der Platine.

Abb.: Platine des DC/DC-Wandlers

Nachfolgend ist eine Testschaltung mit einer 9V Blockbatterie zur Einstellung der Ausgangsspannung gezeigt.

Abb.: Testschaltung

Verwendung | Eingangsspannung [V]

Ausgangsspannung
[V]
Versorgung des Windsensors | 12 5,5 +/-0,1
Einspeisung in die Toplicht-Leitung | 12 7 +/-0,1

Tab.: Ausgangsspannungen der DC/DC-Wandler


14/22 | Vers.: 28.06.2018

### 1.15 Prüfung der Elektronik und Anbindung an die Anwendungssoftware

Zum Funktionstest der Elektronik werden das rote (+5V) und schwarze Kabel (GND) mit dem Ausgang des 5,5V- DC/DC-Wandlers (Out+, Out-) verbunden. Der Eingang des DC/DC-Wandlers (In+, In-) wird mit 12V- Quelle verbunden. Als Quelle können ein DC Steckernetzteil für 12V, eine Autobatterie oder ein einstellbares Labornetzteil verwendet werden. Nachdem die Spannung zugeschaltet wurde leuchtet die LED des DC/DC-Wandlers. Gleichzeitig leuchtet die blaue LED der Windsensor-Platine. Sie leuchtet so lange, bis sich der Windsensor erfolgreich in ein WLAN-Netzwerk einbuchen konnte. Standardmäßig sind feste Werte für die WLAN-Parameter bei Auslieferung vorgegeben.

Bezeichnung | Default-Werte bei Auslieferung
Verbindungstyp | Client
WLAN | 11 bgn
SSID | MyBoat
Passwort | S6587rr94P
Port | 6666 TCP

Tab.: Default-Werte bei Auslieferung

Testweise kann ein Internet-Router oder Handy mit Hotspot-Funktion auf die WLAN-Parameter eingestellt werden. Sofern richtig parametriert worden ist, sollte sich der Windsensor in das WLAN einbuchen und die blaue LED auf der Platine des Windsensors geht aus. In der Verbindungs-Statusübersicht des Routers oder Handys sollte jetzt der Windsensor als eingebuchtes Gerät sichtbar sein.

Als Vorbereitung für die Endprüfung unter Kapitel 1.21 kann OpenPlotter V0.8.0 auf die WLAN Verbindungsparameter eingestellt werden. Im Konfigurationsprogramm OpenPlotter lassen sich dazu die Einstellungen vornehmen. Zur Aktivierung des WiFi Accesspoints muss die Checkbox [Enable access point] aktiviert werden.

Abb.: Netzwerkkonfiguration in OpenPlotter


Vers.: 28.06.2018 | 15/22

Abb.: Sensorkonfiguration in OpenPlotter

Über den Reiter [NMEA0183] können neue Sensoren im Bereich Inputs, so genannte Devices, hinzugefügt werden indem man auf [+network] geht. Zuvor muss noch die IP-Adresse des Windsensors ermittelt werden. Als Vorbedingung muss sich der Windsensor bereits in das WLAN MyBoat von OpenPlotter eingebucht haben und die blaue LED der Platine aus sein. Unter [Menue] -> [Accessories] -> [Terminal] kann ein Linux Terminalfenster geöffnet werden. In der Kommandozeile wird der Befehl arp -a eingegeben und dann in der Ausgabe die Zeile mit dem Eintrag ESP_XXXXXX gesucht und die zugehörige IP-Adresse entnommen. In unserem Fall ist das die IP 10.10.10.143.

Abb.: Terminalfenster mit Ausgabe der IP-Adressen


16/22 | Vers.: 28.06.2018

Über [+network] kann jetzt der Windsensor hinzugefügt werden. Mit [OK] wird die Eingabe bestätigt.

Abb.: Terminalfenster mit Ausgabe der IP-Adressen

Um die Einstellungen zu übernehmen, muss am Ende der Eintragungen im Fenster [NMEA0183] auf den Button [Apply Changes] gedrückt werden. Anderenfalls werden die Einstellungen nicht übernommen und gehen verloren.

Damit die Daten des Windsensors über OpenPlotter publiziert werden können, muss der der NMEA0183-Server über den Button [Restart] neu gestartet werde. Eine erfolgreiche Verbindung ist im Diagnosemonitor Inspector sichtbar. Es sollten dann alle 2 Sekunde Datenpakete vom Windsensor eintreffen und als Werte für die Windgeschwindigkeit und Windrichtung angezeigt werden.

Abb.: Terminalfenster mit Ausgabe der IP-Adressen


Vers.: 28.06.2018 | 17/22

Unter Umständen können auch noch andere Telegramme eintreffen, die von anderen Sensoren ausgesendet werden. Jedes Mal, wenn ein Telegramm vom Windsensor gesendet wird, leuchtet die blaue LED der Platine als Bestätigung kurz auf. Momentan sind die Werte jedoch noch Null, da die Hallsensoren noch keine Signale von den Magneten erhalten. Sollte die LED dauerhaft an sein, so konnte sich der Windsensor nicht in das WLAN-Netzwerk einbuchen. Ist die LED permanent aus, so besteht eine Verbindung zum WLAN-Netzwerk. Es werden jedoch keine Daten vom Windsensor durch OpenPlotter abgefragt.

Zur Anzeige der NMEA-Daten vom Windsensor kann mit einem Internet-Browse auf das Instrumenten-Panel von OpenPlotter zugegriffen werden. Dazu ist folgende Adresse aufzurufen:

http://10.10.10.1:3000

Dann kann das Instrumenten Panel gestartet und die Anzeigeelemente frei angeordnet werden.

Abb.: Instrumenten Panel in OpenPlotter

Es ist zu beachten, dass immer nur eine Datenverbindung einer Anwendungssoftware zum Windsensor bestehen kann. Ist der Sensor bereits verbunden (hier ist nicht das WLAN gemeint), so kann keine Datenabfrage durch eine andere Anwendungssoftware erfolgen.

In ähnlicher Art und Weise kann die Verbindung auch mit anderer Anwendungssoftware hergestellt werden. Die Diagnosemöglichkeiten sind abhängig von der Funktionalität der Software teilweise eingeschränkt oder gar nicht vorhanden. OpenCPN eignet sich ebenfalls sehr gut als Testsoftware da auch ein Diagnosemonitor für die NMEA-Datenpakete vorhanden ist.


18/22 | Vers.: 28.06.2018

### 1.16 Zusammenbau des Frames mit Halterung

Beim Zusammenbau des Frames wird als erstes das Rohr mit dem Frame verklebt. Beide Klebflächen, sowohl Rohr als auch der Frame sind entsprechend mit Aktivator einzupinseln. Nach der Abtrockenzeit des Aktivators wird der Kleber in der Rohraufnahme des Frames mit einem Q-Tip gleichmäßig verteilt. Anschließend wird das Rohr bis zum Anschlag in den Frame geschoben. Nach der Aushärtung des Klebers kann der Befestigungsfuß am Rohr angebracht werden.

Abb.: Frame mit Standrohr und Befestigungsfuß

### 1.17 Justage des Windgeschwindigkeits-Magneten

Die Justage des Windgeschwindigkeits-Magneten gestaltet sich recht einfach. Dazu ist der Magnet D3x6 in das seitliche 3mm Loch des Schalenrades einzuführen. Der Magnet wird so tief eingeschoben, dass er bei aufgesetztem Schalenrad in jeder Betriebslage nicht den Stator berührt. Es sollte ein Luftspalt von 0,3G0,5 mm vorhanden sein. Mit einem Digitalvoltmeter oder in OpenPlotter kann die Funktion überprüft werden. Ist bei rotierenden Schalenrad kein Messwert sichtbar, so ist die Polung des Magneten falsch und der Magnet muss anders herum eingebaut werden. Ist die korrekte Funktion gegeben, so kann der Magnet mit einem Tropfen Sekundenkleber fixiert werden.

### 1.18 Justage des Windrichtungs-Magneten

Die Justage des Windrichtungs-Magneten gestaltet sich etwas aufwändiger, da eine sichere Schaltschwelle für alle Windrichtungen gefunden werden muss während sich das Schalenrad dreht.

Im ersten Schritt werden die Windfahne und das Schalenrad auf den Stator gesetzt. Der Magnet D3x3 ist vorher in den kleinen Schlitz des Fahnenrotors bis zur Mitte einzuführen. Dann wird bei fixierter Windfahne das Schalenrad um 360° gedreht und mit einem Digitalvoltmeter die Schaltzustände des Hallsensors überprüft. Für ungefähr eine halbe Umdrehung muss das Signal an sein und für den Rest der Umdrehung aus sein. Je Umdrehung darf der Hallsensor jeweils 1x an und 1x aus sein. Im nachfolgenden Bild ist das korrekte Schaltverhalten der beiden Hallsensoren im Oszilloskop zu sehen.


Vers.: 28.06.2018 | 19/22

Abb.: Zeitliche Signalverläufe der Hallsensoren (rot Windgeschwindigkeit, gelb Windrichtung)

Schaltet der Hallsensor gar nicht, dauerhalt oder mehrmals, so ist die Position des Magneten zu variieren und das Ergebnis zu überprüfen. Hat man eine korrekte Position gefunden, so muss nun für alle weiteren Windrichtungen die Windfahne im Winkel verändert werden und ebenfalls das korrekte Schaltverhalten überprüft werden. Das Problem besteht darin, dass der Hallsensor für jede Winkelrichtung unterschiedlich empfindlich ist und die Schaltschwelle je nach Richtung des Magnetfeldes verschieden ausfällt. Die Reduzierung des Magnetfeldes durch die Blende muss ausreichend groß ausfallen, um ein korrektes Schaltverhalten zu erzeugen. Im nachfolgenden Diagramm ist das Verhalten des Hallsensors zu sehen.

Abb.: Schaltverhalten des Hallsensors für die Windrichtung

Der Hallsensor schaltet immer dann, wenn die blaue Kurve (Magnetfeldstärke) oberhalb der orangen Kurve (Schaltschwelle) liegt. Im Diagramm sind 2 eingeschaltete und 2 ausgeschaltete Zustände zu sehen. Das Magnetfeld am Sensor muss angehoben werden, um genau einen eingeschalteten und

20/22 | Vers.: 28.06.2018

einen ausgeschalteten Zustand zu erreichen. Durch Veränderung der Magnetposition entlang der Nut kann die Magnetfeldstärke verändert werden. Die blaue Linie im Diagramm verschiebt sich dann nach oben oder unten. Wird die Windfahne verdreht, so versetzt sich die blaue Linie seitwärts je nach Drehrichtung. Wie im Diagramm zu sehen ist, erzeugt die Blende kein sauber rechteckig reduziertes Magnetfeld beim Blendendurchlauf. Das liegt hauptsächlich daran, dass die halb geöffnete Blende das Magnetfeld in den Halbkreis hereinzieht, weil das Magnetfeld innerhalb der Blende entlang des geringsten magnetischen Widerstandes langlaufen möchte.


Abb.: Magnetfeldverläufe bei verschiedenen Blendenpositionen

### 1.19 Funktionstest

Im Funktionstest werden alle Teile so zusammengefügt wie sie im Endzustand sein sollen, mit der Ausnahme, dass die Teile noch nicht zusammengeklebt werden. Dazu wird das Verbindungskabel durch den Frame, das Standrohr und den Befestigungsfuß gezogen. Bevor die Platine in den Stator eingeschoben wird, muss der Hallsensor an der Spitze des schmalen Steges gegen Kurzschlüsse geschützt werden. Dazu wird ein Stück Tesafilm so außen herum um den Hallsensor und die Platine gewickelt, dass die Anschlusspins und die Anschlussbeine des Hallsensors geschützt sind. Danach kann die Platine bis zum Anschlag in den Stator eingeschoben werden. Als nächstes wird der Stator mit dem Frame verbunden und anschließend das Schalenrad und die Fahne aufgesetzt.

Der Funktionstest läuft jetzt wie unter 1.15 ab. In der Anwendungssoftware kann dann die korrekte Funktion überprüft werden. Es ist hilfreich, wenn dazu ein Zeigerinstrument benutzt wird. So lassen sich die Winkelpositionen optisch besser mit der Position der Windfahne vergleichen. Wenn die Windfahne langsam um 360° gedreht wird, dürfen keine Sprünge in der Winkelanzeige auftreten. Sind Sprünge vorhanden, so deutet das auf ein fehlerhaftes Schaltverhaltender hin und der Magnet des Windrichtungssensors muss noch einmal neu eingestellt werden. Anschließend sollte man noch die komplementären Windrichtungen 0°-180° und 90° -270° testen und prüfen, ob die Anzeigewerte der Winkel korrekt sind.

Zum Abschluss werden die Kugellager der Windfahne und des Schalenrades leicht eingeölt. Überschüssiges Öl ist unbedingt zu entfernen. Es sollte sehr sparsam eingeölt werden, damit das Öl nicht nachträglich auslaufen kann.

### 1.20 Stator einkleben

Nachdem alle Vorarbeiten und Tests erfolgreich abgelaufen sind, kann der Stator in den Frame eingeklebt werden. Man sollte sich aber sicher sein, dass der Windsensor ordnungsgemäß funktioniert, da ein nachträgliches Öffnen nicht ohne Zerstörung des Frames möglich ist. Bevor man die Teile zusammenklebt, sollte man prüfen, ob die Platine im zusammengesteckten Zustand von


Vers.: 28.06.2018 | 21/22

Stator und Frame festsitzt und kein Spiel entlang der Hauptachse hat. Das kann durch leichtes ziehen und drücken am Anschlusskabel geprüft werden. Anderenfalls könnte der Hallsensor der Windrichtungsmessung im Betrieb verrutschen und die Schaltschwellen des Sensors verändern. Sollte ein kleines Spiel vorhanden sein, so kann ein kleines Stück Schaumgummi in die Vertiefung des Frames eingelegt werden, der die Platine in Richtung Stator drückt.

Abb.: Frame, Platine und Stator | Abb.: Platine in Stator geschoben

Alternativ kann die eingesteckte Platine im Stator bis zum Rand des Stators mit Silikon ausgefüllt werden.

Die Klebung erfolgt wie gehabt an der Kontaktfläche zwischen Stator und Frame. Herausquellender Kleber sollte mit einem Tuch so entfernt werden, so dass eine saubere Fuge am Übergang Stator-Frame entsteht. Die Fuge muss durchgängig mit Kleber gefüllt sein, um eine ausreichende Dichtheit gegenüber Wasser zu erzielen.

### 1.21 Endprüfung

Bei der Endprüfung werden die gleichen Test wie im Funktionstest unter 1.19 durchgeführt. Eventuell auftretende Schalt- oder Winkelfehler können jetzt noch korrigiert werden, falls sich die Position der Platine nach der Verklebung von Stator und Frame noch einmal verändert haben sollte.

Zum Schluss sollte man noch eine Markierung am Frame anbringen der die Mittschiffsposition (0°-Position) markiert. So lässt sich dann der Windsensor problemlos am Mast in die richtige Position ausrichten und die Werte werden korrekt in der Anwendungssoftware angezeigt.

### 1.22 Blende und Magnet einkleben

Zum Abschluss werden die Blende eingeklebt und der Magnet des Fahnenrotors gesichert

Die Blende sollte möglichst ohne zu verkanten und ohne Luftspalt bündig am Außenrand des Rotors angeklebt werden. Zur Fixierung der Blende kann ein passender Kabelbinder verwendet werden.

Der Magnet des Fahnenrotors sichert man, indem die gegenüberliegende Madenschraube vorsichtig angezogen wird und der Magnet mit einem Tropfen Sekundenkleber gesichert wird. Die Madenschraube sollte nicht zu stark angezogen werden, da der Fahnenrotor aufgrund der hohen Kräfte einreißen könnte. Schon kleine Kräfte sind ausreichend um den Magneten sicher im Spalt einzuklemmen.

22/22 | Vers.: 28.06.2018

### 1.23 Weiterführende Informationen

1) OpenPlotter: http://www.sailoog.com/openplotter
2) OpenPlotter Video: https://www.youtube.com/watch?v=LJyOYgIw6L4
3) OpenCPN: https://opencpn.org/
4) Weikon RK-1300:https://www.weicon.de/anwendungsbereiche/kleben-und-abdichten/grosse-teile-verbinden/schnellhaertend-schlagzaeh/243/rk-1300-acrylat-strukturklebstoff
5) Weikon Video: https://www.youtube.com/watch?v=JJsYCqT3pSQ
6) Tips zum Löten: http://www.hobby-bastelecke.de/basteltips/loeten.htm
7) Löten Video: https://www.youtube.com/watch?v=Arj34uQoLdM
8) Digitalvoltmeter Video: https://www.youtube.com/watch?v=cfriwhure3I

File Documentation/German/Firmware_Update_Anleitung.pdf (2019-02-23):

# Firmware-Update-Anleitung

Die bis jetzt ausgelieferten Windsensoren enthalten folgende Firmware:

NMEA_Windsensor_11_final_MyBoat.bin (https://gitlab.com/norbertwalter67/Windsensor_WiFi_1000/blob/master/Arduino-Code/NMEA_Windsensor_11_final_MyBoat.bin)

Mit dieser Firmware kann nur über feste WLAN-Parameter eine Kommunikation zum Windsensor aufgebaut werden. Die Firmware beinhaltet auch eine Update-Webinterface welches nur in ganz bestimmten Konstellationen zu erreichen ist, da die ausgelieferte Firmware noch Fehler enthält. Diese Anleitung beschreibt welche Schritte unternommen werden müssen, um die Software aktualisieren zu können. Nach dem Update ist der Windsensor unter den gleichen Netzwerkparametern erreichbar wie die alte Firmware.

## Benötigte Hilfsmittel:

- Raspi mit OpenPlotter oder WLAN-Router
- Laptop oder Handy mit HTML-Browser und Internetzugang

### 1. Einrichten eines WLANs auf dem Raspi oder einem WLAN-Router

(z.B. FritzBox) mit folgenden Parametern:

SSID: MyBoat
Password: S6587rr94P

### 2. Windsensor an Versorgungsspannung (mit DC/DC-Wandler!)

anschließen.


Abb.: Spannungsversorgung des Windsensors

Es leuchtet die blaue LED auf. Wenn sich der Windsensor in das WLAN erfolgreich einbuchen konnte, dann verlischt die blaue LED. Es ist wichtig, dass sich der Windsensor in das WLAN MyBoat einbuchen kann. Es dürfen aber keine Daten durch OpenPlotter abgerufen werden. Ggf. muss die Datenverbindung in OpenPlotter deaktiviert werden. Die blaue LED darf auf keinen Fall blinken. Das wäre ein Hinweis, dass Daten abgerufen werden. Sie muss dauerhaft aus sein. Nur in diesem Zustand kann das Web-Updateinterface geöffnet werden.

### 3. Mit dem Laptop oder Handy bei GitLab Firmware runterladen:

https://gitlab.com/norbertwalter67/Windsensor_WiFi_1000/blob/master/Arduino-Code/firmware_V1.01.wsb (https://gitlab.com/norbertwalter67/Windsensor_WiFi_1000/blob/master/Arduino-Code/firmware_V1.01.wsb)

### 4. Mit dem Laptop oder Handy in das WLAN des Windsensors

einbuchen:

SSID: NoWa
Password: 12345678

### 5. HTML-Browser öffnen und folgende Seite aufrufen:

http://192.168.4.1/update

Es kommt eine kleine Webseite zum Vorschein, wo man eine Firmware auswählen kann. Dort jetzt die zuvor unter 3. gespeicherte Firmware mit dem Namen Firmware_V1.01.wsb auswählen und dann auf den Button Update drücken. Sobald die Firmware erfolgreich übertragen wurde erscheint ein OK. Kommt eine Fehlermeldung, so wurde die falsche Firmware übertragen oder die Übertragung war nicht erfolgreich . Falls notwendig, den Vorgang noch einmal wiederholen.

### 6. Windsensor stromlos machen ein klein wenig warten und dann die

Versorgungsspannung wieder zuschalten. Dadurch wurde im Windsensor die neue Firmware gestartet.

### 7. Zur Kontrolle es Updates und zur Änderung der Netzwerkparameter kann

im HTML-Browser jetzt folgende Seite aufrufen werden:

http://192.168.4.1

Es sollte sich nun die neue Firmware mit der schwarzen Startseite und der Version V1.0.1 zeigen.


Unter Device Info können die aktuellen Netzwerkparameter eingesehen werden. Mit dieser Firmware können jetzt die Netzwerkparameter unter Device Settings verändert und dauerhaft mit Save gespeicherten werden. Nach einem Neustart stehen die Einstellungen wieder zur Verfügung, da sie im EEPROM des Windsensors gespeichert werden.

### 9. Zur Aktivierung der neuen Netzwerkparameter muss der Windsensor

noch einmal neu gestartet werden indem er kurz stromlos gemacht wird.

Grundsätzlich lassen sich die Netzwerkparameter beliebig ändern. Es ist jedoch zu beachten, dass Sie für die SSID und das Passwort max. 20 Zeichen und nur Zahlen und Buchstaben verwenden können. Sonderzeichen sind nicht erlaubt. Passworte müssen mindestens 8 Zeichen und SSID mindestens 1 Zeichen lang sein. Bei Nichtbeachtung folgt eine Fehlermeldung.

Wenn man sich nicht in ein externes WLAN einbuchen möchte, so sind
trotzdem | Verbindungsparameter | einzutragen. | Tippen | Sie | die
Netzwerkparameter korrekt ein und notieren Sie sich unbedingt die Werte! Vergessene Einstellungen können nicht ohne weiteres rückgängig gemacht werden. Die Firmware muss dann über die serielle Schnittstelle manuell neu geflasht werden.

Weiter Updates erfolgen dann über die Web-Konfiguration unter Update Firmware.

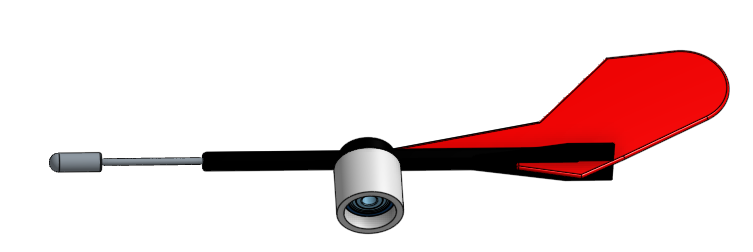
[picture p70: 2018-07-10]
Pictures/Assembly3D/Windfahne_ausbalancieren.png

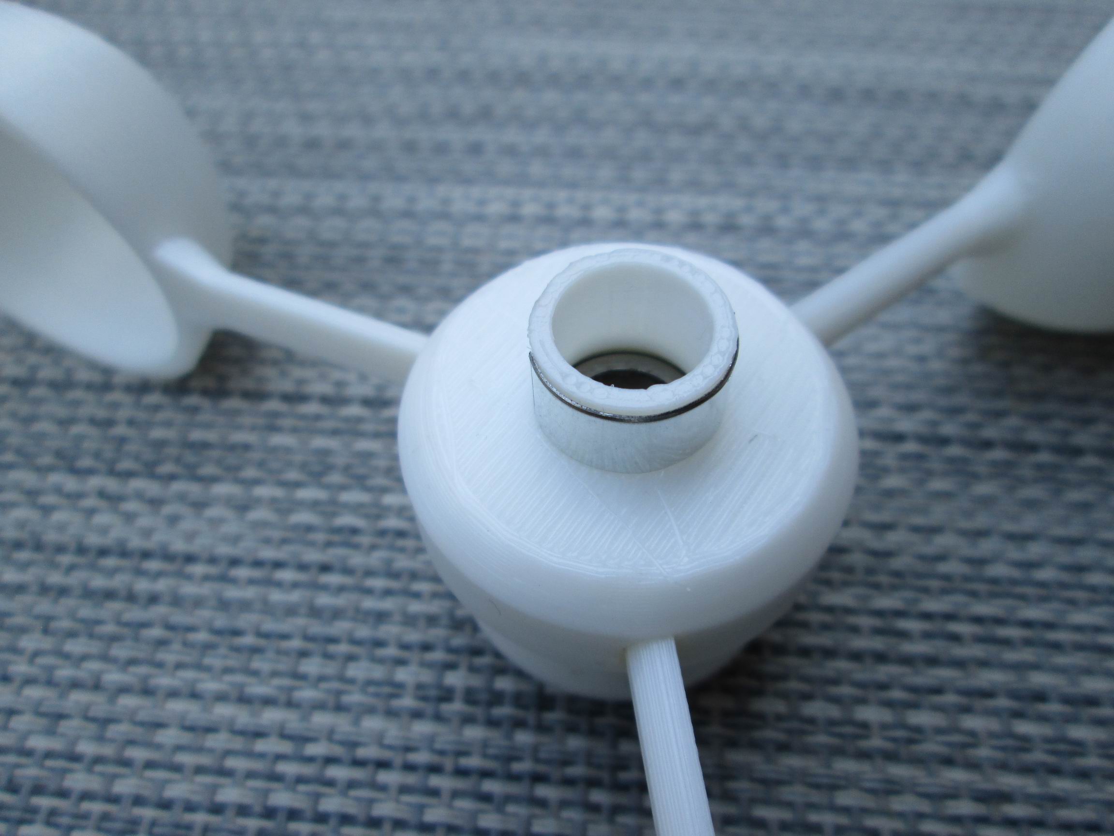
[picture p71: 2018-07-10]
Pictures/AssemblyReal/GrößenänderungIMG_3761.JPG

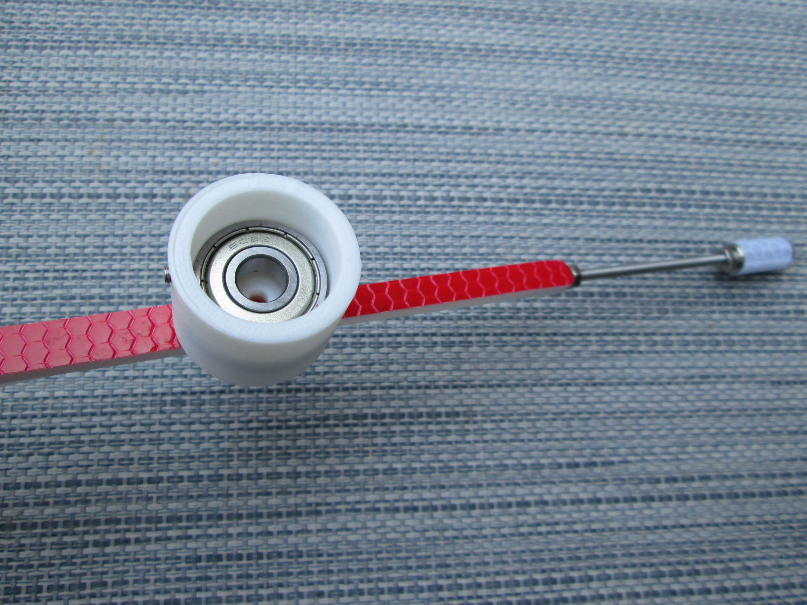
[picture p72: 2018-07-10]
Pictures/AssemblyReal/GrößenänderungIMG_3771.JPG

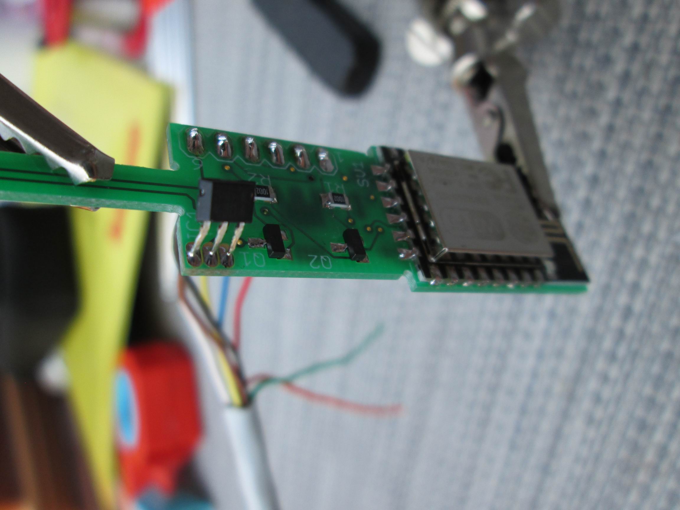
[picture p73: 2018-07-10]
Pictures/AssemblyReal/GrößenänderungIMG_3814.JPG

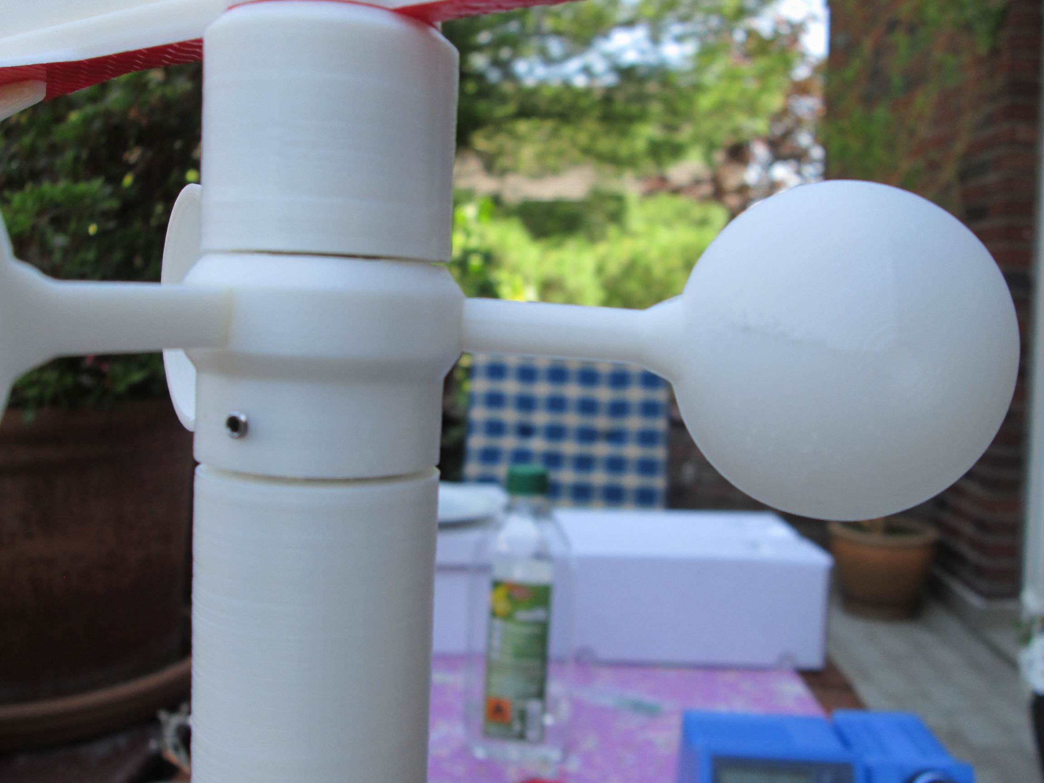
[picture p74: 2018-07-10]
Pictures/AssemblyReal/GrößenänderungIMG_3787.JPG

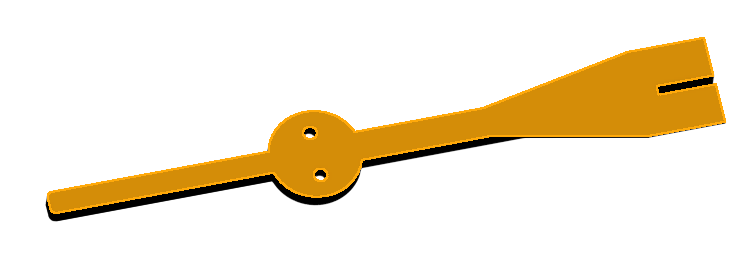
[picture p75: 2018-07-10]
Pictures/Assembly3D/Fahnenhalter_Folie.png

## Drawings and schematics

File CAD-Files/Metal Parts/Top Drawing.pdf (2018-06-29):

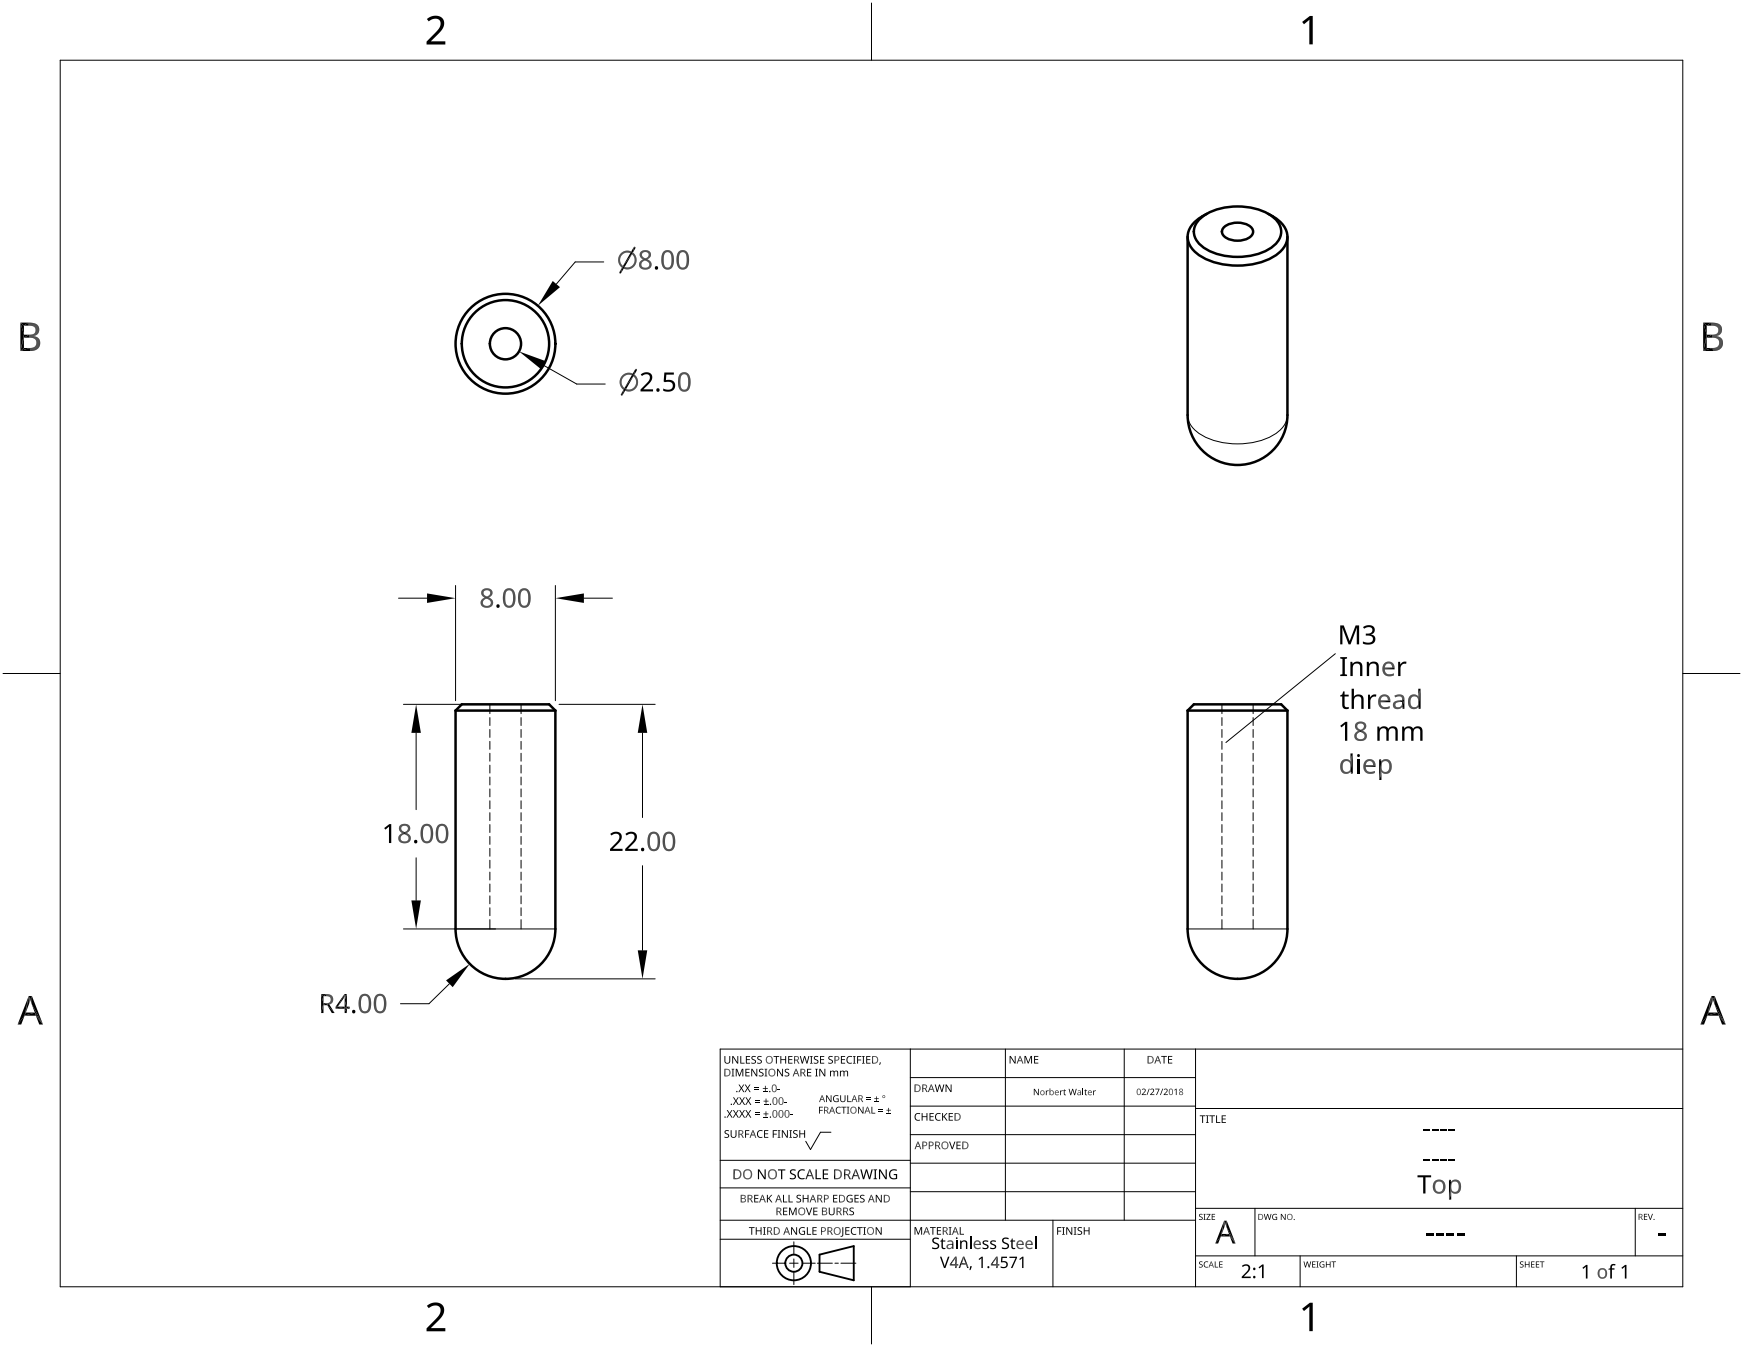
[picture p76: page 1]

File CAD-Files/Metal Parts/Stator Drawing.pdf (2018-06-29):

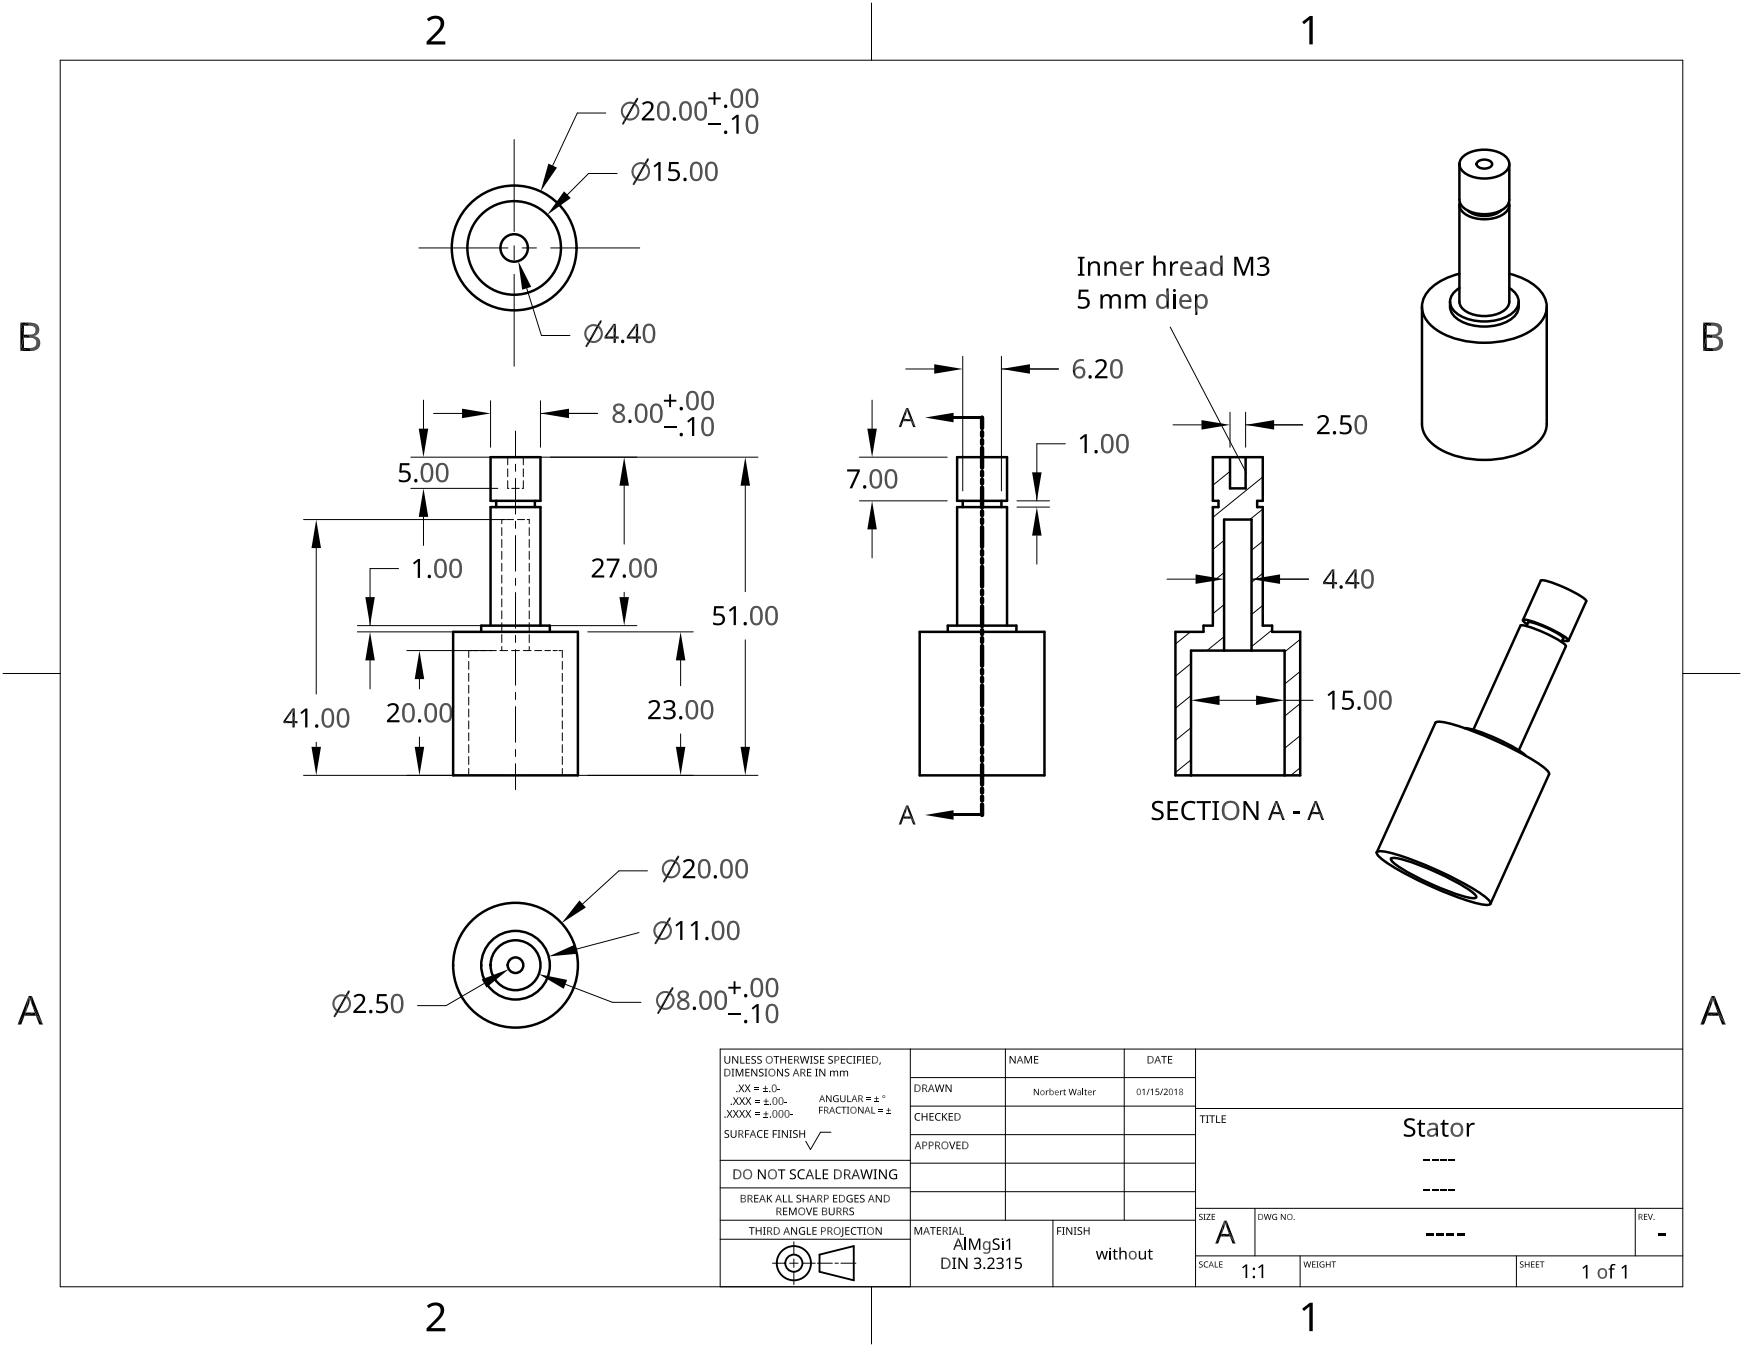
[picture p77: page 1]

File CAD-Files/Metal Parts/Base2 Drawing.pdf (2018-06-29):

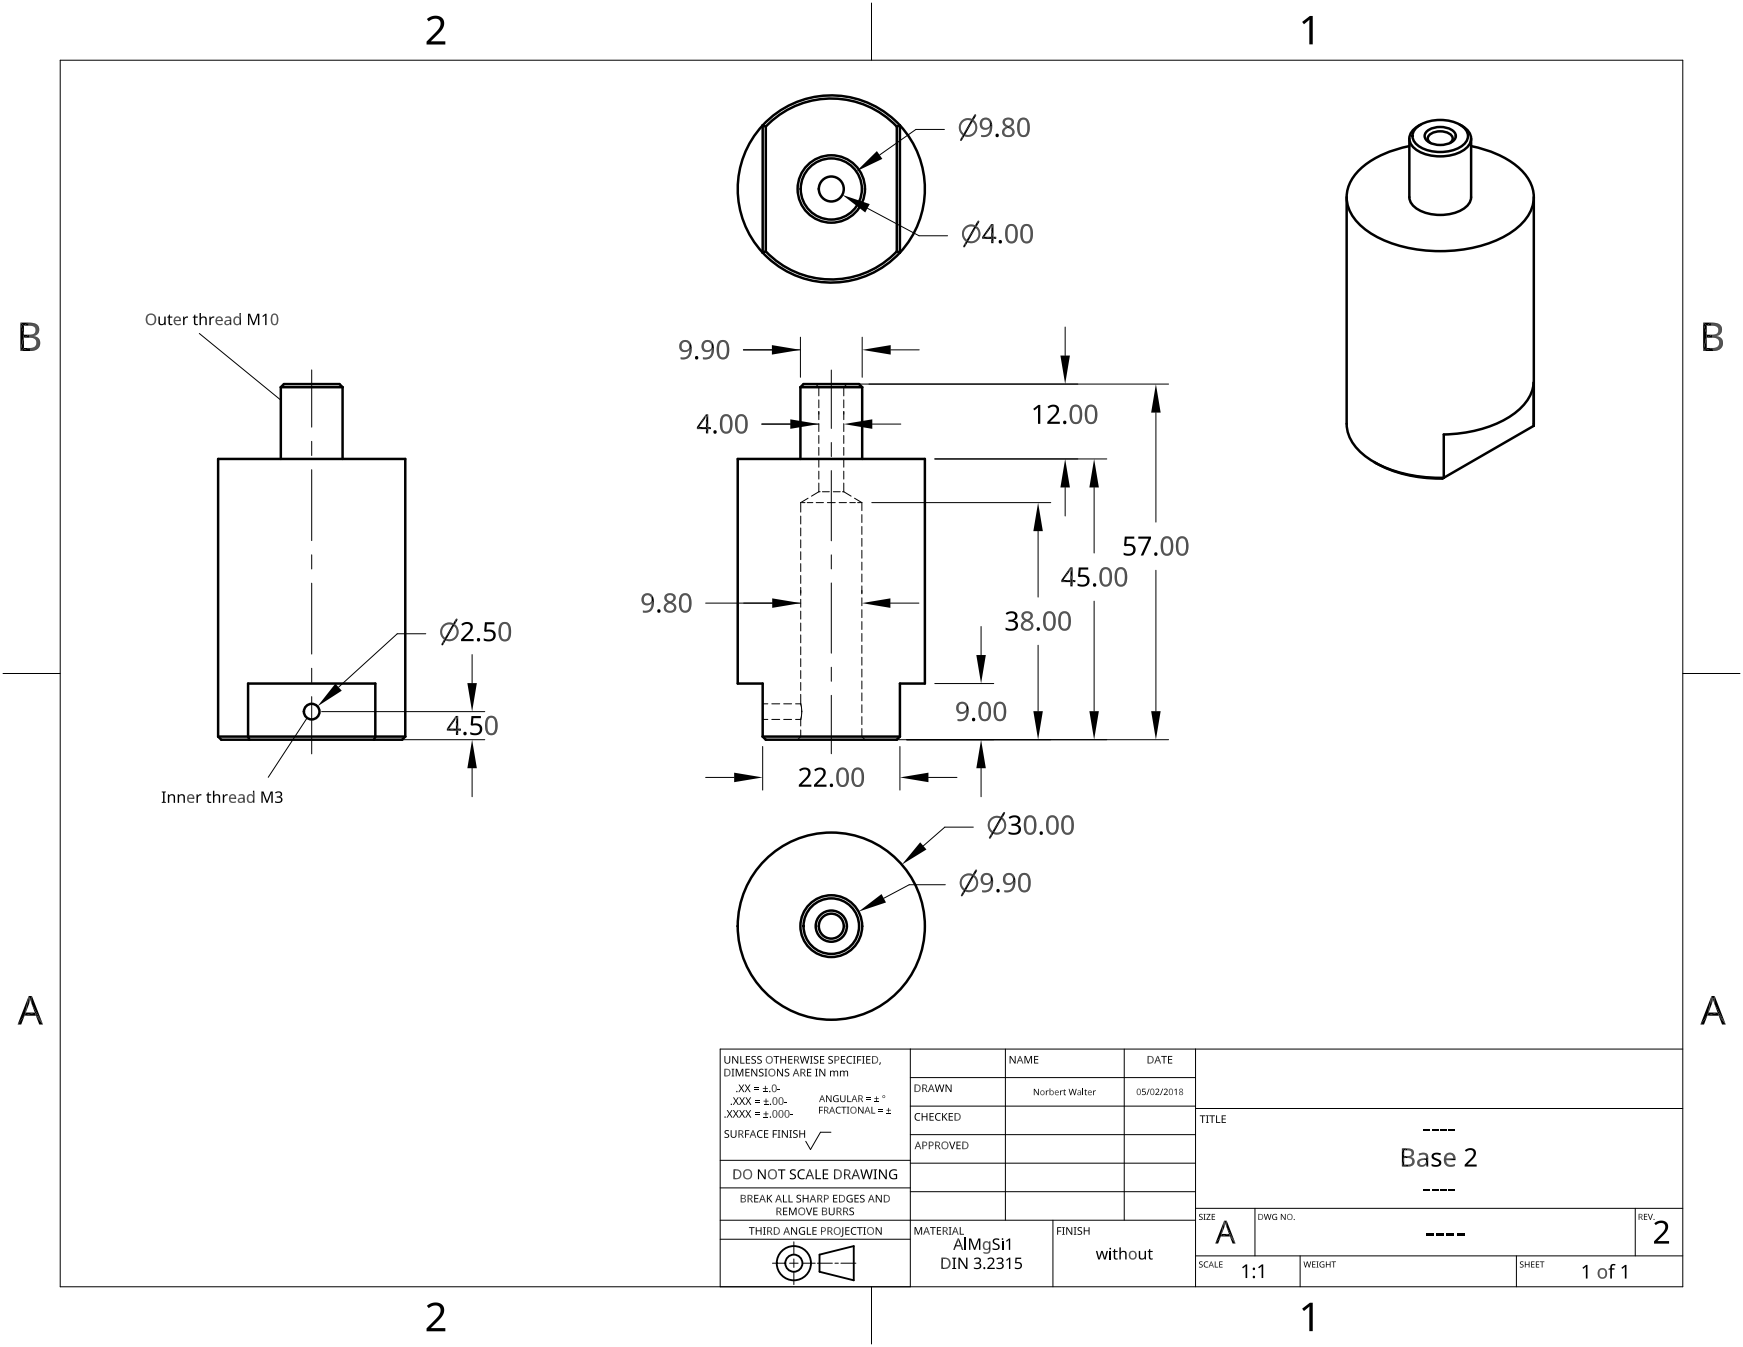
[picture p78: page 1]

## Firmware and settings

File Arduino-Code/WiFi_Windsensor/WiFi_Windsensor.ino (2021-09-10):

//*********************************************************************************************
// WiFi and NMEA server for transmitting wind sensor data via TCP connection
// (C) Norbert Walter 2021
// License: GNU GPL V3
// https://www.gnu.org/licenses/gpl-3.0.txt
//
// WiFi_Windsensor.ino
//
// Tested and compiled with Arduino IDE 1.8.5
// Board esp8266 V2.5.2 (SDK 2.2.1 (cfd48f3))
// The server use different NMEA centeces
//
// Wind direction and speed:  $WIMWV,x.x,a,x.x,a,A*hh
// Wind direction and speed:  $WIVWR,x.x,a,x.x,N,x.x,M,x.x,K*hh
// Down wind speed:           $WIVPW,x.x,N,x.x,M*hh                               (Wind speed parallel to wind direction)
// Wind speed informations:   $PWINF,0,x.x,D,x.x,D,x.x,M,x.x,K,x.x,N,x.x,B,A*hh   (Custom sentence)
// Wind sensor temperature:   $PWWST,C,0,x.x,A*hh                                 (Custom sentence)
//
//*********************************************************************************************

// Includes
#include <ESP8266WiFi.h>    // WiFi lib with TCP server and client

#include <WiFiClient.h>             // WiFi lib for clients
#include <ESP8266WebServer.h>       // WebServer lib
#include <ESP8266mDNS.h>            // DNS lib
#include <ESP8266HTTPUpdateServer.h>// Web Update server

#include <Ticker.h>         // Timer lib
#include <EEPROM.h>         // EEPROM lib
#include <WString.h>        // Needs for structures
#include <OneWire.h>        // 1Wire network lib
#include <Wire.h>           // Lib for I2C
#include <Adafruit_Sensor.h>// Adafuit sensor lib
#include <Adafruit_BME280.h>// Lib for BME280
#include <AS5600.h>         // Lib for magnetic rotation sensor AS5600
#include <DallasTemperature.h>// Dallas 1Wire lib
#include <SimplyAtomic.h>   // This library includes the ATOMIC_BLOCK macro
#include "Configuration.h"  // Setup data structure in header file
#include "Definitions.h"    // Local definitions in additional file

AMS_5600 ams5600;           // Declare magnetic rotation sensor AS5600
Adafruit_BME280 bme;        // Declare environment sensor BME280
OneWire oneWire(ONE_WIRE_BUS); // Declare 1Wire
DallasTemperature DS18B20(&oneWire); // Declare DS18B20
configData actconf;         // Actual configuration, Global variable
                            // Overload with old EEPROM configuration by start. It is necessarry for port and serspeed
                            // Don't change the position!

#include "Calculation.h"    // Function library for wind data calculation
#include "FunctionsLib.h"   // Function library
#include "NMEATelegrams.h"  // Function library for NMEA telegrams
#include "icon_html.h"      // Favorit icon
#include "css_html.h"       // CSS cascading style sheets
#include "steel_html.h"     // JavaScript steelseries_micro.js.gz library
#include "tween_html.h"     // JavaScript tween-min.js.gz library
#include "js_html.h"        // JavaScript functions
#include "main_html.h"      // Main webpage
#include "settings_html.h"  // Settings webpage
#include "firmware_html.h"  // Firmware update webpage
#include "json_html.h"      // JSON webpage
#include "json2_html.h"     // JSON webpage for Hall sensor signals
#include "MD5_html.h"       // JavaScript crypt password with MD5
#include "restart_html.h"   // Reset info webpage
#include "devinfo_html.h"   // Device info webpage
#include "windv_html.h"     // Wind value webpage
#include "windi_html.h"     // Wind instrument webpage
#include "error_html.h"     // Error 404 webpage

// Declarations
int value;                  // Value from first byte in EEPROM
int empty;                  // If EEPROM empty without configutation then set to 1 otherwise 0
configData defconf;         // Definition of default configuration data
configData oldconf;         // Configuration stucture for old config data in EEPROM
configData newconf;         // Configuration stucture for new config data in EEPROM

ESP8266WebServer httpServer(actconf.httpport);  // Port for HTTP server
ESP8266HTTPUpdateServer httpUpdater;            // Declaration update server
MDNSResponder mdns;                             // Activate DNS responder

Ticker Timer2;              // Declare Timer2 for average building
Ticker Timer3;              // Declare Timer3 for normal NMEA data sending
Ticker Timer4;              // Declare Timer4 for reduced NMEA data sending
Ticker Timer5;              // Declare Timer5 for calculation of windspeed und winddirection 
WiFiServer server(actconf.dataport);  // Declare WiFi NMEA server port
 
//*********************************************************************************************
// Setup section
//*********************************************************************************************
void setup() {
   // Start bus systems
   Wire.begin();                        // Start I2C
   bme.begin(i2cAddressBME280);         // Start BME280

   // !!!!!! Uncomment this line if you using a new configuration structure !!!!!!
//  saveEEPROMConfig(defconf);
  
  // Read the first byte from the EEPROM
  EEPROM.begin(sizeEEPROM);
  value = EEPROM.read(cfgStart);
  EEPROM.end(); 
  // If the fist Byte not identical to the first value in the default configuration then saving a default configuration in EEPROM.
  // Means if the EEPROM empty then saving a default configuration.
  if(value == defconf.valid){
    empty = 0;                  // Marker for configuration is present
  }
  else{
    saveEEPROMConfig(defconf);
    empty = 1;                  // Marker for configuration is missing
  }

  // Loading EEPROM configuration
  actconf = loadEEPROMConfig(); // Overload with old EEPROM configuration by start. It is necessarry for serspeed

  // If the firmware version in EEPROM different to defconf then save the new version in EEPROM
  if(String(actconf.fversion) != String(defconf.fversion)){
    String fver = defconf.fversion;
    fver.toCharArray(actconf.fversion, 6);
    saveEEPROMConfig(actconf);
  }
 
  // Pin definitions and settings for wind sensor types Yachta and Jukolein
  if(String(actconf.windSensorType) == "Jukolein"){
    
    // Pin redefinition for other wind sensor types (Original values see Definition.h)
    // Attention! GPIO 12 is not available! (1Wire)
    // Existing pins
    ledPin = 14;                // LED GPIO 14 (fake) (D5)
    INT_PIN1 = 2;               // Wind speed GPIO 2 (Hall sensor) (D4)
    INT_PIN2 = 16;              // Wind direction GPIO 16 (Hall sensor fake) (D0)
    // New pins
    int SCL = 5;                // Wind direction magnetic sensor SCL GPIO 5 (AS5600) (D1)
    int SDA = 4;                // Wind direction magnetic sensor SDA GPIO 4 (AS6500) (D2)
  }

  // Pin definitions and settings for wind sensor types Ventus
  if(String(actconf.windSensorType) == "Yachta" || String(actconf.windSensorType) == "Ventus"){
    
    // Pin redefinition for other wind sensor types (Original values see Definition.h)
    // Attention! GPIO 12 is not available! (1Wire)
    // Existing pins
    ledPin = 2;                 // LED GPIO 2 (D4)
    INT_PIN1 = 14;              // Wind speed GPIO 14 (Reed switch) (D5), pin need 10k and 100n for spike reduction
    INT_PIN2 = 16;              // Wind direction GPIO 16 (Hall sensor fake) (D0)
    // New pins
    int SCL = 5;                // Wind direction magnetic sensor SCL GPIO 5 (AS5600) (D1)
    int SDA = 4;                // Wind direction magnetic sensor SDA GPIO 4 (AS6500) (D2)
  }
  
  // Pin settings
  pinMode(INT_PIN1, INPUT_PULLUP);  // Interrupt input 1 speed
  pinMode(INT_PIN2, INPUT_PULLUP);  // Interrupt input 2 direction
  pinMode(ledPin, OUTPUT);          // LED Pin output
  digitalWrite(ledPin, LOW);        // Switch LED on (inverted!)

  Serial.begin(actconf.serspeed);   // Start serial communication
  delay(10);

//  DebugPrint(3, "First EEPROM byte: ");
//  DebugPrintln(3, value);

  // ESP8266 Information Data
  DebugPrintln(3, "Booting Sketch...");
  DebugPrint(3, actconf.devname);
  DebugPrint(3, " ");
  DebugPrint(3, actconf.windSensorType);
  DebugPrint(3, " ");
  DebugPrint(3, actconf.fversion);
  DebugPrintln(3, " (C) Norbert Walter");
  DebugPrintln(3, "*********************************************");
  DebugPrintln(3, "");
  DebugPrintln(3, "Modul Type: ESP8266");
  DebugPrint(3, "SDK-Version: ");
  DebugPrintln(3, ESP.getSdkVersion());
  DebugPrint(3, "ESP8266 Chip-ID: ");
  DebugPrintln(3, ESP.getChipId());
  DebugPrint(3, "ESP8266 Speed [MHz]: ");  
  DebugPrintln(3, ESP.getCpuFreqMHz());
  DebugPrint(3, "Free Heap Size [Bytes]: ");
  DebugPrintln(3, ESP.getFreeHeap());
  DebugPrintln(3, "");
  DebugPrint(3, "Sensor ID: ");
  DebugPrintln(3, actconf.sensorID);
  DebugPrint(3, "Wind Sensor Type: ");
  DebugPrintln(3, actconf.windSensorType);
  DebugPrintln(3, "Sensor Type: Wind Speed");
  DebugPrint(3, "Input Pin: GPIO ");
  DebugPrintln(3, INT_PIN1);
  DebugPrintln(3, "Value Range [kn]: 0...73");
  DebugPrint(3, "Sensor Type: ");
  if(String(actconf.windType) == "R"){
      DebugPrintln(3, "Relative ");
    }
    else{
      DebugPrintln(3, "True ");
    }    
  if(String(actconf.windSensorType) == "WiFi 1000"){  
    DebugPrintln(3, "Wind direction");
    DebugPrint(3, "Input Pin: GPIO ");
    DebugPrintln(3, INT_PIN2);
    DebugPrintln(3, "Value Range [°]: 0...360");
  }
  if(String(actconf.windSensorType) == "Yachta" || String(actconf.windSensorType) == "Jukolein" || String(actconf.windSensorType) == "Ventus"){
    DebugPrintln(3, "Wind direction: AS5600");
    DebugPrint(3, "SCL: GPIO ");
    DebugPrintln(3, SCL);
    DebugPrint(3, "SDA: GPIO ");
    DebugPrintln(3, SDA);
    DebugPrint(3, "Scan I2C at address 0x");
    if (i2cAddressAS5600 < 0x10) {
      DebugPrint(3, "0");
    }
    DebugPrint(3, String(i2cAddressAS5600, HEX));
    DebugPrint(3, ": ");
    Wire.beginTransmission(i2cAddressAS5600);
    if(Wire.endTransmission() == 0){
      i2creadyAS5600 = 1;                        // Result I2C scan
      DebugPrintln(3, "ready");
      DebugPrint(3, "Magnitude [1]: ");
      DebugPrintln(3, ams5600.getMagnitude());
      DebugPrint(3, "Raw Angle [°]: ");
      magsensor = ams5600.getRawAngle() * 0.087; // 0...4096 which is 0.087 of a degree
      DebugPrintln(3, magsensor);
    }
    else{
      i2creadyAS5600 = 0;                        // Result I2C scan
      DebugPrintln(3, "error");
      DebugPrintln(3, "Stop I2C for device AS5600");
    }
  }
  if(String(actconf.windSensorType) == "Ventus"){
    DebugPrintln(3, "Environment Sensor: BME280");
    DebugPrint(3, "SCL: GPIO ");
    DebugPrintln(3, SCL);
    DebugPrint(3, "SDA: GPIO ");
    DebugPrintln(3, SDA);
    DebugPrint(3, "Scan I2C at address 0x");
    if (i2cAddressBME280 < 0x10) {
      DebugPrint(3, "0");
    }
    DebugPrint(3, String(i2cAddressBME280, HEX));
    DebugPrint(3, ": ");
    Wire.beginTransmission(i2cAddressBME280);
    if(Wire.endTransmission() == 0){
      i2creadyBME280 = 1;                        // Result I2C scan
      DebugPrintln(3, "ready");
      DebugPrint(3, "Temperature [°C]: ");
      airtemperature = bme.readTemperature();
      DebugPrintln(3, airtemperature);      
      DebugPrint(3, "Air Pressure [mbar]: ");
      airpressure = bme.readPressure() / 100;
      DebugPrintln(3, airpressure);
      DebugPrint(3, "Air Humidity [%]: ");
      airhumidity = bme.readHumidity();
      DebugPrintln(3, airhumidity);
      DebugPrint(3, "Altitude [m]: ");
      altitude = bme.readAltitude(SEALEVELPRESSURE_HPA);
      DebugPrintln(3, altitude);
    }
    else{
      i2creadyBME280 = 0;                        // Result I2C scan
      DebugPrintln(3, "error");
      DebugPrintln(3, "Stop I2C for device BME280");
    }
  }
    
  DebugPrintln(3, "Sensor Type: Sensor Temp 1Wire");
  DebugPrint(3, "Input Pin: GPIO ");
  DebugPrintln(3, ONE_WIRE_BUS);
  DebugPrintln(3, "Value Range [°C]: -55...125");
  DebugPrint(3, "Send Period [ms]: ");
  DebugPrintln(3, SendPeriod);
  DebugPrint(3, "Reduced Send Period [ms]: ");
  DebugPrintln(3, RedSendPeriod);
  DebugPrintln(3, "");

  // Debug info for initialize the EEPROM
  if(empty == 1){
    DebugPrintln(3, "EEPROM config missing, initialization done");
  }
  else{
    DebugPrintln(3, "EEPROM config present");
  }

  // Loading EEPROM config
  DebugPrintln(3, "Loading actual EEPROM config");
  actconf = loadEEPROMConfig();
  DebugPrintln(3, "");

  // Starting access point for update server
  DebugPrint(3, "Access point started with SSID ");
  DebugPrintln(3, actconf.sssid);
  DebugPrint(3, "Access point channel: ");
  DebugPrintln(3, WiFi.channel());
//  DebugPrintln(3, actconf.apchannel);
  DebugPrint(3, "Max AP connections: ");
  DebugPrintln(3, actconf.maxconnections);
  WiFi.mode(WIFI_AP_STA);
  WiFi.softAP(actconf.sssid, actconf.spassword, actconf.apchannel, false, actconf.maxconnections);
  hname = String(actconf.hostname) + "-" + String(actconf.sensorID);
  WiFi.hostname(hname);   // Provide the hostname
  DebugPrint(3, "Host name: ");
  DebugPrintln(3, hname);
  if(actconf.mDNS == 1){
    MDNS.begin(hname);      // Start mDNS service
    MDNS.addService("http", "tcp", actconf.httpport);       // HTTP service
    MDNS.addService("nmea-0183", "tcp", actconf.dataport);  // NMEA0183 dada service for AVnav
  }  
  DebugPrintln(3, "mDNS service: activ");
  DebugPrint(3, "mDNS name: ");
  DebugPrint(3, hname);
  DebugPrintln(3, ".local");
  
  // Sart update server
  httpUpdater.setup(&httpServer);
  httpServer.begin();
  DebugPrint(3, "HTTP Update Server started at port: ");
  DebugPrintln(3, actconf.httpport);
  DebugPrint(3, "Use this URL: ");
  DebugPrint(3, "http://");
  DebugPrint(3, WiFi.softAPIP());
  DebugPrintln(3, "/update");
  DebugPrintln(3, "");

  #include "ServerPages.h"    // Webserver pages request functions
  
  // Connect to WiFi network
  DebugPrint(3, "Connecting WiFi client to ");
  DebugPrintln(3, actconf.cssid);

  // Load connection timeout from configuration (maxccount = (timeout[s] * 1000) / 500[ms])
  maxccounter = (actconf.timeout * 1000) / 500;

  // Wait until is connected otherwise abort connection after x connection trys
  WiFi.begin(actconf.cssid, actconf.cpassword);
  ccounter = 0;
  while ((WiFi.status() != WL_CONNECTED) && (ccounter <= maxccounter)) {
    delay(500);
    DebugPrint(3, ".");
    ccounter ++;
  }
  DebugPrintln(3, "");
  if (WiFi.status() == WL_CONNECTED){
    DebugPrint(3, "WiFi client connected with IP: ");
    DebugPrintln(3, WiFi.localIP());
    DebugPrintln(3, "");
    digitalWrite(ledPin, HIGH);           // LED off (Low activ)
    
    delay(100);
  }
  else{
    WiFi.disconnect(true);                // Abort connection
    DebugPrintln(3, "Connection aborted");
    DebugPrintln(3, "");
    for(int i = 0; i <= 5; i++){
      digitalWrite(ledPin, HIGH);         // LED off (Low activ)
      delay(100);
      digitalWrite(ledPin, LOW);          // LED on (Low activ)
      delay(100);
    }
  }
  
  // Start the NMEA TCP server
  server.begin();
  DebugPrint(3, "NMEA-Server started at port: ");
  DebugPrintln(3, actconf.dataport);
  // Print the IP address
  DebugPrint(3, "Use this URL : ");
  DebugPrint(3, "http://");
  if (WiFi.status() == WL_CONNECTED){
    DebugPrintln(3, WiFi.localIP());
  }
  else{
    DebugPrintln(3, WiFi.softAPIP());
  };

  //*************************************************
  timer1_attachInterrupt(counter);              // Start interrupt routine counter
  timer1_enable(TIM_DIV16, TIM_EDGE, TIM_LOOP); // 80MHz / 16 => 0,2us
  timer1_write(500);                            // Start timer1 100us @ 0,2us
  Timer2.attach_ms(50, buildaverage);           // Start timer all 50ms for average building and reading magnetic sensor
  Timer3.attach_ms(SendPeriod, sendNMEA);       // Data transmission timer for NMEA
  Timer4.attach_ms(RedSendPeriod, sendNMEA2);   // Data transmission timer with reduced frequence for NMEA
  Timer5.attach_ms(500, winddata);              // Start Timer all 500ms for wind data calculation
  
  // Work around for start problem by high wind speed > 7rpm (cyclic boot loop)
  // Start interrupts at first in low level mode and wait 4s then change in falling slope mode 
  attachInterrupt(INT_PIN1, interruptRoutine1, LOW); // Start interrupt for wind speed
  attachInterrupt(INT_PIN2, interruptRoutine2, LOW); // Start Interrupt for wind direction
  delay(4000);
  // Start interrupts in falling slope mode
  attachInterrupt(INT_PIN1, interruptRoutine1, FALLING); // Start interrupt for wind speed
  attachInterrupt(INT_PIN2, interruptRoutine2, FALLING); // Start Interrupt for wind direction

  //**************************************************
   
  // Reset the time variables
  time1 = 0;
  time2 = 0;
  time1_avg = 0;
  time2_avg = 0;

}
 
//*********************************************************************************************
// Loop section
//*********************************************************************************************
void loop() {
  
  httpServer.handleClient();        // HTTP Server-handler for HTTP update server
  MDNS.update();                    // Update DNS info
  
  // Check if a client is connected
  WiFiClient client = server.available();
  int i = 0;
  
  if(!client.connected() && WiFi.status() != WL_CONNECTED){
    digitalWrite(ledPin, LOW);      // LED on (Low activ)
    i = 0;
  }

  // While client is connected or Serial Mode is active
  while ((client.connected() && !client.available()) || (int(actconf.serverMode) == 1)) {

    digitalWrite(ledPin, HIGH);     // LED off (Low activ)
    
    httpServer.handleClient();      // HTTP Server-handler for HTTP update server
    if(actconf.mDNS == 1){
      MDNS.update();                // Update DNS info  
    }  
    
    if ((i == 0) && ((int(actconf.serverMode) == 0) || (int(actconf.serverMode) == 4))) {
      DebugPrintln(3, "Client connected");
      DebugPrintln(3, "");
    }

    // Wind speed and wind direction data calculated via Timer5 interrupt all 500ms

    // Sending NMEA data with normal speed
    if (windspeed_mps > 0 && flag1 == true){     
      i++;
      DebugPrintln(3, "");
      DebugPrint(3, "Send package:");
      DebugPrintln(3, i);
          
      if((int(actconf.serverMode) == 0) || (int(actconf.serverMode) == 1) || (int(actconf.serverMode) == 4)){
         if(int(actconf.windSensor) == 1){
          client.println(sendMWV(1));  // Send NMEA telegrams
          client.println(sendVWR(1));
          client.println(sendVPW(1));
          client.println(sendINF(1));
         }
        if(int(actconf.tempSensor) == 1){
          if(String(actconf.tempSensorType) == "DS18B20"){
            client.println(sendWST(1));
          }
          if(String(actconf.tempSensorType) == "BME280"){
            client.println(sendWSE(1));
          }    
        } 
      }
         
      flashLED(10);                 // Flash LED for data transmission
      flag1 = false;                // Reset the flag
    }


    // Sending NMEA data with reduced speed
    if (windspeed_mps <= 0 && flag2 == true){
      i++;
      DebugPrintln(3, "");
      DebugPrint(3, "Send package:");
      DebugPrintln(3, i);
      
      if((int(actconf.serverMode) == 0) || (int(actconf.serverMode) == 1) || (int(actconf.serverMode) == 4)){
        if(int(actconf.windSensor) == 1){
          client.println(sendMWV(1));  // Send NMEA telegrams
          client.println(sendVWR(1));
          client.println(sendVPW(1));
          client.println(sendINF(1));
        }
        if(int(actconf.tempSensor) == 1){
          if(String(actconf.tempSensorType) == "DS18B20"){
            client.println(sendWST(1));
          }
          if(String(actconf.tempSensorType) == "BME280"){
            client.println(sendWSE(1));
          }    
        }
      }
           
      flashLED(10);                 // Flash LED for data transmission
      flag2 = false;                // Reset the flag
    }

  }
  delay(150);                       // Delay for load reducing
}

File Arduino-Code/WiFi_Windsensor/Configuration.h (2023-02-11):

#ifndef Configuration_h
#define Configuration_h

// Default configuration
// Types 'byte' und 'word' doesn't work!
typedef struct {
  int valid = 9;                            // Number of configuration (Please change when the structure or values are changed)
  int crypt = 0;                            // Activate for critical webside a password query [0 = off|1 = on]
  char password[31] = "12345678";           // Password for critical websides (settings, update and reboot)
  char devname[21] = "Windsensor";          // Device name for web configuration
  char crights[14] = "NoWa (C) 2021";       // Copy rights
  char fversion[6] = "V1.17";               // Firmware version
  char license[12] = "GNU GPL V3";          // License type
  int debug = 3;                            // Debug mode 0=off 1=Errors 2=Errors + Warnings 3=Errors + Warnings + Messages
  char cssid[31] = "MyBoat";                // SSID of WiFi Client
  char cpassword[31] = "S6587rr94P";        // Password of WiFi Client
  int timeout = 30;                         // Connection timeout for client in [s] [30|90|120|150|180|210|240|270|300]
  char sssid[31] = "NoWa";                  // SSID of WiFi Server
  char spassword[31] = "12345678";          // Password of WiFi Server
  int apchannel = 1;                        // Assess Point channel [1...13]
  int maxconnections = 2;                   // Max number of connection for WiFi clients [1...4]
  int mDNS = 1;                             // Using mDNS service [0|1] 0=off, 1=on
  char hostname [31] = "windsensor";        // Hostname WiFi Server
  int dataport = 6666;                      // Port for NMEA data output
  int httpport = 80;                        // Port for HTTP and update pages
  int serverMode = 0;                       // Used server mode [0|1|2|3|4] 0=HTTP (JSON, NMEA), 1=NMEA Serial, 2=MQTT, 3=Diagnostic, 4=Demo (Simulation data)
  int serspeed = 115200;                    // Serial speed in [Bd] 8N1 [300|1200|2400|4800|9600|19200|38400|57600|74880|115200]
  int skin = 0;                             // Skin for websides [0|1|2]
  char instrumentType[8] = "complex";       // Instrument type [simple|complex] simple = Canvas HTML5 , complex = Canvas Steel Series library
  int instrumentSize = 400;                 // Instrument size X * Y [pix] [200|250|300|350|400|450|500|550|600]
  int sensorID = 0;                         // ID of sensor [0...9]
  char windSensorType[10] = "Yachta";       // Type of wind sensor [WiFi 1000|Yachta|Jukolein|Ventus]
  int windSensor = 1;                       // Send wind data 0=off 1=on (WIMWV, WIVWR, WIVPW, PWINF) or Serial or JSON
  char windType[2] = "R";                   // Type of wind R=relative, T=true
  int offset = 0;                           // Offset of wind direction [-180°...+180°]
  int average = 1;                          // Number of values for average building [1...10], for high speed use 1, default use 2
  char speedUnit[5] = "kn";                 // Unit of speed [m/s|km/h|kn|bft] for WIMWV
  int downWindSensor = 1;                   // Send data to down wind 0=off 1=on (WIVPW)
  int downWindRange = 50;                   // Down wind area = 180° +/- downWindRange
  float calslope = 1.0;                     // Speed sensor calibration slope, default 1.0
  float caloffset = 0.0;                    // Speed sensor calibration offset, default 0.0
  char tempSensorType[10] = "DS18B20";      // Type of temperature sensor [Off|DS18B20|BME280]
  int tempSensor = 1;                       // Send data for temp 0=off 1=on (PWWST)
  char tempUnit[2] = "C";                   // Unit of temperature [C|F]
} configData;

#endif

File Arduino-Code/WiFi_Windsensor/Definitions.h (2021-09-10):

#ifndef Definitions_h
#define Definitions_h           

// Passwort settings
String transactionID = String(random(0, 99999999));// Generate a random transaction ID by initialisation
String raw = "";                  // Uncrypted raw data
String crypt = "";                // Crypted data

// EEPROM settings (max size is 4096 Byte)
int cfgStart = 1024;              // Start adress in EEPROM (Attention! The first 32 Byte are used beginning with adress 0)
int sizeEEPROM = 2048;            // Used size of EEPROM 2kB (limit for config file size)

// WLAN client settings
String hname;                     // Hostname
int maxccounter;                  // Maximum number for connection tests until aborted (maxcounter = 60; 60 * 500ms = 30s waiting time)
int ccounter;                     // Actual connection test counter

// Settings for NMEA server 
int SendPeriod = 1000;            // SendPeriod in [ms], Attention! Range is limited [500...2000]
int RedSendPeriod = 3000;         // Reduced send period [ms] when wind speed is zero, range [2000...10000]
volatile bool flag1 = false;      // Flag for data sending (normal speed)
volatile bool flag2 = false;      // Flag for data sending (reduced speed)
volatile bool flag3 = false;      // Flag for zero wind speed detection (true = zero)

// Pin definitions WiFi 1000 wind sensor (default)
int ledPin = 2;                   // LED low activ GPIO 2 (D4)
int INT_PIN1 = 5;                 // Wind speed GPIO 5 (Hall sensor) (D1)
int INT_PIN2 = 4;                 // Wind direction GPIO 4 (Hall sensor) (D2)
int ONE_WIRE_BUS = 12;            // 1Wire bus on GPIO 12 (D6)

// I2C definitions
int i2creadyAS5600 = 0;           // Result of I2C scan for AS5600
byte i2cAddressAS5600 = 0x36;     // I2C address AS5600
int i2creadyBME280 = 0;           // Result of I2C scan for BME280
byte i2cAddressBME280 = 0x76;     // I2C address BME280
#define SEALEVELPRESSURE_HPA (1013.25)// Sea level air pressure


// Measuring data (used in interrupt)
volatile int marker1 = 0;         // Wind speed
volatile int marker2 = 0;         // Wind direction
volatile int marker3 = 0;         // Marker for data saving in a array (sensor 1 and 2 binary switching data)
volatile int scounter = 0;        // Array counter for data saving (sensor1 and 2)
volatile int rpcounter = 0;       // Raw pulse counter for wind direction sensor (per revolution)
volatile int pcounter = 0;        // Pulse counter for wind direction sensor (per revolution)
volatile unsigned long icounter = 0;    // Interrupt counter for rotation detection
volatile unsigned long icounterold = 0; // Old interrupt counter for rotation detektion
volatile unsigned long counter1;  // Wind spped
volatile unsigned long counter2;  // Wind direction
volatile float time1;             // Wind speed (time in [ms] for one rotation)
volatile float time2;             // Wind direction (time in [ms] between wind speed sensor and wind direction sensor)
volatile int average;             // Number of values for average calculation [1...10]
volatile float timearray1[10];    // Array1 of time values (average building)
volatile float timearray2[10];    // Array2 of time values (average building)
volatile int mc = 0;              // Modulo counter
volatile float time1_avg;         // Average wind speed (time in [ms] for one rotation)
volatile float time2_avg;         // Average direction (time in [ms] between wind speed sensor and wind direction sensor)

static float radius = 0.06;       // Radius between center and middle of half hemisphere position (WiFi 1000)
static float radius2 = 0.043;     // Radius between center and middle of half hemisphere position (Yachta|Jukolein)
static float radius3 = 0.055;     // Radius between center and middle of half hemisphere position (Ventus)
static float lamda = 0.3;         // Lambda is a constant for amemometer type with 3 hemisphere, lamda = 0,3
static float pi = 3.14159265358979;   // Pi constant
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

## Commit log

2018-06-29 Upload New File
    [Windsensor5.brd]
2018-12-08 English Version Bauteilliste XLS-source
    [Windsensor_Parts_List.xls]
2018-12-23 Upload New File Assembly_Instruction_Windsensor.doc
2018-12-23 Upload New File Assembly_Instruction_Windsensor.pdf
2019-01-05 Hashes for Arduino binary
2019-04-28 Video inserted
2021-06-20 WiFi Windsensor Source Code
    [Configuration.h]
2021-08-05 New firmware version supports Udos wind sensors
    [Configuration.h]
2021-08-11 New firmware version V1.11
    [Configuration.h]
2021-08-19 New firmware version V1.12
    [Configuration.h]
2021-08-27 New firmware V1.13
    [Configuration.h]
2021-09-10 New firmware V1.14
    [Configuration.h]
2022-08-04 New version V1.16
    [Configuration.h]
2022-08-04 Fix for netgativ wind speed values if using calibration data.
    [Calculation.h]
2022-08-04 Fix the compiling problem with Arduino 1.8.19
2023-02-11 Fix for calibration
    [Configuration.h]
